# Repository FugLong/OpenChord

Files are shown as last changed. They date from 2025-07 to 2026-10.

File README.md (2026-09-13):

# OpenChord

A family of open hardware instruments for harmony and music-making. MIT licensed. **OpenChord M Core** (plugin) is free; the **OpenChord M1** box is what we sell.

**M-series** is MIDI. **S-series** is studio. Numbers are generations.

| Product | What it is | Status |
|---|---|---|
| **[OpenChord M1](m1/)** | MIDI-only chord brain. RP2040 hardware under $100, plus free **OpenChord M Core** (AU/VST3, same engine). | Active — engine / proto / plugin v0 |
| **[OpenChord S1](s1/)** | Studio / portable jambox: synth, tracks, the original dream device. | Later |
| M2 / S2 | Next generations of each line. | Not started |

```
OPENCHORD          OPENCHORD
    m1                 s1
```

## Repo layout

```
m1/                     M1 engine, firmware, plugin, hardware, docs (start here)
s1/                     Reserved for the jambox when it is real
archive/s1-daisy/       Frozen Daisy Seed prototype (do not treat as S1)
LICENSE                 MIT
```

The Daisy Seed project that used to live at the repo root is intact under [`archive/s1-daisy/`](archive/s1-daisy/). It is a prototype archive, not the S1 codebase.

## Start with M1

Read [`m1/docs/goals.md`](m1/docs/goals.md) for the product plan (hardware + free plugin). Hands-on testing is [`m1/proto-rp2040`](m1/proto-rp2040/) (RP2040-Zero USB MIDI, **Pro** mode). Plugin: [`m1/plugin`](m1/plugin/) (**OpenChord M Core**, Pro + Smart). The archived Seed box is parked. Do not edit the archive.

## License

MIT — see [LICENSE](LICENSE).

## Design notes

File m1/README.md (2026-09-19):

# OpenChord M1

MIDI-only chord brain. Keyboard or DAW in, smarter chords out. **Hardware you buy is M1**; the free DAW plugin is **OpenChord M Core**. Same engine.

This is the first product in the OpenChord family. It does not make sound. The portable synth/jambox is [S1](../s1/), later.

**Read first:** [docs/goals.md](docs/goals.md). Then [docs/testbed.md](docs/testbed.md). Chord model: [docs/chord-engine.md](docs/chord-engine.md). Plugin v0: [docs/plugin.md](docs/plugin.md).

## Naming

| Name | What |
|---|---|
| **OpenChord M1** | Hardware (USB MIDI device). Repo folder `m1/`. |
| **OpenChord M Core** | Free AU MIDI FX + VST3 in `m1/plugin/`. |
| **Pro** | Play mode: keyboard roots + chord-type pads |
| **Smart** | Play mode: pads = I–vii + high I, hold to play |

## Status

Engine is in `m1/engine` (including shared `session`). Feel-testing is **`m1/proto-rp2040`** (Pro). Plugin v0 lives in **`m1/plugin`** as **OpenChord M Core** (Pro + Smart). Product firmware is not started. **Rev A PCB** (4-layer HASL, USB-C J1, TRS J2/J3) is the board being fabbed — [`hardware/bom.md`](hardware/bom.md). The Seed proto is parked. Do not edit the archive.

## Tree

```
m1/
  docs/           goals, testbed, chord-engine
  engine/         portable chord logic (the product)
  proto-rp2040/   RP2040-Zero lab harness (USB-C MIDI, Launchkey pads/knobs)
  proto-daisy/    Seed harness (parked; restore OG from archive)
  plugin/         OpenChord M Core — free AU MIDI FX + VST3. Same engine + session as M1 hardware.
  firmware/       Product RP2040 (later)
  hardware/       PCB, enclosure, KiCad libs (locked touch + connectors in hardware/; Alps C219778 = fallback)
```

`s1/` stays empty. `archive/s1-daisy/` stays frozen.

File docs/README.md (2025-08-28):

# OpenChord Documentation

Welcome to the OpenChord documentation! This project is a portable, open-source music creation device built on the Daisy Seed platform.

## 🎨 3D Enclosure Design (WIP)

<div align="center">
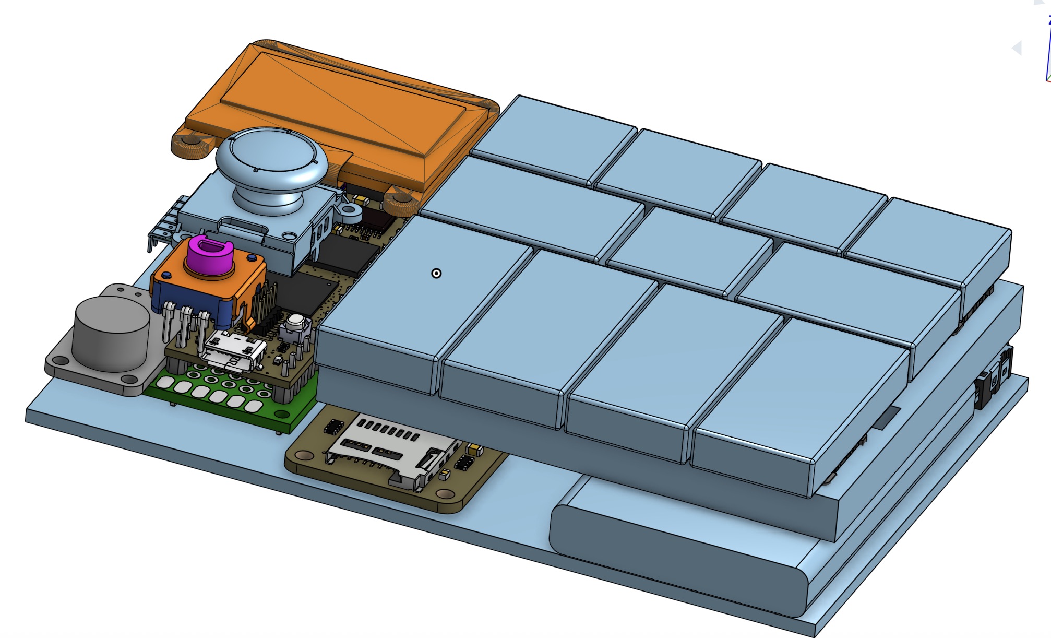
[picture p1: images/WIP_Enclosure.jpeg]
OpenChord 3D Enclosure Design - Work in Progress
  
  <br><br>
  <a href="https://cad.onshape.com/documents/ba31b49b2d69ae60e3c7e665/w/702c47d3131326b0bcdb3b01/e/0e96b76ad6aba8c5e2682321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">
    
  </a>
  <br>
  <em>3D enclosure design in progress - Click the button above to explore the full model</em>
</div>

## 📚 Documentation Structure

### Overview
- **[Project Overview](overview/project_overview.md)** - Complete project description, use cases, features, and more

### Architecture
- **[Firmware Architecture](architecture/firmware_architecture.md)** - Detailed firmware design, track structure, scenes, and plugin system
- **[IO System Architecture](architecture/io_system_architecture.md)** - Comprehensive IO system design and hardware interface management

### Hardware
- **[Pinout Documentation](hardware/pinout.md)** - Detailed pin assignments and hardware connections
- **[Parts List](hardware/partsList.md)** - Complete component list with pricing and purchase links

### Code Organization
- **Co-located Headers**: All header files are now located alongside their corresponding source files
- **Modular Structure**: Clean separation of concerns with dedicated folders for each subsystem

### Development
- **[Development Setup](development/setup.md)** - How to set up your development environment and build the project

## 🎯 Project Goals

- **Portable music creation** - Take your studio anywhere
- **Modular firmware** - Easy to extend and customize
- **Open source** - Community-driven development
- **High-quality audio** - Professional-grade sound processing
- **Intuitive interface** - Consistent, responsive UI

## 📖 Additional Resources

- [Daisy Seed Documentation](https://daisy.audio/)
- [libDaisy GitHub](https://github.com/electro-smith/libDaisy)
- [DaisySP GitHub](https://github.com/electro-smith/DaisySP)

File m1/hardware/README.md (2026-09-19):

# M1 hardware

RP2040 on our PCB, USB-C on the edge. Not a Pico carrier. **Hand-assemble only.** One board, no harnesses.

| Doc | What |
|-----|---|
| [bom.md](bom.md) | Parts + DigiKey/LCSC |
| [support.md](support.md) | Flash / clock / power / USB / MIDI recipe (place before wiring) |
| [switches.md](switches.md) | Gateron LP, direct GPIO (no matrix) |
| [touch.md](touch.md) | Cap strip + trackpad (**IQS572** + **QT2120**) |
| [lib/OLED.md](lib/OLED.md) | OLED pinout / STEP / symbol |
| [lib/TOUCH_ICS.md](lib/TOUCH_ICS.md) | IQS572 + QT2120 EasyEDA/LCSC imports |
| [lib/USB.md](lib/USB.md) | Hroparts TYPE-C-31-M-12 USB-C |
| [lib/TRS.md](lib/TRS.md) | Same Sky SJ1-3523N TRS MIDI |
| [lib/BTN.md](lib/BTN.md) | Panasonic EVQPUC02K edge |
| [lib/MIDI.md](lib/MIDI.md) | Toshiba TLP2361 MIDI IN opto |

Product locks: [`../docs/goals.md`](../docs/goals.md).

## Plan (short)

- **8× Gateron LP** chord pads (hotswap) — mechanical, **one GPIO each** (internal pull-ups; no diodes).
- **IQS572BLQNR** trackpad (color stick XY) + **AT42QT2120** strip only.
- **3× EVQPUC02K** system buttons → GPIO (**roles TBD**). Not capacitive.
- **BOOTSEL** = top tact **TS-1187A** → QSPI_SS through **1 kΩ**, plus **10 kΩ** SS→3V3. No RUN button on rev A.
- Shared **I2C1** on GPIO10/11 (OLED `0x3C`, QT2120 `0x1C`, IQS572 `0x74`; RDY GPIO8, NRST GPIO9). Alps stick = **fallback only**. Pin map: [`support.md`](support.md).
- No SoftPot, no pots, no paid PCBA. Coupon before a later product fab — see [`touch.md`](touch.md).

## Rev A fab (ordering)

| | |
|--|--|
| Size | **118.95 × 63.15 mm** |
| Stack | 4-layer, 1.6 mm, 1 oz. In1 **GND**, In2 **+3.3V**. SMT on **B.Cu**. |
| Finish | **HASL** (not ENIG). Touch = soldermask over copper. |
| Gerbers | [`fab/jlcpcb/`](fab/jlcpcb/) — zip `fab/OpenChordM1-gerbers.zip` (gitignored). Upload that zip. |
| Stencil | **Bottom only**, frameless, custom **160 × 120 mm**, 0.12 mm. No top stencil (`F_Paste` is empty). |
| TRS | SJ1-3523N bushings hang **off** Edge.Cuts so the barrel does not clip FR4. |

## KiCad `lib/`

| Path | Contents |
|---|---|
| `oled.*` | OLED symbol + footprint + STEP ([OLED.md](lib/OLED.md)) |
| `gateron.*` | Gateron LP hotswap ([GATERON.md](lib/GATERON.md)) |
| `easyeda/oc_touch.*` | IQS572 + QT2120 ([TOUCH_ICS.md](lib/TOUCH_ICS.md)) |
| `easyeda/oc_usb.*` | TYPE-C-31-M-12 USB-C ([USB.md](lib/USB.md)); GCT kept in lib |
| `easyeda/oc_trs.*` | Same Sky SJ1-3523N ([TRS.md](lib/TRS.md)) |
| `easyeda/oc_btn.*` | EVQPUC02K edge + TS-1187A BOOT/RUN ([BTN.md](lib/BTN.md)) |
| `easyeda/oc_midi.*` | Toshiba TLP2361 ([MIDI.md](lib/MIDI.md)) |
| `captouch.*` | Generated electrodes (slider/trackpad) — plugin writes here, not into `OpenChordM1/` |
| `lcsc.*` | Alps stick C219778 (**fallback**) |
| `3dshapes/` | OLED STEP |

Nicknames: `oc-oled`, `oc-lcsc`, `oc-gateron`, `oc-touch`, `oc-usb`, `oc-trs`, `oc-btn`, `oc-midi`, `captouch`. RP2040 = KiCad stock `MCU_RaspberryPi` + `Package_DFN_QFN`. Place slider as `captouch:CT_Slider`. Support ICs (flash **W25Q32JVSSIQ** / [C179173](https://www.lcsc.com/product-detail/C179173.html), LDO/ESD/crystal/diode) = KiCad stock — see [`support.md`](support.md).

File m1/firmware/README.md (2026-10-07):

# M1 product firmware

Product RP2040 + TinyUSB MIDI. The rev A image compiles. It has not been flashed and it has not been run: there is no board yet. Do not put this image on an RP2040-Zero. The pins are the product schematic.

`pio run` from this folder builds it. `pio run -t upload` reboots the running board into the ROM bootloader over USB and writes the image. Hold BOOT and plug in if that port is not there.

In this image: USB MIDI named `OpenChord M1`, UART0 MIDI at 31250 on GPIO0 TX / GPIO1 RX (the same notes go out both ports), the eight keyswitches and Prev / Menu / Next (debounced, pressed = low), the IQS572 trackpad and QT2120 strip on the OLED's I2C bus, and the 128×32 OLED drawing the same two lines as the plugin. Flash is the 4 MB W25Q32 with `boot2_w25q080`.

Lab bring-up is [`../proto-rp2040`](../proto-rp2040) on a Zero. The chord logic belongs in `m1/engine`, not here. This folder is the sellable board: USB-C device, UART TRS, Gateron pads, **IQS572** trackpad + **QT2120** strip only, **3× EVQPUC02K** system (roles TBD), OLED. No USB host. No pots. No QT Key/Shift copper. Works with no plugin; the plugin may later push settings over SysEx.

**Match the rev A schematic**, not older docs. Source of truth: [`../hardware/support.md`](../hardware/support.md).

| Bus / pin | As built |
|---|---|
| I²C | **I2C1** on GPIO10 SDA / GPIO11 SCL (not I2C0) |
| OLED / QT / IQS | `0x3C` / `0x1C` / `0x74` on that bus |
| IQS RDY / NRST | GPIO8 / GPIO9 |
| UART0 MIDI | GPIO0 TX / GPIO1 RX @ 31250 |
| Gateron SW1–8 | GPIO 24, 18, 25, 17, 2, 13, 6, 12 |
| EVQ SW9 / SW10 / SW11 | GPIO 4, 5, 3 |
| QT | Slider KEY0–2 only; **CHANGE** unconnected; RESET hard-tied 3V3 |
| BOOTSEL | Not a GPIO — `~QSPI_SS` via R5 1 kΩ; **R30 10 kΩ** SS→3V3 |
| QSPI flash | **W25Q32JVSSIQ** ([C179173](https://www.lcsc.com/product-detail/C179173.html)) 4 MB; `PICO_FLASH_SIZE_BYTES=4*1024*1024`; default `boot2_w25q080` |

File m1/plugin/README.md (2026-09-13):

# OpenChord M Core (plugin)

Free AU MIDI FX + VST3. Same chord engine / session as the **OpenChord M1** hardware. MIDI in → chords out. No audio.

| Name | What |
|---|---|
| **OpenChord M1** | Hardware box (USB MIDI device) |
| **OpenChord M Core** | This free plugin |

**Spec:** [`../docs/plugin.md`](../docs/plugin.md)

## License note

Plugin source is MIT-intended like the rest of the repo. JUCE is fetched via CMake and is GPL/AGPLv3 unless you have a commercial JUCE license. Distributing a binary built this way requires GPL-compatible terms for that binary (or a JUCE license). Source here stays usable either way.

## Build (macOS)

Needs CMake ≥ 3.22, a C++17 compiler, and network once to FetchContent JUCE 8.

```bash
cd m1/plugin
cmake -B build -G Ninja -DCMAKE_BUILD_TYPE=Release
cmake --build build
```

Xcode generator also works: `-G Xcode`.

`COPY_PLUGIN_AFTER_BUILD` installs into:

| Format | Path |
|---|---|
| AU | `~/Library/Audio/Plug-Ins/Components/OpenChord M Core.component` |
| VST3 | `~/Library/Audio/Plug-Ins/VST3/OpenChord M Core.vst3` |

Standalone: `build/OpenChordMCore_artefacts/Release/Standalone/OpenChord M Core.app` (path may vary by generator).

Rescan plugins in Logic / Reaper after the first build. If you previously installed an older **OpenChord M1** plugin bundle, remove it from those folders so only M Core remains.

## Logic (AU MIDI FX)

1. Instrument track → any synth.
2. MIDI FX slot → **OpenChord M Core**.
3. Route Launchkey (or other controller) to this track only.
4. Default map = Launchkey Mini MK4 (pads CC 36–43, stick CC 47/48). Hold Maj, play C → C major. No Type → thru.

## VST3 (Reaper / Ableton / etc.)

VST3 has no MIDI-FX type. This plugin is a silent instrument that outputs MIDI.

- **Reaper:** can use it as MIDI FX on a track.
- **Ableton:** put OpenChord M Core on a MIDI track, set the synth track’s MIDI From to that track (“MIDI To” routing). Do not expect an AU-style MIDI FX slot.

## MIDI Learn

Click a control (short click), then press the pad or move the knob. Binding stores in plugin state with the session. Hold a button to play Type/extra with the mouse. Right-click clears. **Reset map** restores Launchkey defaults. Esc cancels learn.

## Layout

```
m1/plugin/          This JUCE project (OpenChord M Core)
m1/engine/          chord_engine + session (compiled into the plugin; shared with M1 hardware)
```

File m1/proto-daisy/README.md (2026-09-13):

# M1 Seed proto harness

Throwaway firmware for the **original OpenChord box** (Daisy Seed, 11 keys, stick, OLED, USB MIDI). Implements the **new** M1 design on that hardware:

- Incoming USB MIDI note = **root** (**Type** mode; Degree is later)
- Eight chord keys = triad + extras (not I–vii)
- Stick = voicing / in-key color, spring-back HOME
- Chords go back out USB MIDI to the DAW

Pins: [`pin_map.h`](pin_map.h), copied from the archive **drivers**, not `pin_config.h`. **Must not modify `archive/s1-daisy/`.** Restore the OG synth from that archive when this harness is done.

See [docs/testbed.md](../docs/testbed.md) and [docs/chord-engine.md](../docs/chord-engine.md).

## Buttons

| Where | M1 |
|---|-----|
| Bottom 4 | Dim, Min, Maj, Sus |
| Middle 3 | 6, m7, M7 |
| Top INPUT | 9 |
| Top INSTRUMENT | **Key** (hold + a MIDI note sets the key) |
| Top FX | Shift (unused in this build) |
| Top RECORD | panic (CC 123) |

Hold a type, play a note on the keyboard. No type = that note **thrus**. Type + note = chord **replaces** the root (the root is not echoed). Stick lean updates the sounding chord live.

## Build

Daisy toolchain (`arm-none-eabi-gcc`) and libDaisy submodule:

```bash
git submodule update --init archive/s1-daisy/lib/libDaisy
cd m1/proto-daisy
make
```

Binary: `m1/proto-daisy/build/OpenChordM1.bin`

This image is `BOOT_QSPI` so the box's existing USB-stick bootloader can load it.

## Flash (USB stick, same as OG)

The enclosure USB-C is **EXTERNAL** Seed pins 36–37 (`D29`/`D30`). The bootloader looks for a file named `OpenChord.bin`.

```bash
cd m1/proto-daisy
make
./flash_usb.sh "/Volumes/YOURSTICK"
```

Eject the stick, plug it into the **box** USB-C, power cycle. Do not use the Seed's tiny onboard USB for MIDI — that is not the port this firmware listens on.

## Play it

PC is USB host. After flashing, plug the **box USB-C** into the PC. The device should show up as USB MIDI (Daisy name).

Route:

1. Keyboard → DAW/router **into OpenChord** (not also onto the instrument track)
2. OpenChord MIDI out → the instrument / MIDI track

Hold Min, play C on the keyboard → Cm out. Lean the stick for inversion / in-key color. Hold Key + a note to set `C major` etc.

RECORD = all notes off. Restore OG firmware from `archive/s1-daisy` when you are done.

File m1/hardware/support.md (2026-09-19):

# M1 support circuit — as built (rev A schematic)

Companion to [`bom.md`](bom.md). **Source of truth is the KiCad schematic.** This file matches that netlist.

Paths: `OpenChordM1/OpenChordM1.kicad_sch` · `OpenChordM1.kicad_pcb`.

---

## Completeness (on schematic)

| Block | On sch |
|---|---|
| MCU | RP2040 |
| Boot flash | W25Q32JVSSIQ ([C179173](https://www.lcsc.com/product-detail/C179173.html)) QSPI |
| Clock | ABM8-272-T3 + 15 pF ×2 + 1 kΩ on XOUT |
| 3V3 | AP2112K-3.3, EN tied to VIN; 10 µF in/out |
| USB | J1 TYPE-C-31-M-12 ([C165948](https://www.lcsc.com/product-detail/C165948.html)) + USBLC6 + 22 Ω + CC 5.1 kΩ→GND |
| MIDI OUT | Type A: 33 Ω (3V3→Tip), 10 Ω (TX→Ring) |
| MIDI IN | TLP2361 + 220 Ω + 1N4148 + 100 nF |
| Touch | IQS572 + QT2120 + electrodes |
| Display | OLED 0.91" I²C |
| Keys | 8× Gateron LP → GPIO |
| System btns | EVQPUC02K ×3 → GPIO (**roles TBD**) |
| BOOTSEL | TS-1187A + 1 kΩ to `~QSPI_SS`; **10 kΩ pull-up SS→3V3** |
| RUN pin | 10 kΩ → 3V3 (no RUN button on rev A) |
| I²C | **I2C1** GPIO10/11, 4.7 kΩ ×2 |
| RP2040 ties | VREG 1 µF ×2; IO/DVDD 100 nF; **TESTEN→GND**; ADC_AVDD→3V3 |

**Not on rev A:** second USB-C, Alps stick, RUN tact, QT2120 Key/Shift copper, CHANGE GPIO.

**3× EVQ** = system buttons → GPIO. **BOOTSEL** = top tact `TS-1187A-B-A-B` (not the edge PUC). QT2120 SNS is strip only (KEY0–2). Do not wire SNS to buttons.

---

## 1. Power

```
USB VBUS ──► AP2112K VIN ──► +3V3 ──► RP2040 IOVDD / USB_VDD / VREG_IN / ADC_AVDD
                 EN ← VIN                 flash, OLED, QT2120, IQS572 VDDHI, TLP2361 VCC
```

| Cap | Where |
|-----|---|
| C10 10 µF | VBUS at LDO in |
| C11 10 µF | 3V3 at LDO out |
| C8 **1 µF** | RP2040 **VREG_OUT** → both **DVDD** (not 3V3) |
| C9 **1 µF** | RP2040 **VREG_IN** / 3V3 |
| C1, C3–C6, C14 100 nF | 3V3 local (MCU / flash / QT / OLED / opto) |
| C2 **1 µF** | IQS572 **VDDHI** → GND |
| C7 **1 µF** | IQS572 **VREG** (internal regulator **output**) → GND only — not tied to 3V3 |

**TESTEN → GND.**

---

## 2. Crystal

**ABM8-272-T3** on XIN/XOUT: C12/C13 15 pF C0G to GND; **R7 1 kΩ** series on XOUT.

---

## 3. QSPI flash

`W25Q32JVSSIQ` (LCSC [C179173](https://www.lcsc.com/product-detail/C179173.html), SOIC-8 208 mil) → QSPI_SS / SCLK / SD0–3. Same pads/pinout as the 16 Mbit parts. IQ = Quad Enable factory-set (needed for RP2040). Default Pico SDK `boot2_w25q080`. Waveshare RP2040-Plus 4 MB ships this exact MPN. Firmware: `PICO_FLASH_SIZE_BYTES=4*1024*1024`. Do not buy leftover 16 Mbit JV (`W25Q16JVSSIQ` / C131025).

| Ref | Value | Net |
|-----|---|-----|
| **R30** | **10 kΩ** | `~QSPI_SS` → 3V3 (always populated) |
| **R5** | **1 kΩ** | `~QSPI_SS` → SW13 pad 3 |
| **SW13** | TS-1187A | pad 1 → GND; pad 3 → R5. Commons are **top 1+2 / bottom 3+4**. Pads 2 and 4 NC on sch. |

**RUN:** R6 10 kΩ → 3V3. No RUN button.

---

## 4. USB (one port)

**J1** Hroparts `TYPE-C-31-M-12` ([C165948](https://www.lcsc.com/product-detail/C165948.html)) on **B.Cu**, board edge. Per [`lib/USB.md`](lib/USB.md): DP1↔DP2, DN1↔DN2; **USBLC6**; **R3/R4 22 Ω**; CC **R1/R2 5.1 kΩ→GND** (do not tie CC1 to CC2); VBUS→LDO; SBU NC.

---

## 5. MIDI Type A

[`lib/TRS.md`](lib/TRS.md) + [`lib/MIDI.md`](lib/MIDI.md). UART0: **GPIO0 TX / GPIO1 RX**.

**OUT (J2):** Tip ← R12 33 Ω ← 3V3; Ring ← R11 10 Ω ← TX; Sleeve GND.

**IN (J3 + U9 TLP2361):** Tip → R10 220 Ω → AN; Ring → CAT; VO → RX; VCC=3V3 + C14 100 nF; D1 1N4148 reverse across LED.

Place the jacks so the **metal bushing is past Edge.Cuts** (plastic body + pins on FR4). Boss holes are mechanical, no net.

---

## 6. I²C — **I2C1** (not I2C0)

RP2040 mux: **GPIO10 = I2C1 SDA**, **GPIO11 = I2C1 SCL**. Firmware must use **I2C1**.

| Device | Address | Notes |
|---|---|---|
| OLED DS1 | `0x3C` | Module must be **GND / VCC / SCL / SDA** |
| QT2120 U4 | `0x1C` | MODE→GND, RESET→3V3, CHANGE open |
| IQS572 U3 | `0x74` | **RDY → GPIO8** (required); **NRST → GPIO9** |

Pull-ups **R8/R9 4.7 kΩ** to 3V3.

---

## 7. Touch series R

| Ref | Value | Net |
|-----|---|-----|
| **R13–R15** | **10 kΩ** | QT2120 KEY0–2 ↔ strip E1–E3 |
| **R16–R29** | **1 kΩ** | IQS572 Rx0–6 / Tx0–6 ↔ trackpad silk Rx1–7 / Tx1–7 |

Unused IQS Rx7 / Tx7 / Tx8 and unused QT KEY3–11 left open.

Keepout on internal planes covers **sense** copper (KEY0–2 / trackpad diamonds). Slider **GND end chevrons** (U2 pads 4–5) may sit outside keepout on purpose.

---

## 8. GPIO map (live schematic)

| GPIO | Function |
|---|---|
| 0 | MIDI OUT UART0 TX |
| 1 | MIDI IN UART0 RX |
| 2 | SW5 Gateron |
| 3 | SW11 EVQ |
| 4 | SW9 EVQ |
| 5 | SW10 EVQ |
| 6 | SW7 Gateron |
| 7 | unused |
| 8 | IQS572 RDY |
| 9 | IQS572 NRST |
| 10 | I2C1 SDA |
| 11 | I2C1 SCL |
| 12 | SW8 Gateron |
| 13 | SW6 Gateron |
| 14–16 | unused |
| 17 | SW4 Gateron |
| 18 | SW2 Gateron |
| 19–23 | unused |
| 24 | SW1 Gateron |
| 25 | SW3 Gateron |
| 26–29 | open (ADC spare / Alps fallback) |

Gateron / EVQ: one pole → GPIO (MCU internal pull-up), other → GND. Pressed = low.

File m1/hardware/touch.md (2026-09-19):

# M1 capacitive front panel (**locked**)

Locks / fallbacks: [`../docs/goals.md`](../docs/goals.md). Parts: [`bom.md`](bom.md).

## Locked ICs

| Role | MPN | DigiKey | Pkg | Bus |
|---|-----|---|-----|-----|
| **Trackpad** (color stick) | **IQS572BLQNR** | [7165004](https://www.digikey.com/en/products/detail/azoteq-pty-ltd/IQS572BLQNR/7165004) | QFN-28 **4×4** (**0.5 mm** pitch) | I²C **`0x74`**, needs **RDY** GPIO |
| **Strip** (strum / sparkle) | **AT42QT2120-XUR** | [XUR](https://www.digikey.com/en/products/detail/microchip-technology/AT42QT2120-XUR/3678735) (TSSOP-20, tape/reel — prefer) · [MMHR](https://www.digikey.com/en/products/detail/microchip-technology/AT42QT2120-MMHR/3678733) (VQFN-20 alt) | same die | I²C **`0x1C`** |

**One of each.** Not 2× QT2120. IQS572 = XY trackpad. QT2120 = **strip only** (SNS0–2). System buttons = mechanical EVQ → GPIO (**roles TBD**) — not capacitive.

Addresses differ → **OLED (`0x3C`) + QT2120 + IQS572 share I2C1** (GPIO10 SDA / GPIO11 SCL). Pull-ups once (**R8/R9 4.7 kΩ**). IQS572 **RDY → GPIO8** (required). **NRST → GPIO9**. QT2120 **CHANGE** is open (poll I²C).

Fall back: Alps stick (C219778) if trackpad feel fails. Chord pads stay **Gateron LP**. System buttons stay EVQ.

---

## What each chip does

### IQS572 — trackpad (stick)

Mutual-cap **Tx columns + Rx rows**. Copper = diamond matrix from the captouch plugin (or hand layout per Azoteq AZD068). Chip outputs **XY** (+ gestures) over I²C. Firmware maps position → **8 color seats + HOME** (center / no-touch deadzone). Up to **9×8** channels; use a small stick-sized grid (e.g. 5×4 / 6×5), leave unused Tx/Rx unconnected per datasheet rules.

### AT42QT2120 — strip only

Self-cap. **Slider** on SNS0–2 = three interleaved electrodes → continuous **0–255** (strum / sparkle). Unused SNS left open. System buttons are **not** on this chip.

```
Finger → cover opening + soldermask (rev A HASL; not ENIG)
  trackpad diamonds → Tx/Rx (+ 1 kΩ R16–R29) → IQS572 → I2C1 → RP2040
  strip triangles    → SNS0–2 (+ 10 kΩ R13–R15) → QT2120 → I2C1 → RP2040
  3× system EVQ      → GPIO (roles TBD)
```

## Soldermask vs gold

| Finish | Look | Fab |
|---|---|-----|
| **HASL + mask over pads** (rev A proto) | Pad-shaped bumps in board color | What we ordered |
| **ENIG + mask open** | Gold frets / pad outlines | Later SKU only if feel needs gold |

## Cover

3D-printed cover with openings over **trackpad** and **strip**. System EVQs get their own openings (not copper pads).

## Layout notes

- Keepout under **sense** copper on internal GND/PWR planes; ground pour around (not under) electrodes. Slider **GND end chevrons** (U2 pads 4–5) may sit outside keepout so parts can share that area — that is intentional.
- IQS572 and QT2120 **close** to their electrodes; short sense traces; **series R on every sense line**:
  - Strip: **R13–R15 10 kΩ** (QT2120 datasheet Rs 4.7–20 kΩ)
  - Trackpad 7×7: **R16–R29 1 kΩ** — electrode silk Rx1–7/Tx1–7 → chip **Rx0–6 / Tx0–6** (Rx7, Tx7, Tx8 NC)
- Decoupling: IQS572 **C2 1 µF on VDDHI**, **C7 1 µF on VREG** (VREG is the internal regulator output — cap to GND only). Optional 100 pF across C7 skipped on rev A.
- IQS572 is **NRFND** at Azoteq but DigiKey-stocked — acceptable for M1; do not redesign around vaporware 7211E.

---

## Eval / breakouts (buy before fab)

### IQS572 (preferred → fallback)

1. **Official:** [IQS572EV02](https://www.azoteq.com/product/iqs572-b000/) Arduino-shield trackpad (8×8) — order from Azoteq / Seltech if DigiKey empty. Pair with **CT210A** or **DS200** USB streamer + [IQS5xx-B000 GUI](https://www.azoteq.com/).
2. **Ready module (best buy):** [TPS43-201A-S](https://www.digikey.com/en/products/detail/azoteq-pty-ltd/TPS43-201A-S/7164940) — 43×40 mm pad with **IQS572 on board** (FPC). Wire to Zero; prove XY + seat mapping before any coupon.
3. **DIY chip on adapter:** only if you cannot get TPS43/EV02 — need a **QFN-28 4×4 / 0.5 mm → DIP** adapter (not 0.4 mm; Chip Quik **IPC0042 is 0.4 mm and wrong**). Prefer coupon with the IC soldered direct.

### AT42QT2120

1. **[Touchy Subject](https://www.lectronz.com/products/touchy-subject)** — Qwiic/STEMMA QT2120 breakout (hand-solderable TSSOP design; open source).
2. **Zio Qwiic AT42QT2120** (Smart Prototyping) — module + optional wheel/key panels.
3. **DIY:** buy **AT42QT2120-XUR** (TSSOP-20), dead-bug or TSSOP→DIP adapter onto a strip coupon. Product PCB can still use MMHR if preferred.

### Host for bring-up

RP2040-Zero (`m1/proto-rp2040`) or Arduino Uno (EV02 shield). Log XY / slider / keys over USB serial before trusting the product board.

---

## Pre-fab testing (expensive PCBs — earn one fab)

Cap copper is easy to draw and easy to **feel** wrong (dead zones, palm hits, jitter, cover air gap). Treat feel as a **coupon problem**, not a full-board problem.

### Phase 0 — silicon + software (no custom PCB)

| Test | How | Pass |
|---|-----|---|
| IQS572 talks | EV02 / TPS43 / adapter → I2C `0x74`, RDY polled, XY streams | Stable XY at 3.3 V |
| QT2120 talks | Breakout → I2C `0x1C`, slider 0–255, keys debounce | Clean lift/touch |
| Stick mapping | Firmware: XY → polar or 8 seats + HOME deadzone | Matches gesture lock in goals |
| Strip mapping | Slider → strum / sparkle | Useful in Smart; no stuck values |

### Phase 1 — **cheap coupons** (JLCPCB ~$5–15, 2–5 pcs)

Order **tiny boards**, not the product:

1. **Trackpad coupon:** IQS572 footprint + diamond matrix sized like the final stick + cover stack (same overlay thickness you will ship) + I2C/RDY header to Zero.
2. **Strip coupon:** QT2120 + interleaved strip + cover opening (no Key/Shift copper).
3. Optional: one **combo coupon** (both ICs) once each alone passes.

Sweep **one variable per coupon** if possible: pitch / overlay / mask-vs-ENIG. Do **not** change five things between fabs.

### Phase 2 — checklist before product Gerbers

- [ ] Trackpad: all seats reachable; HOME center reliable; no palm on rim while resting hand
- [ ] Strip: end-to-end travel; no dead third; works with intended cover
- [ ] System EVQs: clean GPIO presses; no ghost with trackpad palm
- [ ] EMI: USB plugged, MIDI TRS connected, OLED on — touch still stable
- [ ] I2C: OLED + both touch ICs on one bus at once (addr `0x3C` / `0x1C` / `0x74`)
- [ ] Power: brown-out / plug cycle; IQS572 RDY still sane after reset
- [ ] Mechanical: cover openings align; finger never on bare copper; edge buttons reachable
- [ ] Alps stick footprint DNP fallback still OK if trackpad fails

### Phase 3 — product PCB

Only after Phase 1–2 pass. First product fab is **assembly + layout** risk (USB, TRS, Gateron, RP2040), not “will capacitive touch exist.”

**Truth:** you will not get “zero respins” by staring at KiCad. You get close by **paying for coupons** and freezing electrode geometry before the big board.

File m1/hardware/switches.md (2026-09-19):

# M1 switches — Gateron LP, direct GPIO

Parts: [`bom.md`](bom.md). Feel: [`../docs/goals.md`](../docs/goals.md). Cap front: [`touch.md`](touch.md).

## Socket family

**Gateron LP KS-27 / KS-33** only (2 electrical pins). **Not** MX (CPG1511). **Not** Choc. Sockets from Gateron / keeb shops — not DigiKey.

KS-27 and KS-33 share a compatible footprint. Wrong family = scrap board.

## Stack-up

```
[keycap] [LP switch]  ← press from top
[plate]
── PCB top ──  NPTH for legs
── PCB bottom ──  LP hotswap socket (SMD)
```

Solder sockets on the **bottom**. Press switches in after plate. Coupon 1–2 keys before full fab.

Footprints **in-repo** (ai03 MX_V2, MIT): see [`lib/GATERON.md`](lib/GATERON.md).

- Schematic: **`oc-gateron:SW_Gateron_LP`**
- PCB: **`oc-gateron:Gateron-KS33-Hotswap-1U`** — then **flip** so socket is on **B.Cu** (bottom)
- Backup solder-only: `Gateron-KS33-Solderable-1U`
- 3D: socket + switch (`Gateron-KS33-Socket.step`, `Gateron-KS33-Switch.step`) — see [`lib/GATERON.md`](lib/GATERON.md)

## Wiring — direct GPIO (no matrix)

Eight pads → **eight GPIOs**. One switch pin → GPIO, other → GND.

- Enable **internal pull-up** on each key GPIO (~50–80 kΩ on RP2040). No external pull-up resistors.
- Pressed = low. Firmware debounce.
- **No diodes** — ghosting is a matrix problem; each key has its own line.
- Multi-hold works.

**3× system EVQPUC02K** → GPIO (internal pull-up). Roles **TBD** — not capacitive, not Gaterons. **BOOTSEL** is a separate strap on QSPI_SS (see [`support.md`](support.md)).

### Pad map (firmware)

| Pad | Pro | Smart |
|-----|-----|---|
| 0–3 | Dim Min Maj Sus | I ii iii IV |
| 4–7 | 6 m7 M7 9 | V vi vii I↑ |

Physical layout is still a **2×4** cluster; numbering is firmware-defined.

### GPIO map (rev A schematic)

See [`support.md`](support.md) §8 for the full table. Firmware must use **I2C1** (GPIO10/11), not I2C0.

| Function | GPIO |
|---|---|
| KEY (SW1–8 Gateron) | 24, 18, 25, 17, 2, 13, 6, 12 |
| SYS (SW9, SW10, SW11 EVQ) | 4, 5, 3 |
| I2C1 SDA/SCL | 10 / 11 — OLED `0x3C` + QT2120 strip @ `0x1C` + IQS572 @ `0x74` |
| IQS572_RDY / NRST | 8 / 9 |
| UART0 TX/RX (MIDI) | 0 / 1 |
| BOOTSEL | **Not a GPIO** — TS-1187A + **R5 1 kΩ** on **QSPI_SS**, **R30 10 kΩ** SS→3V3 |
| STICK_X/Y | **Only if Alps fallback** — ADC on GPIO26–29 |

QT2120 **CHANGE** is unconnected. Spare: GPIO7, 14–16, 19–23.

## Layout

2×4 left-hand cluster; thumb **trackpad** (or Alps stick fallback); touch **strip** on a free edge; **3× system EVQs** (roles TBD); USB-C on edge; TRS rear/side; bottom keepout for case.

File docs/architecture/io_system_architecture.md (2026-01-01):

# OpenChord IO System Architecture

[← Back to Documentation](../README.md)

## Overview

This document outlines the IO system architecture for OpenChord, designed to handle all hardware components in a clean, modular, and maintainable way. The system follows Daisy Seed best practices and provides a unified interface for all input/output operations.

## Design Principles

1. **Modularity**: Each IO component type is handled by a dedicated manager class
2. **Unified Interface**: Common patterns for all input types (digital, analog, serial)
3. **Daisy-Native**: Leverages Daisy Seed's built-in peripherals and patterns
4. **Performance**: Efficient polling and interrupt-driven approaches where appropriate
5. **Extensibility**: Easy to add new IO components without breaking existing code
6. **Error Handling**: Robust error detection and recovery for hardware issues
7. **Centralized Configuration**: All pin assignments defined in one place (`pin_config.h`)

## System Architecture

```
┌─────────────────────────────────────────────────────────────┐
│                    IO Manager (Main Coordinator)            │
├─────────────────────────────────────────────────────────────┤
│  ┌─────────────┐ ┌─────────────┐ ┌─────────────┐ ┌─────────┐ │
│  │   Digital   │ │   Analog    │ │   Serial    │ │ Display │ │
│  │   Manager   │ │   Manager   │ │   Manager   │ │ Manager │ │
│  └─────────────┘ └─────────────┘ └─────────────┘ └─────────┘ │
├─────────────────────────────────────────────────────────────┤
│  ┌─────────────┐ ┌─────────────┐ ┌─────────────┐ ┌─────────┐ │
│  │   Storage   │ │   Audio     │ │   MIDI      │ │   UI    │ │
│  │   Manager   │ │   Manager   │ │   Manager   │ │ Manager │ │
│  └─────────────┘ └─────────────┘ └─────────────┘ └─────────┘ │
└─────────────────────────────────────────────────────────────┘
```

## Component Managers

### 1. Digital IO Manager
Handles all digital inputs and outputs including buttons, encoder, and control signals.

**Components:**
- **Key Matrix (4x3)**: 11 keys using 7 pins (4 rows, 3 columns)
- **Rotary Encoder**: 2 pins for quadrature, 1 for button (optional)
- **Joystick Button**: 1 pin for digital input
- **Audio Input Switch**: 1 pin for TRS/line input selection
- **Status LEDs**: 4 pins for visual feedback (if implemented)

**Features:**
- Matrix scanning with debouncing
- Encoder quadrature decoding with acceleration
- Button state tracking (pressed, held, released)
- LED brightness control via PWM

### 2. Analog IO Manager
Handles all analog inputs including potentiometers, joystick axes, and sensors.

**Components:**
- **Volume Potentiometer**: ADC0 (Pin 22)
- **Joystick X-Axis**: ADC2 (Pin 24)
- **Joystick Y-Axis**: ADC3 (Pin 25)
- **Microphone Input**: ADC1 (Pin 23)
- **Battery Monitor**: ADC4 (Pin 26)

**Features:**
- Automatic ADC configuration and calibration
- Noise filtering and smoothing
- Calibration for joystick dead zones
- Battery voltage monitoring with low-battery detection
- Self-initialization using centralized pin configuration

### 3. Serial IO Manager
Handles all serial communication including MIDI, display, and storage.

**Components:**
- **SPI Display**: Pins 8-11 (SPI1)
- **SD Card**: Pins 2-7 (SDMMC1)
- **UART MIDI**: Pins 12-13 (UART4)

**Features:**
- SPI display driver with double buffering
- SD card file system management
- MIDI UART with proper timing
- Error handling and recovery

### 4. Display Manager
Specialized manager for the OLED display with advanced UI features.

**Features:**
- Double buffering for smooth animations
- Font rendering and text layout
- Graphics primitives (lines, circles, rectangles)
- UI state management
- Plugin-driven custom displays

### 5. Storage Manager
Handles SD card operations and file management.

**Features:**
- File system abstraction
- Audio file I/O
- Configuration storage
- Project file management
- Error recovery and corruption detection

## Implementation Strategy

### Phase 1: Core Infrastructure
1. **IO Manager Base Class**: Abstract interface for all managers
2. **Digital Manager**: Button matrix, encoder, basic digital I/O
3. **Analog Manager**: ADC setup, basic analog reading
4. **Error Handling**: Centralized error reporting and recovery

### Phase 2: Communication Systems
1. **Serial Manager**: SPI, UART, and SDMMC initialization
2. **Display Manager**: Basic OLED driver and text rendering
3. **Storage Manager**: SD card initialization and basic file operations

### Phase 3: Advanced Features
1. **Enhanced Digital**: LED control, advanced button features
2. **Enhanced Analog**: Calibration, filtering, advanced processing
3. **UI Integration**: Plugin-driven display system
4. **Performance Optimization**: Interrupt-driven updates where possible

## Class Structure

### IO Manager (Main Coordinator)
```cpp
class IOManager {
public:
    // Core lifecycle
    void Init(daisy::DaisySeed* hw);
    void Update();
    void Shutdown();
    
    // Manager access
    DigitalManager* GetDigital() { return digital_; }
    AnalogManager* GetAnalog() { return analog_; }
    SerialManager* GetSerial() { return serial_; }
    DisplayManager* GetDisplay() { return display_; }
    StorageManager* GetStorage() { return storage_; }
    
    // System status
    bool IsHealthy() const;
    const SystemStatus& GetStatus() const;
    
private:
    DigitalManager* digital_;
    AnalogManager* analog_;
    SerialManager* serial_;
    DisplayManager* display_;
    StorageManager* storage_;
    SystemStatus status_;
};
```

### Digital Manager
```cpp
class DigitalManager {
public:
    // Key matrix
    bool IsKeyPressed(int row, int col) const;
    bool WasKeyPressed(int row, int col) const;
    const KeyMatrixState& GetKeyMatrix() const;
    
    // Encoder
    int GetEncoderValue() const;
    float GetEncoderDelta() const;
    bool IsEncoderButtonPressed() const;
    
    // Joystick button
    bool IsJoystickButtonPressed() const;
    bool WasJoystickButtonPressed() const;
    
    // Audio switch
    bool IsAudioInputSwitched() const;
    
    // LEDs
    void SetLED(int led, bool state);
    void SetLEDBrightness(int led, float brightness);
    
private:
    KeyMatrix key_matrix_;
    Encoder encoder_;
    Button joystick_button_;
    Button audio_switch_;
    LEDArray leds_;
};
```

### Analog Manager
```cpp
class AnalogManager {
public:
    // Volume control
    float GetVolume() const;
    float GetVolumeNormalized() const;
    
    // Joystick
    void GetJoystick(float* x, float* y) const;
    float GetJoystickX() const;
    float GetJoystickY() const;
    
    // Microphone
    float GetMicrophoneLevel() const;
    bool IsMicrophoneClipping() const;
    
    // Battery
    float GetBatteryVoltage() const;
    float GetBatteryPercentage() const;
    bool IsLowBattery() const;
    
    // Calibration
    void CalibrateJoystick();
    void CalibrateVolume();
    
private:
    daisy::AdcChannelConfig adc_configs_[5];
    AnalogInput volume_;
    AnalogInput joystick_x_;
    AnalogInput joystick_y_;
    AnalogInput microphone_;
    AnalogInput battery_;
};
```

## Pin Assignment Summary

| Function | Daisy Pin | STM32 Pin | Manager | Notes |
|---|---|---|---|---|
| **Key Matrix** | 27-33 | Various | Digital | 4x3 matrix, 7 pins |
| **Encoder** | 34-35 | Various | Digital | Quadrature A/B |
| **Joystick Button** | 14 | PB6 | Digital | GPIO input |
| **Audio Switch** | 15 | PB7 | Digital | GPIO input |
| **Volume Pot** | 22 | PC0 | Analog | ADC0 |
| **Joystick X** | 24 | PB1 | Analog | ADC2 |
| **Joystick Y** | 25 | PA7 | Analog | ADC3 |
| **Microphone** | 23 | PA3 | Analog | ADC1 |
| **Battery** | 26 | PA6 | Analog | ADC4 |
| **Display SPI** | 8-11 | Various | Serial | SPI1 |
| **SD Card** | 2-7 | Various | Serial | SDMMC1 |
| **MIDI UART** | 12-13 | PB8-PB9 | Serial | UART4 |

## Error Handling Strategy

### Hardware Fault Detection
- **ADC Failures**: Detect out-of-range values, implement fallback values
- **Digital Glitches**: Debouncing, state validation, error counters
- **Communication Errors**: Timeout detection, retry mechanisms
- **Storage Issues**: Corruption detection, backup/restore mechanisms

### Recovery Mechanisms
- **Automatic Retry**: Configurable retry counts for transient failures
- **Fallback Modes**: Degraded operation when components fail
- **User Notification**: Clear error messages and status indicators
- **Logging**: Persistent error logs for debugging

## Performance Considerations

### Update Frequencies
- **Digital I/O**: 1kHz (1ms) for responsive button handling
- **Analog I/O**: 100Hz (10ms) for smooth control response
- **Display**: Adaptive refresh rate for power optimization:
  - **Idle**: 1Hz (1s) - minimal updates for power savings
  - **Low**: 2Hz (500ms) - reduced updates during low activity
  - **Normal**: 10Hz (100ms) - standard UI updates (sufficient for smooth operation)
  - **Active**: 20Hz (50ms) - responsive updates during user interaction
- **Storage**: On-demand for file operations
- **MIDI**: Real-time for low-latency performance

**Note**: Display refresh rates are optimized for battery-powered operation. The adaptive system balances visual quality with power consumption, automatically adjusting based on system activity.

### Memory Management
- **Static Allocation**: Pre-allocate buffers to avoid fragmentation
- **Pool Management**: Efficient memory pools for dynamic objects
- **Cache Optimization**: Minimize memory access patterns
- **DMA Usage**: Use DMA for SPI and audio operations where possible

## Integration with Other Systems

### Audio System
The IO system provides volume control and other analog inputs to the audio engine. The `VolumeManager` coordinates between the `AnalogManager` and `AudioEngine` to provide sophisticated volume scaling.

### MIDI System
Digital inputs (key matrix, encoder) and analog inputs (joystick) can be mapped to MIDI control changes, notes, and other musical events.

### Plugin System
The IO system is designed to integrate with a plugin architecture, allowing plugins to:
- Register custom input handlers
- Define custom control mappings
- Create custom UI displays
- Handle specialized hardware

## Conclusion

This IO system architecture provides a solid foundation for OpenChord's hardware interface needs. The modular design ensures maintainability and extensibility while following Daisy Seed best practices. The phased implementation approach allows for incremental development and testing, ensuring each component is robust before moving to the next phase.

The system is designed to handle all current hardware requirements while providing clear paths for future enhancements and plugin integration.

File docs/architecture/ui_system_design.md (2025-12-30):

# UI System Design

[← Back to Documentation](../README.md)

## Overview

The OpenChord UI system provides a consistent, modular interface for navigating settings, viewing information, and controlling the device. It follows a layered approach with a permanent system bar and plugin-driven content area.

## Core Principles

1. **Always-visible system information** - Battery, track, active plugin/context shown in persistent bars
2. **Plugin-driven content** - Plugins can render their own UI in the content area
3. **Consistent navigation** - Same controls work across all contexts
4. **Modal settings access** - Quick access to plugin settings without leaving performance mode
5. **Clean separation** - System UI (bars) vs Content UI (plugin-driven)

## UI Layout

```
┌─────────────────────────────────────┐
│ SYSTEM BAR (permanent, always on)   │  ← Battery %, Track name, Current context
├─────────────────────────────────────┤
│                                     │
│                                     │
│    CONTENT AREA                     │  ← Plugin-driven or system UI
│    (128x48 pixels)                  │  ← Can be controlled by any plugin
│                                     │
│                                     │
├─────────────────────────────────────┤
│ STATUS BAR (optional, contextual)   │  ← Additional info, hints, shortcuts
└─────────────────────────────────────┘
```

**Display specs:**
- Total: 128x64 pixels (OLED SSD1306)
- System Bar (top): 128x8 pixels (1 line)
- Content Area: 128x48 pixels
- Status Bar (bottom): 128x8 pixels (optional, contextual)

## System Bars

### Top System Bar (Always Visible)

Displays:
- **Left**: Battery percentage (e.g., "85%") or charging indicator
- **Center**: Current track name/number (e.g., "Track 1" or "Chord Mode")
- **Right**: Current context/mode indicator
  - Normal: "-" or empty
  - Settings mode: "SETTINGS" or plugin name
  - Menu mode: "MENU"
  - Debug: "DEBUG"

### Bottom Status Bar (Contextual)

Only shows when relevant:
- Navigation hints: "↑↓ nav  ◄► change"
- Active plugin name: "Chord Mapping"
- Parameter value: "Key: C Major"
- Empty in normal operation mode

## UI States / Modes

### 1. Normal Performance Mode (Default)

**Behavior:**
- System bar shows track and battery
- Content area shows plugin's default view (e.g., chord name for chord mapping)
- Bottom bar is empty or minimal

**Navigation:**
- No special navigation active
- Buttons control music/performance
- Joystick controls performance features

### 2. Menu Mode

**Activation:**
- **Tap INPUT button** - Opens/closes main menu
- **Press INPUT button** - Navigate to Input Stack settings
- **Press INSTRUMENT button** - Navigate to Instrument settings
- **Press FX button** - Navigate to FX settings

**Behavior:**
- System bar shows current context (e.g., "Input", "Instrument", "FX", or "Menu")
- Content area shows menu structure or settings UI
- Bottom bar shows navigation hints

**Navigation:**
- **Joystick UP/DOWN**: Navigate menu items/settings list
- **Joystick RIGHT/Encoder rotate**: Enter submenu OR change parameter value
- **Joystick LEFT**: Go back/exit current level
- **Encoder rotate**: Change selected parameter value (real-time, no save needed)
- **Encoder press**: Toggle boolean/cycle enum parameter
- **INPUT button tap**: Toggle menu open/closed (returns to normal mode)

**Key Principle: Settings change in real-time**
- No "save" action needed - encoder rotation immediately updates values
- Changes take effect immediately
- Pressing menu buttons (INPUT/INSTRUMENT/FX) navigates to their top-level settings

**Menu Structure:**
```
Main Menu (tap INPUT):
├─ Track 1
│  ├─ Input Stack (press INPUT)
│  │  ├─ Chord Mapping
│  │  │  ├─ Key: C Major          ← Encoder rotates to change
│  │  │  ├─ Mode: Ionian          ← Encoder rotates to cycle
│  │  │  └─ Joystick Preset: Classic
│  │  └─ (other input plugins...)
│  ├─ Instrument (press INSTRUMENT)
│  │  └─ (instrument settings...)
│  └─ Effects (press FX)
│     └─ (effect settings...)
├─ Track 2
├─ Scene Management
├─ System Settings
│  ├─ MIDI Configuration
│  ├─ Display Settings
│  └─ Calibration
└─ Debug View
```

**Example Settings UI (when in Input Stack menu):**
```
┌─────────────────────────────────┐
│ 85%  Track 1           Input    │
├─────────────────────────────────┤
│ Chord Mapping                   │
│                                 │
│ > Key: C Major                  │
│   Mode: Ionian                  │
│   Joystick Preset: Classic      │
│                                 │
├─────────────────────────────────┤
│ ↑↓ nav  ◄► change  INPUT: back │
└─────────────────────────────────┘
```

**Navigation Flow Example:**
1. Normal mode → Tap INPUT → Opens main menu
2. Main menu → Press INPUT button → Enters "Input Stack" context
3. Input Stack → Joystick DOWN → Navigate to "Chord Mapping"
4. Chord Mapping → Joystick RIGHT → Enter Chord Mapping settings
5. Settings → Encoder rotate → Change "Key" value in real-time
6. Settings → INPUT tap → Go back one level (to Input Stack list)
7. Input Stack → INPUT tap → Go back to main menu
8. Main menu → INPUT tap → Close menu, return to normal mode

### 4. Plugin-Defined UI Mode

**Activation:**
- Plugin requests UI control (via interface)
- Can be activated from settings or automatically

**Behavior:**
- System bar still visible (always)
- Content area fully controlled by plugin
- Plugin can render custom graphics, menus, etc.

**Navigation:**
- Controlled by plugin (but should respect standard conventions)
- Plugin should handle INPUT button for exit/back

## Input Controls Mapping

### Normal Mode
- **Buttons 1-7**: Musical input (chords, notes, etc.)
- **Joystick**: Performance control (chord variations, etc.)
- **Encoder**: Usually inactive (or assigned to volume/filter)

### Menu Mode
- **INPUT button tap**: Toggle menu open/closed
- **INPUT button press (in menu)**: Navigate to Input Stack settings
- **INSTRUMENT button press (in menu)**: Navigate to Instrument settings  
- **FX button press (in menu)**: Navigate to FX settings
- **Joystick UP/DOWN**: Navigate list/options
- **Joystick LEFT**: Go back/exit current level
- **Joystick RIGHT**: Enter submenu/select item
- **Encoder rotate**: Change parameter value (real-time, immediate effect)
- **Encoder press**: Toggle/cycle (boolean/enum parameters)

### Record Button
- **Normal mode**: Record/playback control (track-specific)
- **Settings/Menu mode**: Cancel/discard changes (if applicable)
- **Hold with INPUT**: Toggle debug screen (existing behavior)

## Plugin Settings Interface

All plugins (Input, Instrument, Effect) can define settings that appear in Quick Settings or Menu mode.

### Settings Definition

Plugins implement:
```cpp
struct PluginSetting {
    const char* name;              // Display name
    SettingType type;              // INT, FLOAT, BOOL, ENUM, STRING
    void* value_ptr;               // Pointer to actual value
    float min_value;               // For numeric types
    float max_value;               // For numeric types
    const char** enum_options;     // For ENUM type (null-terminated array)
    void (*on_change)(void* value); // Optional callback
};

class IPluginWithSettings {
    virtual int GetSettingCount() = 0;
    virtual PluginSetting* GetSetting(int index) = 0;
    virtual void RenderSettingsUI(DisplayManager* display, int selected_index) = 0;
};
```

### Settings Rendering

Plugins can provide:
1. **Automatic rendering** - System generates list UI from `PluginSetting[]`
2. **Custom rendering** - Plugin provides `RenderSettingsUI()` for advanced UIs

## Implementation Plan

### Phase 1: Core UI System
1. **UI Manager** - Coordinates all UI components
   - Manages system bars
   - Coordinates content area rendering
   - Handles mode transitions

2. **System Bar Renderer** - Always-visible top bar
   - Battery percentage
   - Track name
   - Context indicator

3. **Content Area Manager** - Routes rendering to appropriate component
   - Normal mode → Plugin default view
   - Settings mode → Settings UI
   - Menu mode → Menu UI
   - Debug mode → Debug screen

### Phase 2: Menu System
1. **Menu Manager** - Hierarchical menu navigation
   - Menu tree structure
   - Breadcrumb navigation
   - Context-aware menu generation
   - Button-based navigation (INPUT/INSTRUMENT/FX buttons)

2. **Menu Mode** - Tap INPUT button to toggle
   - Main menu
   - Track settings
   - Input Stack / Instrument / FX navigation via buttons

### Phase 3: Settings System
1. **Settings Manager** - Handles plugin settings access
   - Query settings from plugins
   - Generate settings UI
   - Handle value changes (real-time, no save needed)

2. **Settings UI** - Integrated into menu system
   - Navigate to plugin via menu
   - Real-time parameter editing with encoder
   - Automatic list UI generation

### Phase 4: Plugin Integration
1. **Settings Interface** - `IPluginWithSettings`
   - Plugin registration
   - Settings querying
   - Custom UI support

2. **UI Adaptation** - Update existing UI components
   - MainUI → Content area renderer
   - DebugScreen → Content area renderer
   - Plugin UIs → Content area renderers

## File Structure

```
src/
  core/
    ui/
      ui_manager.h/cpp           # Main UI coordinator
      system_bar.h/cpp           # Top system bar renderer
      status_bar.h/cpp           # Bottom status bar renderer
      content_area.h/cpp         # Content area router
      settings_manager.h/cpp     # Plugin settings handling
      menu_manager.h/cpp         # Menu navigation system
      settings_ui.h/cpp          # Generic settings list UI
      main_ui.h/cpp              # (refactored) Default content view
      debug_screen.h/cpp         # (refactored) Debug content view
    plugin_interface.h           # Add IPluginWithSettings interface
```

## Migration Plan

### Step 1: Create Core UI System
- UI Manager class
- System Bar renderer
- Content Area manager
- Integrate with existing MainUI

### Step 2: Add Menu System
- Menu Manager
- Menu mode (tap INPUT to toggle)
- Button-based navigation (INPUT/INSTRUMENT/FX)
- Menu UI renderer
- Main menu structure

### Step 3: Add Settings System
- Settings Manager
- Settings UI integrated into menu
- Real-time parameter editing
- Add settings to ChordMappingInput plugin

### Step 4: Refactor Existing UI
- Move MainUI to content area renderer
- Move DebugScreen to content area renderer
- Remove duplicate display clearing/updating
- Unified rendering through UI Manager

### Step 5: Plugin Integration
- Add IPluginWithSettings interface
- Implement in ChordMappingInput
- Support custom UI rendering
- Document for plugin developers

## UX Flow Examples

### Example 1: Change Chord Mapping Key

**Normal Mode:**
1. User sees chord name: "Cmaj7"
2. System bar shows: "85%  Track 1      -"

**Tap INPUT:**
3. Enters Quick Settings mode
4. System bar shows: "85%  Track 1  Chord Mapping"
5. Content shows: Settings list with "Key: C Major" selected
6. Status bar shows: "↑↓ nav  ◄► change  INPUT: exit"

**Change Setting:**
7. Rotate encoder → Changes key (C → C# → D → ...)
8. Value updates in real-time

**Exit:**
9. Tap INPUT → Returns to normal mode
10. New chord reflects new key

### Example 2: Access Deep Menu

**Normal Mode:**
1. Hold INPUT button (500ms+)
2. Enters Menu Mode
3. Shows: Main menu with "Track 1 Settings" selected

**Navigate:**
4. Joystick DOWN → "Track 2 Settings"
5. Joystick RIGHT → Enters "Track 2 Settings"
6. Shows: "Input Stack", "Instrument", "Effects"
7. Joystick DOWN → "Input Stack"
8. Joystick RIGHT → Enters "Input Stack"
9. Shows: List of input plugins
10. Select "Chord Mapping" → Shows settings (same as Quick Settings)

**Exit:**
11. Joystick LEFT (multiple times) → Back to main menu
12. Tap INPUT → Exit to normal mode

## Design Decisions

### Why Tap vs Hold?
- **Tap (Quick Settings)**: Fast access to current plugin settings - most common case
- **Hold (Menu)**: Full system navigation - less frequent, shouldn't be accidental

### Why System Bars Always Visible?
- Context is critical - user always knows what track/plugin they're using
- Battery visibility prevents unexpected shutdowns
- Consistent UI frame reduces disorientation

### Why Plugin-Driven Content?
- Allows advanced UIs for complex plugins (e.g., sequencers with visual patterns)
- Simple plugins can use automatic list-based settings UI
- Flexibility for future plugin types

### Why Separate Settings from Menu?
- Quick Settings (tap) = fast tweaking during performance
- Menu (hold) = comprehensive system navigation
- Different use cases, different interaction patterns

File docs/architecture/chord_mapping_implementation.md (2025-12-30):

# Chord Mapping Implementation Plan

[← Back to Documentation](../README.md)

## Overview

This document outlines the implementation plan for the primary chord mapping use case. The chord mapping system allows users to play chords using buttons 1-7 and modify them with the joystick (inversions, extensions).

## Architecture Alignment

**Key Principle**: Chord mapping is implemented as an **Input Plugin** (IInputPlugin), NOT a PlayMode, following the firmware architecture specification:
- "Features like chord/note input mapping should be implemented as input plugins, not PlayModes."
- Lives in the Track's Input Stack
- Generates/transforms MIDI from button presses and joystick
- Works seamlessly with existing Track/Instrument/FX pipeline

## Components

### 1. Chord Mapping Input Plugin (`chord_mapping_input.h/cpp`)
**Location**: `src/plugins/input/chord_mapping_input.h/cpp`

**Features**:
- Implements `IInputPlugin` interface
- Maps buttons 1-7 (MusicalButton::WHITE_0 through BLACK_2) to scale degrees (I-VII) of the current key/mode
- **8-Directional Joystick Presets**: Joystick directions (UP, DOWN, LEFT, RIGHT, and diagonals) apply smart chord variations from configurable presets
- **Musical Key/Mode Support**: Buttons map to diatonic chords based on selected key root and mode (Ionian, Dorian, Phrygian, etc.)
- **Joystick Preset System**: Multiple presets (Classic, Jazzy, Ambient) with 8-directional chord quality mappings
- Generates MIDI NOTE_ON/OFF events for all notes in the chord
- Handles button press/release events to trigger chord on/off
- Real-time chord updates when joystick direction changes while button is held

### 2. Chord Theory Library (`chord_engine.h/cpp`)
**Location**: `src/core/music/chord_engine.h/cpp`

**Features**:
- **Chord Definitions**:
  - Basic qualities: Major, minor, diminished, augmented
  - Extensions: 7th (maj7, min7, dom7), 9th (maj9, min9, dom9), sus4, sus2
  - Inversions: Root position, 1st inversion, 2nd inversion
- **Chord Name Generation**: String generation for UI display (e.g., "Cmaj7")
- **Musical Key and Mode Support**: 
  - 12 root notes (C through B)
  - 7 modes (Ionian/Major, Dorian, Phrygian, Lydian, Mixolydian, Aeolian/Minor, Locrian)
  - Automatic diatonic chord quality calculation per scale degree
- **Joystick Preset System**: Predefined 8-directional chord variation presets (Classic, Jazzy, Ambient)

**Chord Structure**:
```cpp
enum class ChordQuality {
    MAJOR,          // 1-3-5
    MINOR,          // 1-b3-5
    DIMINISHED,     // 1-b3-b5
    AUGMENTED,      // 1-3-#5
    MAJOR_7,        // 1-3-5-7
    MINOR_7,        // 1-b3-5-b7
    DOMINANT_7,     // 1-3-5-b7
    MAJOR_9,        // 1-3-5-7-9
    MINOR_9,        // 1-b3-5-b7-9
    SUS4,           // 1-4-5
    SUS2            // 1-2-5
};

enum class ChordInversion {
    ROOT,           // Root position
    FIRST,          // 1st inversion
    SECOND          // 2nd inversion
};
```

### 3. Main UI System (`main_ui.h/cpp`)
**Location**: `src/core/ui/main_ui.h/cpp`

**Features**:
- Default view: Displays current chord name (e.g., "Cmaj7")
- Displays current musical key and mode (e.g., "C Maj")
- Displays active joystick preset name (e.g., "Preset: Classic")
- Updates in real-time when chord changes
- Replaces debug screen as the default view
- Simple, clean display focused on chord information

### 4. Debug Screen Toggle
**Enhancement to existing**: `src/core/ui/debug_screen.h/cpp`

**Features**:
- Button combo: INPUT + RECORD (held for ~500ms) toggles debug screen
- Debug screen disabled by default (`DEBUG_SCREEN_ENABLED` compile flag)
- Toggle state persists during runtime
- Easy to access when needed, hidden during normal use

## Integration Points

### Track System Integration
1. Create Track instance in `main.cpp`
2. Add `ChordMappingInput` plugin to track's input stack
3. Track processes input → generates MIDI → sends to Instrument
4. MIDI Output: Route Track-generated MIDI to `midi_handler` for USB and TRS

### MIDI Routing Flow
```
Button Press → ChordMappingInput Plugin → Generate MIDI Events
    ↓
Track Collects Events from Input Stack
    ↓
Track Processes through Instrument (if present)
    ↓
main.cpp Routes Track MIDI to midi_handler.SendMidi()
    ↓
MIDI sent to USB MIDI and TRS MIDI outputs
```

### Existing Systems Used
- **InputManager**: Access to buttons and joystick
- **DisplayManager**: Render chord name on screen
- **MidiHandler**: Send MIDI to USB and TRS
- **Track System**: Process MIDI through input stack
- **IInputPlugin Interface**: Plugin integration

## Configuration (Preset System)

### Preset Structure
```cpp
struct ChordPreset {
    const char* name;                  // Display name
    uint8_t root_notes[7];             // MIDI note for each button (1-7)
    ChordQuality qualities[7];         // Chord quality for each button
    uint8_t base_octave;               // Base octave for chords (default: 4 = C4)
};
```

### Button Mapping (Scale Degree Based)
Buttons 1-7 map to scale degrees I-VII of the currently selected key/mode:

**Default Key: C Ionian (C Major)**
- Button 1 → Scale degree I → C Major
- Button 2 → Scale degree II → D Minor  
- Button 3 → Scale degree III → E Minor
- Button 4 → Scale degree IV → F Major
- Button 5 → Scale degree V → G Major
- Button 6 → Scale degree VI → A Minor
- Button 7 → Scale degree VII → B Diminished

**Example: D Dorian**
- Button 1 → D Minor (I in Dorian)
- Button 2 → E Minor (II in Dorian)
- Button 3 → F Major (III in Dorian)
- ... (chord qualities automatically determined by mode)

### Joystick Preset System
Each preset defines chord variations for 8 joystick directions:
- **Classic**: Traditional extensions (Major 9th, Minor 7th, Dominant 7th, etc.)
- **Jazzy**: Jazz-oriented voicings and extensions
- **Ambient**: Open, ethereal sounds (Sus2, Sus4, extended chords)

When a button is held and joystick is moved, the chord quality changes based on the preset's direction mapping.

## UI Flow

### Default State (Normal Operation)
- Display shows current chord name: "Cmaj7 1st Inv"
- Updates automatically when chord changes
- Clean, minimal interface

### Debug Mode (Toggled via Button Combo)
- Hold INPUT + RECORD for ~500ms → Debug screen appears
- Debug screen shows system status, inputs, analog, audio, MIDI
- Same button combo to exit debug mode
- Debug screen respects existing navigation (encoder)

## File Structure

```
src/
  core/
    music/
      chord_engine.h/cpp          # Chord theory, definitions, presets
    ui/
      main_ui.h/cpp               # Default chord name display
      debug_screen.h/cpp          # (existing, add toggle support)
  plugins/
    input/
      chord_mapping_input.h/cpp   # Main chord mapping plugin
  main.cpp                        # Integration & system wiring
```

## Implementation Order

1. **Chord Theory Library** (Foundation)
   - Chord definitions and structures
   - Chord name generation
   - Preset configurations

2. **Chord Mapping Plugin** (Core Functionality)
   - Plugin implementation following IInputPlugin
   - Button mapping to chords
   - Joystick control for variations
   - MIDI event generation

3. **Main UI** (Display System)
   - Chord name rendering
   - Update logic

4. **Debug Toggle** (UX Enhancement)
   - Button combo detection
   - Toggle state management

5. **Track Integration** (System Wiring)
   - Track creation and configuration
   - Plugin installation
   - MIDI routing

6. **Main.cpp Updates** (System Integration)
   - Remove old direct MIDI generation code
   - Wire new Track-based system
   - Update UI rendering loop

7. **Testing** (Verification)
   - Verify MIDI output on USB
   - Verify MIDI output on TRS
   - Test chord generation accuracy
   - Test joystick variations

## Design Decisions

### Smart Defaults
- Default key: C Ionian (C Major)
- Default mode: Ionian (Major scale)
- Default joystick preset: "Classic" (preset index 0)
- Buttons 1-7 map to scale degrees I-VII, automatically calculating diatonic chord qualities based on the selected mode
- Base octave: C4 (MIDI note 60) for root note calculation
- Chord qualities are mode-aware (e.g., in Dorian mode, degree I is minor, not major)

### Joystick Mapping (8-Directional Presets)
The joystick uses 8-directional detection with configurable presets:

- **8 Directions**: UP, DOWN, LEFT, RIGHT, UP_LEFT, UP_RIGHT, DOWN_LEFT, DOWN_RIGHT
- **CENTER**: No modification (uses base diatonic chord quality)
- **Each Direction**: Maps to a chord quality defined in the active preset
- **Dynamic Updates**: When joystick direction changes while a button is held, the chord updates in real-time

**Dead Zone**: 0.3 threshold to prevent accidental direction changes near center

**Preset Examples**:
- **Classic Preset** (default):
  - UP → Major 9th
  - UP_RIGHT → Major 7th
  - RIGHT → Dominant 7th
  - DOWN_RIGHT → Sus4
  - DOWN → Minor 7th
  - DOWN_LEFT → Minor 9th
  - LEFT → Major 9th
  - UP_LEFT → Sus2

### Velocity
- Fixed velocity for now (100 = mezzo-forte)
- Can be enhanced later with pressure-sensitive input or encoder control

### Presets
- Hardcoded presets initially
- Can be expanded later to load from storage/configuration files
- Easy to add more presets (jazz voicings, modal scales, etc.)

## Architecture Compliance

### ✅ Follows Plugin Interface
- Implements `IInputPlugin` correctly
- Provides `GenerateMIDI()` for MIDI event generation
- Handles `ProcessMIDI()` for MIDI transformation (passthrough)
- Implements all required `IPlugin` methods

### ✅ Uses Existing Track System
- Plugins live in Track's Input Stack
- Track processes MIDI through standard pipeline
- No shortcuts or bypassing architecture

### ✅ Respects Input Stack Architecture
- Input plugins generate/transform MIDI
- Multiple plugins can be stacked
- Priority-based processing

### ✅ UI Follows Existing Patterns
- Uses DisplayManager for rendering
- Follows existing display update patterns
- Minimal, focused UI

### ✅ MIDI Uses Existing Handler
- No custom MIDI routing
- Uses `midi_handler.SendMidi()` for output
- Supports both USB and TRS automatically

### ✅ No Bespoke Code
- All code follows established patterns
- Reusable components
- Maintainable structure
- No code that will need rewriting when UX system is added

## Future Enhancements

1. **User-Defined Presets**: Store/load presets from SD card
2. **Chord Voicing Options**: Different voicings (close, open, drop 2, etc.)
3. **Velocity Control**: Dynamic velocity from encoder or pressure
4. **Scale Modes**: Different scale mappings (pentatonic, modes, etc.)
5. **Arpeggiator Integration**: Add arpeggio patterns over chords
6. **Chord Progression Memory**: Store and recall chord progressions

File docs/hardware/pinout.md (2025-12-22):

# OpenChord Pinout Documentation

[← Back to Documentation](../README.md)

## Overview

This document tracks the detailed pin assignments for the OpenChord custom hardware setup. The Daisy Seed has limited pins, so every pin must be carefully allocated.

<picture>
  <source media="(prefers-color-scheme: dark)" srcset="https://daisy.nyc3.cdn.digitaloceanspaces.com/products/seed/Seed_pinout_dark.png">
  <source media="(prefers-color-scheme: light)" srcset="https://daisy.nyc3.cdn.digitaloceanspaces.com/products/seed/Seed_pinout_light.png">
  Daisy Seed Pinout
</picture>

## Pin Usage Summary

| Category | Pins Used | Pin Numbers | Notes |
|---|---|---|---|
| SDMMC (SD Card) | 6 | 2-7 | SD card interface |
| SPI (Display) | 5 | 8-11, 14-15 | Display interface (DC on pin 14, RST on pin 15) |
| MIDI (UART) | 2 | 12-13 | UART4 for MIDI I/O |
| User Interface | 8 | 1, 22-26, 34-35 | Joystick button (pin 1), volume, mic, encoder, battery |
| Audio I/O | 5 | 16-20 | Audio in/out + ground |
| Key Matrix | 7 | 27-33 | 11 keys in 4x3 matrix |
| USB | 2 | 36-37 | USB interface |
| Power & Ground | 4 | 21, 38-40 | 3V3A, 3V3D, VIN, GND |
| **Total** | **40** | **1-40** | **All 40 pins allocated** |

## Component Connection Details

| Component | Pin | Daisy Pin | Daisy Pin Name | Notes |
|---|-----|---|---|---|
| **OLED Display** | Screen Pin | Daisy Pin | Daisy Pin Name | Notes |
|-----------|-----|-----------|----------------|-------|
| | VCC | 38 | +3V3D | Power |
| | GND | 40 | GND | Ground |
| | CS | 8 | SPI1_CS | Chip select |
| | A0/DC | 14 | D13 | Data/Command (GPIO, USART1_TX) |
| | CLK | 9 | SPI1_SCK | Clock |
| | Data | 11 | SPI1_MOSI | Data out |
| | RST | 15 | D14 | Reset (GPIO, USART1_RX) |
| **MicroSD Card** | VCC | 38 | +3V3D | Power |
| | GND | 40 | GND | Ground |
| | CLK | 7 | SDMMC1_CK | Clock |
| | CMD | 6 | SDMMC1_CMD | Command |
| | DAT0 | 5 | SDMMC1_D0 | Data 0 |
| | DAT1 | 4 | SDMMC1_D1 | Data 1 |
| | DAT2 | 3 | SDMMC1_D2 | Data 2 |
| | DAT3 | 2 | SDMMC1_D3 | Data 3 |
| **Joystick** (Adafruit #5628) | Joystick Pin | Daisy Pin | Daisy Pin Name | Notes |
| | Pin 0 (Pot Rail) | 21 | +3V3A | VCC rail for both potentiometers (3.3V) |
| | Pin 1 (Pot Rail) | 40 | GND | GND rail for both potentiometers |
| | Pin 2 (Y Wiper) | 25 | ADC3 | Y-axis wiper (up/down axis, analog voltage divider output) |
| | Pin 5 (X Wiper) | 24 | ADC2 | X-axis wiper (left/right axis, analog voltage divider output) |
| | Pin 3 (Button) | 1 | D0 | Button contact 1 (with internal pull-up) |
| | Pin 4 (Button) | 40 | GND | Button contact 2 (connects to Pin 3 when pressed) |
| **Encoder** | A | 34 | GPIO | Encoder A |
| | B | 35 | GPIO | Encoder B |
| | SW | - | - | Not connected |
| **Key Matrix** | Row 0 | 27 | D20 | Matrix row (Top row) |
| | Row 1 | 28 | D21 | Matrix row (Middle row) |
| | Row 2 | 29 | D22 | Matrix row (Bottom row) |
| | Col 0 | 30 | D23 | Matrix column 0 |
| | Col 1 | 31 | D24 | Matrix column 1 |
| | Col 2 | 32 | D25 | Matrix column 2 |
| | Col 3 | 33 | D26 | Matrix column 3 |
| **Audio I/O** | Line Out L | 18 | AUDIO_OUT_L | Left output |
| | Line Out R | 19 | AUDIO_OUT_R | Right output |
| | Line In L | 16 | AUDIO_IN_L | Left input |
| | Line In R | 17 | AUDIO_IN_R | Right input |
| | AGND | 20 | AGND | Audio ground |
| **MIDI DIN** | TX | 13 | UART4_TX | MIDI out |
| | RX | 12 | UART4_RX | MIDI in |
| **Volume** | Pot | 22 | ADC0 | Volume control |
| **Microphone** | Mic In | 23 | ADC1 | Microphone input |
| **Battery** | Monitor | 26 | ADC4 | Voltage divider |
| **Audio Switch** | TRS Switch | - | - | Not connected (pin 15 used for display RST) |
| **USB** | D- | 36 | USB_HS_D- | USB data - |
| | D+ | 37 | USB_HS_D+ | USB data + |

## Notes

- **Key matrix** uses 7 pins for 11 keys (4x3 matrix with one unused position)
- **SPI and SDMMC** use hardware peripherals for optimal performance
- **Analog inputs** are used for joystick, volume, microphone, and battery monitoring
- **Digital I/O** used for buttons, encoder, and control signals
- **Audio I/O** uses dedicated audio pins for best performance

## Future Considerations

- If additional features are needed, some pins may need to be multiplexed
- Consider using I2C expanders for additional I/O if needed
- USB MIDI can reduce need for DIN MIDI pins if space is critical
- Some functions could be combined (e.g., encoder button could serve multiple purposes) 

## Daisy Seed Pinout Table Reference

| PINOUT | DAISY PIN NAME | STM32 PIN NAME | PRIMARY FUNCTION | ALT. FUNCTIONS 1 | ALT. FUNCTIONS 2 | VOLTAGE NOTES |
|---|---|---|---|---|---|---|
| 1 | D0 | PB12 | GPIO | USB_HS_ID/UART5_RX/USART3_CK | TIM1_BKIN | 5V tolerant |
| 2 | D1 | PC11 | GPIO | SDMMC1_D3/USART3_RX/UART4_RX | SPI3_MISO/I2S3_SDI/HRTIM_FLT2 | 5V tolerant |
| 3 | D2 | PC10 | GPIO | SDMMC1_D2/USART3_TX/UART4_TX | SPI3_SCK/I2S3_CK/HRTIM_EEV1 | 5V tolerant |
| 4 | D3 | PC9 | GPIO | SDMMC1_D1/UART5_CTS | I2S_CKIN/MCO2 | 5V tolerant |
| 5 | D4 | PC8 | GPIO | SDMMC1_D0/UART5_RTS | | 5V tolerant |
| 6 | D5 | PD2 | GPIO | SDMMC1_CMD/UART5_RX | | 5V tolerant |
| 7 | D6 | PC12 | GPIO | SDMMC1_CK/UART5_TX/USART3_CK | SPI3_MOSI/I2S3_SDO | 5V tolerant |
| 8 | D7 | PG10 | GPIO | SPI1_NSS/I2S1_WS | HRTIM_FLT5 | 5V tolerant |
| 9 | D8 | PG11 | GPIO | SPI1_SCK/I2S1_CK | LPTIM1_IN2/HRTIM_EEV4 | 5V tolerant |
| 10 | D9 | PB4 | GPIO | SPI1_MISO/UART7_TX | SPI1_MISO/I2S1_SDI/SPI3_MISO/I2S3_SDI/SPI6_MISO | 5V tolerant |
| 11 | D10 | PB5 | GPIO | SPI1_MOSI/UART5_RX | SPI1_MOSI/I2S1_SDO/SPI3_MOSI/I2S3_SDO/SPI6_MOSI/I2C4_SMBA/TIM17_BKIN | 5V tolerant |
| 12 | D11 | PB8 | GPIO | I2C1_SCL/UART4_RX | I2C4_SCL/TIM16_CH1/TIM4_CH3 | 5V tolerant |
| 13 | D12 | PB9 | GPIO | I2C1_SDA/UART4_TX/SPI2_NSS/I2S2_WS | I2C4_SDA/I2C4_SMBA/TIM17_CH1/TIM4_CH4 | 5V tolerant |
| 14 | D13 | PB6 | GPIO | USART1_TX/LPUART1_TX/UART5_TX | I2C1_SCL/I2C4_SCL/TIM16_CH1N/TIM4_CH1 | 5V tolerant |
| 15 | D14 | PB7 | GPIO | USART1_RX/LPUART1_RX | I2C1_SDA/I2C4_SDA/TIM17_CH1N/TIM4_CH2 | 5V tolerant |
| 16 | NC | | AUDIO IN L | | | Audio pin |
| 17 | NC | | AUDIO IN R | | | Audio pin |
| 18 | NC | | AUDIO OUT L | | | Audio pin |
| 19 | NC | | AUDIO OUT R | | | Audio pin |
| 20 | NC | | AGND | | | Audio ground |
| 21 | NC | | +3V3A | | | Power rail |
| 22 | A0, D15 | PC0 | GPIO | ADC0/SAI2_FS_B | | ADC max: 3.6V |
| 23 | A1, D16 | PA3 | GPIO | ADC1/USART2_RX | TIM2_CH4/TIM5_CH4 | ADC max: 3.6V |
| 24 | A2, D17 | PB1 | GPIO | ADC2 | TIM1_CH3N/TIM3_CH4 | ⚠️ **NOT 5V tolerant (3.3V max)** |
| 25 | A3, D18 | PA7 | GPIO | ADC3/SPI1_MOSI/I2S1_SDO/SPI6_MOSI | TIM1_CH1N/TIM3_CH2 | ⚠️ **NOT 5V tolerant (3.3V max)** |
| 26 | A4, D19 | PA6 | GPIO | ADC4/SPI1_MISO/I2S1_SDI/SPI6_MISO | TIM1_BKIN/TIM3_CH1 | ADC max: 3.6V |
| 27 | A5, D20 | PC1 | GPIO | ADC5 | | ADC max: 3.6V |
| 28 | A6, D21 | PC4 | GPIO | ADC6/I2S1_MCK | | ⚠️ **NOT 5V tolerant (3.3V max)** |
| 29 | A7, D22 | PA5 | GPIO | ADC7/DAC1_OUT2 | SPI1_SCK/I2S1_CK/SPI6_SCK/D2PWREN/TIM2_CH1 | ⚠️ **NOT 5V tolerant (3.3V max)** |
| 30 | A8, D23 | PA4 | GPIO | ADC8/DAC1_OUT1 | SPI1_NSS/I2S1_WS/SPI3_NSS/I2S3_WS/SPI6_NSS/D1PWREN | ⚠️ **NOT 5V tolerant (3.3V max)** |
| 31 | A9, D24 | PA1 | GPIO | ADC9/SAI2_MCLK_B | UART4_RX/TIM2_CH2/TIM5_CH2 |
| 32 | A10, D25 | PA0 | GPIO | ADC10/SAI2_SD_B | UART4_TX/TIM2_CH1/TIM2_ETR/TIM5_CH1 |
| 33 | D26 | PD11 | GPIO | SAI2_SD_A/I2C4_SMBA | LPTIM2_IN2 |
| 34 | D27 | PG9 | GPIO | SAI2_FS_B/USART6_RX | SPI1_MISO/I2S1_SDI |
| 35 | A11, D28 | PA2 | GPIO | ADC11/SAI2_SCK_B | USART2_TX/TIM2_CH3/TIM5_CH3 |
| 36 | D29 | PB14 | GPIO | USB_HS_D-/USART1_TX | TIM1_CH2N |
| 37 | D30 | PB15 | GPIO | USB_HS_D+/USART1_RX | |
| 38 | NC | | +3V3D | | |
| 39 | NC | | VIN | | |
| 40 | PG3 | | GND | | |

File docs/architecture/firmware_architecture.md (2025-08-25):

 # OpenChord Firmware Architecture

[← Back to Documentation](../README.md)

## Core Concepts

* Portable, open-source music device using the Daisy Seed MCU
* Built-in sequencer, looper, sampler, instruments, audio effects, and expressive performance features
* Highly modular firmware with plugin-like components (bundled at compile time)
* Tracks are the primary unit of music creation. Scenes allow dynamic performance and composition by storing variations in track loop content and parameters, while the tracks themselves define the fixed signal/control path.

## Track Structure

Each track consists of modular stages:

### 1. Input Stack
One or more modules that generate or transform MIDI. This includes:
* **Recorded MIDI loops** (handled by the OS's internal looper, appear at the top of the stack)
* **Core MIDI inputs** from keypad, USB, or 3.5mm MIDI (always present below recorded loops)
* **Step sequencers**
* **MIDI/Joystick remapping tools** (e.g. chord or scale mapping)
* **MIDI effects or generators** (e.g. randomizers, arpeggiators)

### 2. Instrument
The core sound generator, e.g. a synth engine or sampler.
* Built-in options provided
* Modular engine support through firmware-bundled plugins

### 3. Effects
Post-processing like delay, reverb, filters, saturation
* Effects are per-track

## Scenes

* Scenes are closely integrated with the internal loop recorder system
* Scenes allow the user to snapshot and switch between variations of the current track
* Each scene stores:
  * The state of recorded MIDI loops (and optionally audio loops)
  * Parameter states of the currently loaded Instruments and Effects
* Scenes do **not** change:
  * The types or layout of Input Stack, Instrument, or FX modules — only their internal parameter values and loop content
* Only Scene 1 can change which modules are loaded into memory
* Spawning a new Scene creates an alternate version of the track's musical state and parameters
* Scene switching can be manual or sequenced
* Removing a plugin in Scene 1 removes it globally

## UI and Interaction

* **Track Selector**: Choose which track is currently focused for editing/play
* **Tabs or Pages** (Categorized for clarity):
  * **Input**: Edit MIDI generators/effects and recorded loops
  * **Instrument**: Choose or edit the instrument module
  * **FX**: Tweak post-processing effects
* Potentially support for custom UIs driven by plugins being interacted with.
  * A main outer/top level UI would always be present around the border or at the top of the screen
  * But a plugin could request to drive an inner section of screen manually.
  * This allows plugins to have as advanced or simple UIs as they want.

## PlayModes

A PlayMode is a global system behavior mode. It changes how the device and controls operate, suspending normal UI flow for a specialized interaction context. Examples:
* **Performance FX Mode**: Keys mapped to trigger effect actions (e.g. stutter, reverse, pitch shift)
* **Scene Switcher Mode**: Use buttons or pads to change scenes live

PlayModes can:
* Specify their own control mappings, overlays, and interface logic
* Use effects, but these are configured by the PlayMode designer, not user-selected
* Temporarily override the default system interaction model

**Note**: Features like chord/note input mapping should be implemented as input plugins, not PlayModes.

## Plugin System

* Plugins are modular code components for Inputs, Instruments, Effects, or PlayModes
* They are bundled at compile time — no dynamic loading
* Community-developed plugins are added via firmware PRs
* Categorized selection improves UX when browsing large collections
* Unified interface for all plugin types

## Goals

* Empower rapid music sketching and performance anywhere
* Maximize expression with minimal controls (joystick + encoder + keys)
* Support creative expansion via plugin ecosystem (bundled with firmware)
* Maintain modularity, readability, and clean UX at all levels

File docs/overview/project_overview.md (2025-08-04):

# OpenChord - Portable Open-Source Music Device

[← Back to Documentation](../README.md)

## Project Overview

My goal is to design and build a powerful, portable, and open-source music creation device with a workflow that just makes sense. It features hands-on control, beautiful sound, MIDI I/O, looper capabilities, and a sturdy 3D-printable enclosure, making it perfect for spontaneous music-making anywhere. Modular firmware architecture supports community-driven plugin development, creating an expandable ecosystem for artists and developers.

## 🔥 Use Cases

* 🎹 **Chord Generator**: Use joystick + chord mapping for fast harmonic inspiration
* 🎛️ **Synthesizer**: Design, tweak, and perform complex patches
* 🔁 **Looper**: Capture and layer performance ideas
* 🥁 **Sampler / Drum Machine**: Trigger from built-in pads or MIDI
* 🎚️ **DAW Companion**: Send and receive MIDI, control software instruments
* 🎼 **TRS MIDI Host and Client**: Play with your favorite controller or control your favorite hardware synth

## 🎧 Key Features

* **Standalone Synth Engine** with high-quality, expressive presets ("analog", granular, wavetable, fm, all of it)
* **Advanced Sound Design Options** accessible via encoders and menus
* **Powerful effects** like reverb, delay, etc. and even live performance effects
* **Drum(+More) Sampler** for beat-making (great presets, easy to upload packs)
* **Microphone and/or line in** for sampling and recording
* **Feature-Rich Looper** with layering(maybe...), overdub, free length
* **MIDI Controller Mode** to use as input for your DAW
* **MIDI Keyboard Input** for velocity-sensitive, expressive play
* **Battery Powered**, compact, and durable for true portability
* **Beautiful, Intuitive UI** on a sharp OLED screen with joystick and scroll wheel navigation

## 🧩 System Architecture

| Subsystem | Tech |
|---|---|
| MCU + Audio | Daisy Seed + libDaisy |
| UI | OLED screen + joystick + encoders + keys |
| Looper | Midi based, time-stretch, sync |
| Synth Engine | Wavetable, FM, poly/mono modes |
| Sampler | SD-based samples, mapped pads |
| Storage | microSD for loops, patches, and samples |
| Power | USB-C + PowerBoost 1000C + LiPo battery |
| Audio | headphone out, line in, 3.5mm TRS |
| MIDI I/O | 3.5mm TRS and USB MIDI (host + device) |

## 🖨️ Enclosure Plan

* 3D-printed, designed in Onshape
* Compact, durable, travel-ready
* Layout supports screen, encoders, joystick, keys
* Top ports for SD card, jacks

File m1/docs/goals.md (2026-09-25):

# OpenChord M1 — goals and plan

Written September 2026 so we do not lose the decisions that led here. This file is the product intent and the hardware lock. Behavior lives in [interaction.md](interaction.md). What is built and what is next lives in [build.md](build.md). Firmware lives under `m1/`. Do not edit `archive/s1-daisy/`.

**Working name:** OpenChord M1 (`OPENCHORD / m1`)

**Family:** OpenChord. **M** = MIDI tools. **S** = studio. Numbers are generations. The jambox, when it exists, is **S1**. Later we can do M2 / S2 without renaming anything.

---

## Why this exists

The original OpenChord was a portable Daisy Seed jambox: synth, tracks, looper, sampler, OLED, battery, 11 keys, joystick. A prototype was built. It taught us a lot. It is not the first thing to ship.

Reasons we paused the full dream:

- Daisy Seed audio on the proto never got clean (wiring, PowerBoost, grounds — the module fight was not worth another year).
- The kitchen-sink spec (four live engines, USB host + device, granular + wavetable + analog, audio looper) does not match a first sellable board.
- The author is a **DAW person**. MIDI into a computer is how the music actually gets made. A DAWless studio-in-a-brick was a fantasy of a device that would finally make DAWless feel good. At the end of the day the DAW won.
- The interesting idea was never the synth. It was **smart, dynamic chord mapping** that stays musical.

So: a smaller, MIDI-only product that can live on a custom PCB and actually be sold, plus a free plugin that runs the same engine. S1 stays in the family for later.

The Daisy tree is archived at [`../../archive/s1-daisy/`](../../archive/s1-daisy/). Do not treat it as S1 source.

---

## What M1 is

A **man-in-the-middle MIDI enhancer**. Feed it MIDI from a real keyboard, a controller, or the DAW. It sends MIDI back transformed: chords, voicings, extensions, voice leading.

Two hosts, **one engine** (`m1/engine`):

- **Hardware** — RP2040 box, USB-C MIDI device, later TRS. The thing you buy. USB name: `OpenChord M1`.
- **Plugin** — **OpenChord M Core**, free, MIT, AU MIDI FX + VST3. Same `oc::Render()`. MIDI Learn so any pads/stick/knobs can be the cluster.

- No audio (neither host).
- No USB host on the box. The PC is the USB host. M1 hardware is a USB MIDI **device**.
- Hardware: TRS MIDI in and TRS MIDI out (plus USB MIDI in/out).
- Bus-powered from USB-C. **No battery** on v1. If TRS-only gear needs it, plug USB-C into power with no data.
- Small enough to sit on a desk next to a keyboard and disappear into a session.

One-line pitch: *sits between your keys and the DAW and makes you sound like you know theory.*

Ambition: the most helpful chord/MIDI tool we have used. Not a quality roulette. It should voice well, stay in key, and later help with **where to go next** (progressions, ideas). Voicing that never sounds stupid is v1. Progression-smart is the north star; do not fake it with random borrowed chords. Write the model in [chord-engine.md](chord-engine.md).

---

## What M1 is not

- Not a synth, sampler, looper, or drum machine.
- Not the 11-key standalone piano from the Seed proto.
- Not a Daisy **product** and not a Pi/CM5 project. The old Seed box is a temporary M1 testbed only. See [testbed.md](testbed.md).
- Not USB MIDI host (no “plug a controller into M1 with no computer” as a v1 requirement).
- Not the old OpenChord hierarchical menu on the box. Extra settings live in the **plugin**, not extra knobs on the enclosure.
- Not a battery synth with speakers. We are a studio **MIDI** tool: great at the MIDI path, no sound of our own.
- Not a clone of other chord pads or slab synths. **Scale** is I–vii with our own color map and voice leading — designed here, named here. Do not put other companies’ product names in the UI, marketing, or source comments.

If a feature needs audio or a big on-device screen, it belongs on **S1**, not a “quick add” to M1. If it is a MIDI preference (channel split, voicing tightness, maps), it belongs in the plugin.

---

## Who it is for

First user is us: MIDI or live instruments into a DAW. Second user is anyone who wants left-hand chord control without buying a synth they will not use. The plugin is how people try it with a Launchkey (or anything). The box is for people who want that control in their hands.

In **Keys** the keyboard (or the DAW piano roll) chooses the root, or passes straight through when no keyswitch is held. In **Scale** the eight keyswitches are the degrees and a keyboard is optional. In **Drums** they are hits. Either way M1 is the left hand and the brain.

---

## Interaction

Three modes, one surface. The rules are locked in [interaction.md](interaction.md). Do not revive Pro, Smart, Follow, Play, or Jazz.

| Mode | Who it is for | What the eight keyswitches are |
|---|---|---|
| **Keys** | A keyboard into the box or the plugin | Chord type: Dim, Min, Maj, Sus, plus 6, m7, M7, 9. No keyswitch = the notes pass through, and the screen names the chord they form |
| **Scale** | Both hands on the box. No keyboard required | Degrees I–vii and I one octave up. The newest one held is the chord. Older ones stay down and come back when you let go |
| **Drums** | Hits, not chords | Two kits. Trackpad X picks the bank |

The trackpad is not a quality roulette. In Keys it picks bass and spread. In Scale it picks one of eight in-key chords around a safe center triad. Harmony (Tensions, Borrowed, Free) is specified and not built yet. In Drums, X is the bank and Y is velocity.

Strum is a menu setting, not a mode. **Optional** (default) lets the chord sound and the strip add plucks. **Only** waits for the strip.

The screen is two lines, the same on the plugin and the OLED: what will sound, then key, mode, and status. Menu rows are Key, Octave, Vary, Harmony, Strum.

**Hardware plan (rev A schematic):** capacitive **trackpad** on **IQS572BLQNR** (I²C `0x74`). **AT42QT2120-XUR** does the touch **strip only** (KEY0–2 slider). **No Key / Shift copper** on the QT. **3× EVQPUC02K** are Prev, Menu, and Next. Shared bus is **I2C1** on GPIO10/11 (OLED `0x3C` + QT `0x1C` + IQS `0x74`; IQS RDY GPIO8, NRST GPIO9). Alps **RKJXV1220001** / LCSC **C219778** stays in the KiCad lib as the fallback if the trackpad feel fails. Pin map: [`../hardware/support.md`](../hardware/support.md).

No encoder on v1. **No pots / dials on the box.** They add size and cost, and this product assumes a DAW.

The three edge buttons are **Prev**, **Menu**, and **Next** (SW11 GPIO3, SW9 GPIO4, SW10 GPIO5). Outside the menu they change mode. Inside it they move between settings. There is no panic button. Holding Menu inside the menu flushes stuck notes.

Key is a menu row. The next incoming note while that row is open sets the key and is not performed.

The box plays with no plugin. The plugin is how you bind controllers and, later, how you watch the box. When `OpenChord M1` is on USB the plugin stops voicing and mirrors one surface.

---

## Hardware (v1)

| Piece | Plan |
|---|---|
| MCU | **RP2040** on our PCB (TinyUSB MIDI device, UART TRS). Not ESP32. Not a Pico glued to a carrier. |
| USB | USB-C on the **edge of our board**, device only, also power |
| MIDI | TRS in, TRS out; USB MIDI in/out |
| Front | **8× Gateron LP** (hotswap) — **direct GPIO** each (internal pull-ups; no matrix / no diodes). Cap: **IQS572BLQNR** trackpad + **AT42QT2120-XUR** strip only (KEY0–2). Share **I2C1** (GPIO10/11) with OLED (`0x3C` / `0x1C` / `0x74`; IQS RDY GPIO8). **3× EVQPUC02K**: Prev, Menu, Next. PCB copper electrodes; printed cover with openings. Alps stick = KiCad fallback only (not on rev A). **No pots / SoftPot.** |
| Display | Cheap 0.91" I2C SSD1306 (Ali module on PCB). |
| Audio | None |
| Battery | None |
| Host USB | None |
| Cost | Proto (buy 5): **~$34**/unit, **~$171** for five, landed. Street under **$100**. Breakdown: [`../hardware/bom.md`](../hardware/bom.md) (2026-09-19 carts). |

One custom PCB. **Rev A proto:** 4-layer, **HASL**, soldermask over touch copper (not ENIG). Hot air for RP2040 + IQS572 + QT2120. Through-hole for TRS (bushings **off** the board edge) and Gaterons via sockets. Reproducible. Prove touch on **coupons / TPS43** before a later product fab. Details: [`../hardware/touch.md`](../hardware/touch.md), [`../hardware/bom.md`](../hardware/bom.md).

**Prove the engine before that board.** Portable logic first. Hands-on feel on the **RP2040-Zero proto** (`m1/proto-rp2040`) with a Launchkey. Seed box is parked on archived OG firmware. See [testbed.md](testbed.md).

---

## Plugin (free)

Same product, second host. Code: `m1/plugin/`. Engine stays `m1/engine`. v0 implementation brief: [plugin.md](plugin.md).

**Sell:** the box. **Give away:** the plugin, MIT, like the rest of the repo.

### Formats

Ship both from one project (JUCE is the practical stack):

| Format | Who |
|---|-----|
| **AU MIDI FX** | Logic, GarageBand — real MIDI insert |
| **VST3** | Cubase, Reaper, Bitwig, Studio One as MIDI FX where the host allows it. Ableton / FL: instrument-style wrapper that **outputs MIDI** onto another track (Scaler-shaped routing). |
| Standalone | Optional; IAC / loopMIDI last resort |

Do not ship AU-only. Most DAWs cannot host an AU MIDI effect.

### Who runs the engine

| | No hardware | Hardware on USB as `OpenChord M1` |
|--|--|--|
| **Engine** | Plugin | Box |
| **Plugin** | MIDI FX + Learn + extra settings | Bridge / editor / live view. **Does not voice.** |

Never run two engines on the same notes. Doubled chords and fighting voice-leading.

When the box is connected, extra settings can push to the device over MIDI (SysEx is the boring, correct path). Firmware update can live here later.

### Mapping and UI

MIDI Learn on the eight keyswitches, Prev, Menu, Next, trackpad X/Y, and the strip. One message, one control. A Launchkey preset (pads CC 36–43, knobs CC 47/48) is a convenience, not the product model.

The plugin draws the same two screen lines as the OLED, plus the eight keyswitches, the three buttons, the trackpad, and the strip. Ugly is fine.

Pretty overlay of the real enclosure is **later**, when the PCB exists. Do not skin the plugin as someone else’s device.

### Settings that are plugin knobs, not hardware dials

The menu on the box and in the plugin is the same: Key, Octave, Vary, Harmony, Strum. Extra ideas (channel split, other scales, shortcuts) wait. They are not a second set of knobs.

The box keeps defaults that already sound good. The plugin is the mixer.

---

## Chord engine — what we are fixing

The archived Seed mapper (`archive/s1-daisy` chord engine + joystick presets) had the right *idea* and a bad *feel*:

- Stick **replaced** quality instead of coloring the diatonic chord.
- Eight unique qualities, nastier ones on diagonals, analog stick cannot hit eight slices.
- No memory of the previous chord, no voice leading. Closed root-position stacks every time.
- Presets were the same eight qualities shuffled.

M1’s engine should make it **almost impossible to sound bad** and **still surprising**, then get good at **progressions**. That is the product. Do not port the old preset tables as the v1 model. **Scale** is how we put I–vii on the keyswitches: eight chords around a center triad, loosened only by Harmony. The live rules are in [interaction.md](interaction.md).

Useful scraps in the archive: scale/mode tables, interval lists, enclosure photos, “chord as an input plugin” as a concept. Not the 8-way quality map.

---

## Positioning

| Kind of product | Why we are not that |
|---|---|
| Battery synth with speakers | We are a studio **MIDI** tool. No audio of our own. |
| Chord-slab synth | We output MIDI. Scale is I–vii with a color map designed here. |
| Huge multi-button chord cockpit | We stay small and under $100. |
| Paid software-only chord assistants | We ship a **free** plugin and a **hardware** left hand. |
| Old OpenChord jambox proto | That is S1. |

Sell path: a board we can spin and price **under $100**, not a synth price. Plugin is free on purpose. MCU and radio were never going to be the margin. Enclosure, assembly, and not certifying Wi‑Fi are. **Assembly time matters:** one main PCB, **no paid PCBA** (you hand-build), no wiring harnesses, OLED soldered on-board — finishing a unit is not hours of cables or factory fees.

Name and domain: `openchord.com` is someone else’s music-apps site. Product name is still OpenChord M1; do not assume the domain. Do not put other companies’ product names on the hardware, plugin, store page, UI, or source comments.

---

## Repo and process

- Family lives in this repo (`OpenChord`). No product branches.
- M1 work stays under `m1/`.
- `s1/` stays empty until the jambox is a real project. **Do not dump M1 proto firmware there.**
- `archive/s1-daisy/` is frozen. Read it. Do not edit it. Restore the OG box by rebuilding that tree.
- Seed proto pins follow the archive **driver Init()** functions, not `pin_config.h` or `docs/hardware/pinout.md`. See [testbed.md](testbed.md) and `m1/proto-daisy/pin_map.h`.

```
m1/engine/          portable chord logic (no Daisy, no TinyUSB, no JUCE). This is the product.
m1/proto-rp2040/    RP2040-Zero lab harness. USB-C MIDI device. Not the product firmware.
m1/proto-daisy/     parked Seed harness. Restore OG from archive; do not edit archive.
m1/plugin/          OpenChord M Core — AU MIDI FX + VST3. Links m1/engine. Free.
m1/firmware/        RP2040 product firmware (later)
m1/hardware/        PCB / enclosure / KiCad libs
m1/docs/            this file, testbed, chord-engine
```

Build order, and what is already done, is [build.md](build.md). Short version: the plugin plays Keys, Scale, and Drums. Next is firmware on the rev A board, then the plugin mirroring that box. Do not build the photoreal UI before the box exists.

---

## Open decisions (on purpose)

These are not forgotten. They are not locked.

- Cap geometry (ICs locked — **IQS572BLQNR** + **AT42QT2120-XUR**): trackpad size / diamond pitch / deadzone; strip electrode geometry (slider = 3 interleaved → 0–255); **rev A = HASL + mask over copper**; ENIG gold electrodes = later SKU if feel needs it.
- Trackpad vs Alps stick: trackpad is on the board; C219778 remains the mechanical fallback in the lib (not populated on rev A).
- Harmony past **In key** (Tensions, Borrowed, Free). The tables are written. The engine still plays the In key map for every step.
- Other scales than major. Menu shortcuts. Drum rebinding. Arp. A photo skin of the enclosure.
- How much “next chord” suggestion is v1 vs later. The north star is still progressions, not a random borrowed chord.
- Trademark / `openchord.com` is someone else’s music-apps site.

Locked (do not reopen without updating this file and [interaction.md](interaction.md)): MCU RP2040; custom PCB with USB-C on the edge; no radio; no battery; no USB host on the SKU; **8 Gateron LP** keyswitches (**direct GPIO**, not a matrix); modes **Keys**, **Scale**, **Drums**; Scale 8th keyswitch = I one octave up; Scale center = the correct triad; newest held Scale keyswitch wins; Keys with no keyswitch names the incoming chord; Strum is **Optional** or **Only**; menu is Key, Octave, Vary, Harmony, Strum; edge buttons are Prev, Menu, Next; cap ICs = **IQS572BLQNR** (trackpad) + **AT42QT2120-XUR** (**strip only**); shared **I2C1** GPIO10/11; **3× EVQPUC02K**; USB-C = **TYPE-C-31-M-12** (C165948) **J1**; TRS = **SJ1-3523N** ×2 (**J2 OUT / J3 IN**, bushings off-board); flash **W25Q32JVSSIQ** (C179173); rev A proto **4-layer HASL** ~119 × 63 mm, SMT on **B.Cu**, hand-build (no paid PCBA); **no pots / no encoder / no SoftPot**; no QT Key/Shift copper; cheap OLED (GND/VCC/SCL/SDA); ~$99 hardware; plugin free (AU MIDI FX + VST3, same engine); hardware works with no plugin; if the box is connected the plugin does not voice; no competitor product names in UI/docs/code comments; engine portable; archive frozen. Pin map and passives: [`../hardware/support.md`](../hardware/support.md). Fab: [`../hardware/fab/jlcpcb/`](../hardware/fab/jlcpcb/).

When one of these is decided, update this file. Do not start a second source of truth.

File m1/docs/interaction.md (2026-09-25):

# M1 interaction plan

Working behavior spec. Hardware intent lives in [goals.md](goals.md). Status lives in [build.md](build.md). **How the box plays is this file.** [chord-engine.md](chord-engine.md) and [plugin.md](plugin.md) are the old Pro/Smart lab notes. Do not put other products’ names in UI, firmware, or this doc.

Engine stays one portable core (`m1/engine`). Firmware and **OpenChord M Core** both host it. If a real M1 is connected, the plugin mirrors and edits; it does not voice the same notes.

---

## What is locked vs open

| Locked | Open, decided here |
|---|---|
| 8 Gateron keyswitches, direct GPIO | What a keyswitch means in each mode |
| Trackpad (XY) | What XY means per mode |
| Strip (0–255 slider) | When the strip is allowed to sound notes |
| 3 tactile buttons | Middle = menu. Left / right = move |
| 128×32 OLED | Two screens: perform, menu |
| USB MIDI device + TRS in/out | Who is allowed to start a note |
| No pots, no panic key | Notes cannot get stuck |

---

## Names

Screen words are short on purpose. The sentence next to each one is what it means. Use these in UI, firmware, and the engine. Do not revive Pro, Smart, Follow, Play, or Jazz.

The box has four kinds of control. Those words are reserved.

| Part | Count | Call it |
|---|---:|---|
| Gateron Low Profile keyswitch | 8 | **keyswitch** |
| Edge tactile (EVQ) | 3 | **button** |
| IQS572 XY | 1 | **trackpad** |
| QT2120 slider | 1 | **strip** |

Do not call a keyswitch a pad. A pad is something on a controller that is not this box.

| Word | Where it shows up | What it means |
|---|---|---|
| **Keys** | Mode name | An incoming MIDI note is the root. The keyswitches choose the chord type. One hand on a keyboard, the other on the box. |
| **Scale** | Mode name | The eight keyswitches are degrees of the current key. The box plays the chord. No keyboard required. |
| **Drums** | Mode name | The eight keyswitches are drum hits. The box plays the kit. See Drums. |
| **Thru** | Keys, no keyswitch held | The incoming note is echoed. It is not turned into a chord. |
| **Bass** | Keys trackpad X | Which chord tone sits on the bottom: root, 3rd, 5th, or 7th if the chord already has a 7th. |
| **Spread** | Keys trackpad Y | Tight stack versus open voicing. Never changes major into minor. Finger up returns to the home voicing. |
| **Color** | Scale trackpad | Nine positions. Center is that degree’s correct triad. Each of the other eight is its own chord, not a mix of the two axes. |
| **Harmony** | Menu, Scale only | How far those eight chords may leave the key. Rebuilt when you leave the menu, not while you play. |
| **In key** | Harmony 0 | Default. Every slot stays in the key and in the degree’s quality. ii cannot become major. |
| **Tensions** | Harmony 1 | Same chords as In key. Slots that were only inversions become 9 / 11 / 13 when that note is in the key and does not fight the 3rd. |
| **Borrowed** | Harmony 2 | The center and the four straight directions stay the Tensions chords. The four diagonals may borrow. |
| **Free** | Harmony 3 | The ring may change quality and leave the key. The center is still the correct triad. Opt-in. |
| **Strum** | Menu | How the strip starts notes. Not a mode. |
| **Optional** | Strum, default | The chord or note sounds on its own. The strip adds plucks if you touch it. Ignore the strip and nothing changes. |
| **Only** | Strum | Keys and Scale stay quiet until the strip. The strip is the only way a note starts. |
| **Key** | Menu | The tonal center, major for now. The next incoming note can set it, and that note is not performed. |
| **Prev / Menu / Next** | The 3 buttons | SW11 GPIO3 / SW9 GPIO4 / SW10 GPIO5. PCB +X is Next. |
| **I+** | Scale keyswitch 8 | Scale degree I, one octave up. |
| **Vary** | Menu, generated notes | How much velocity jitters around the base. 0 = fixed. Keys Optional leaves an incoming note’s velocity alone. |

Code enum: `oc::PlayMode::Keys` and `oc::PlayMode::Scale` (`m1/engine/chord_engine.h`). Saved plugin state still uses 0 and 1, same as the old Pro / Smart numbers.

---

## Modes

Prev / Next **outside the menu** cycle the mode. Changing mode releases every note we sounded, then switches.

| Mode | Hands | Who picks the root | What the 8 keyswitches are | What the trackpad is |
|---|---|---|---|---|
| **Keys** | Piano (or DAW / TRS / USB) plus one hand on the box | Incoming MIDI note | Chord type + extras, combinable | **Bass** (X) and **Spread** (Y). Lift = home voicing |
| **Scale** | Both hands on the box | The keyswitch, from the current key | I–vii, 8th = **I+**. Hold = sound | **Color**. Center = the correct triad. See Harmony |
| **Drums** | Both hands on the box | The hit itself | One drum sound each, two banks | X = bank. Y = velocity at the moment the keyswitch closes |

No keyswitch held in Keys = **Thru**.

Scale layout, near row (toward the edge buttons) first:

| I | ii | iii | IV |
|---|----|-----|----|
| V | vi | vii | I↑ |

Keys layout, same near-row-first order:

| Dim | Min | Maj | Sus |
|-----|-----|-----|-----|
| 6 | m7 | M7 | 9 |

Maj means maj. Extras do nothing without a type. Type is captured at note-on and stays with that key until release.

---

## Notes cannot stick

There is no panic button. Every note-on we emit has one owner. The owner’s release is the note-off.

| Owner | Starts the note | Ends it |
|---|---|---|
| Incoming MIDI note | Keys, trigger = Live | That note’s note-off |
| Keyswitch | Scale, held | Keyswitch up |
| Strip finger | Strum articulation | Finger up, or the armed chord is replaced |

Also flush our notes (not a user-facing control):

- Mode change
- Menu open
- USB suspend / disconnect

A firmware bug can still wedge a note. Hold middle **inside the menu** sends a flush. That is a recovery, not an instrument control. Do not label it on the case.

---

## Keys

Recipe = root (incoming note) + held type/extras + trackpad voicing.

**Trackpad.** Same in every key, including mid-song. X picks bass/inversion (root, 3rd, 5th, 7th if a 7th is already in the chord). Y opens the voicing or pulls it tight. Corners do both. Center and finger-up return to the home voicing of that recipe. Y never changes major into minor.

**Strum** is a menu setting, not a third mode. It applies in Keys and in Scale. There is no off. Optional is the default, so the strip can be ignored.

- **Optional.** Keys: note-on sounds the voiced chord, note-off releases it. Scale: the degree sounds while it is held. Touching the strip adds plucks of that chord. Lift the finger and only those strip notes stop. The chord that was already playing stays until its own release.
- **Only.** Nothing sounds until the strip. Keys: the note and keyswitches arm the chord, the screen shows the name, and a new note replaces that arm. Scale: the held degree is the recipe and does not sound on its own. Letting the degree go clears it. The strip is the same either way.

Strip position 0–255 is split into equal zones, one per note in the current voicing, lowest pitch at the low end. A strum is the order you cross those zones: low to high one way, high to low the other. Entering a zone plucks that note again, so you can strum back and forth without lifting. Staying inside a zone does not repeat it. Lift stops the notes.

---
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

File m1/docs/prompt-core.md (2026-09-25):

# Fresh session — M1 core, plugin as the test bed

Paste this whole file to a new agent. Repo: `/Users/fuglong/Documents/Repos/OpenChord`. Work under `m1/`. Do not edit `archive/` or `s1/`.

## Goal

Build the core of OpenChord M1 and prove it in **OpenChord M Core** (the plugin). There is no board yet. The plugin is the device emulator and the only test bed. A finger on the real box and a click in the plugin must be the same engine
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

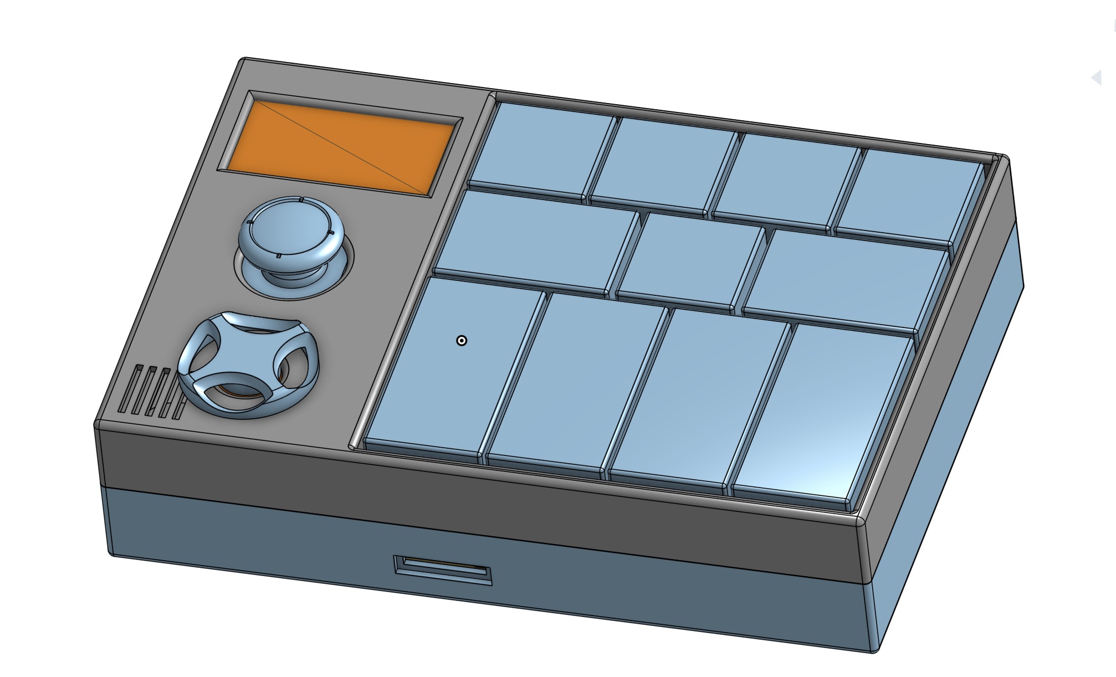
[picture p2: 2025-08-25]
images/Enclosure.jpeg

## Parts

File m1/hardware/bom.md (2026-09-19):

# M1 BOM (rev A)

Matches `OpenChordM1/OpenChordM1.kicad_sch`. Wiring: [`support.md`](support.md). Touch: [`touch.md`](touch.md).

**Hand-build.** 0603 unless noted. Electrodes **U2 / U5** and test pads are copper — not buy items.

Prices from carts **2026-09-19**: [LCSC](https://www.lcsc.com/) `$40.78` + [DigiKey](https://www.digikey.com/) `$29.50` = **`$70.28` for 5**. Every schematic electronic is in one of those two carts. Still buy OLED / Gateron / PCB / cover elsewhere.

## Cost

| | **1 unit** | **5 units** |
|--|---:|---:|
| LCSC + DigiKey carts (MOQ leftovers in) | 14.06 | **70.28** |
| OLED | 1.20 | 6.00 |
| 8× socket + 8× KS-33 | 3.04 | 15.20 |
| 4-layer PCB + DHL | ~10 | ~50 |
| Printed cover | ~2 | ~10 |
| Cart shipping | ~4 | ~20 |
| **Landed (US, no labor)** | **~$34** | **~$171** |

Not included: assembly, stencil, solder, keycaps, scrap, tariffs. **ENIG** for gold touch pads is extra **~$5–8**/board. Qty ~100 is roughly **$16–20**/unit.

Biggest lines: PCB, IQS **$2.07**, QT **$1.93**, 2× TRS **$1.90**, flash **$1.49**, OLED **$1.20**, RP2040 **$1.00**.

---

## ICs

| Qty | Ref | Part | MPN | Pkg | $ | Buy |
|----:|-----|---|-----|-----|--:|-----|
| 1 | U1 | MCU | RP2040 | QFN-56 7×7 | 1.00 | [LCSC C2040](https://www.lcsc.com/product-detail/C2040.html) |
| 1 | U6 | Flash 32 Mbit | W25Q32JVSSIQ | SOIC-8 208 mil | 1.49 | [LCSC C179173](https://www.lcsc.com/product-detail/C179173.html) |
| 1 | Y1 | 12 MHz | ABM8-272-T3 | 3.2×2.5 | 0.63 | [LCSC C20625731](https://www.lcsc.com/product-detail/C20625731.html) |
| 1 | U7 | 3.3 V LDO | AP2112K-3.3TRG1 | SOT-23-5 | 0.17 | [LCSC C51118](https://www.lcsc.com/product-detail/C51118.html) |
| 1 | U8 | USB ESD | USBLC6-2SC6 | SOT-23-6 | 0.18 | [LCSC C7519](https://www.lcsc.com/product-detail/C7519.html) |
| 1 | U3 | Trackpad | IQS572BLQNR | QFN-28 4×4 | 2.07 | [DigiKey](https://www.digikey.com/en/products/detail/azoteq-pty-ltd/IQS572BLQNR/7165004) (KiCad `IQS572-BL-QNR`) |
| 1 | U4 | Cap strip | AT42QT2120-XUR | TSSOP-20 | 1.93 | [DigiKey](https://www.digikey.com/en/products/detail/microchip-technology/AT42QT2120-XUR/3678735) |
| 1 | U9 | MIDI IN opto | TLP2361(TPL,E) | SO6 | 0.53 | [LCSC C107626](https://www.lcsc.com/product-detail/C107626.html) |
| 1 | D1 | MIDI IN clamp | 1N4148WS | SOD-323 | 0.02 | [LCSC C2128](https://www.lcsc.com/product-detail/C2128.html) |
| | | | | | **8.02** | |

Do not buy leftover **W25Q16JV** / C131025. Flash cart qty is **10** (MOQ).

## Connectors & buttons

| Qty | Ref | Part | MPN | Pkg | $ | Buy |
|----:|-----|---|-----|-----|--:|-----|
| 1 | J1 | USB-C | TYPE-C-31-M-12 | SMT+TH | 0.17 | [LCSC C165948](https://www.lcsc.com/product-detail/C165948.html) |
| 2 | J2 OUT, J3 IN | TRS 3.5 mm | SJ1-3523N | TH R/A | 1.90 | [DigiKey](https://www.digikey.com/en/products/detail/same-sky-formerly-cui-devices/SJ1-3523N/738689) |
| 3 | SW9–SW11 | System | EVQPUC02K | SMD side + bosses | 0.53 | [LCSC C79174](https://www.lcsc.com/product-detail/C79174.html) |
| 1 | SW13 | BOOTSEL | TS-1187A-B-A-B | SMD 5.1×5.1 | 0.02 | [LCSC C318884](https://www.lcsc.com/product-detail/C318884.html) |
| | | | | | **2.62** | |

No RUN button on rev A.

## Display, switches, sockets

Not in the LCSC/DigiKey carts.

| Qty | Ref | Part | $ | Buy |
|----:|-----|---|--:|-----|
| 1 | DS1 | OLED 0.91" white SSD1306 4-pin | 1.20 | [AliExpress](https://www.aliexpress.com/w/wholesale-0.91-oled-ssd1306-128x32-white.html) |
| 8 | SW1–SW8 | LP hotswap socket (KS-27 / KS-33) | 1.25 | [Gateron](https://www.gateron.com/products/gateron-low-profile-switch-hot-swap-pcb-socket) · [beekeeb](https://shop.beekeeb.com/products/gateron-low-profile-hotswap-socket-compatible-with-gateron-ks-27-switches-5pcs) |
| 8 | — | KS-33 (KS-27 OK) | 1.79 | [Gateron 35-pack](https://www.gateron.com/products/gateron-ks-33-low-profile-switch-set) |
| | | | **4.24** | |

Sockets are on the schematic; switches plug in after fab. Five boards need **40** sockets and **40** switches (two 35-packs). OLED pinout GND / VCC / SCL / SDA — [`lib/OLED.md`](lib/OLED.md).

## Passives

In the LCSC cart. Equivalents OK if value + package match. Crystal load caps stay **C0G**. 10 µF is **0805**; everything else **0603**.

| /board | Cart | Value | Refs | Use | $ | LCSC |
|---:|-----:|---|---|-----|--:|---|
| 2 | 100 | 22 Ω | R3, R4 | USB D+/D− | 0.00 | [C23345](https://www.lcsc.com/product-detail/C23345.html) |
| 2 | 100 | 5.1 kΩ | R1, R2 | USB-C CC → GND | 0.00 | [C23186](https://www.lcsc.com/product-detail/C23186.html) |
| 16 | 200 | 1 kΩ | R5, R7, R16–R29 | BOOTSEL, XOUT, IQS Tx/Rx | 0.05 | [C21190](https://www.lcsc.com/product-detail/C21190.html) |
| 5 | 100 | 10 kΩ | R6, R13–R15, R30 | RUN PU, QT SNS, QSPI_SS PU | 0.02 | [C98220](https://www.lcsc.com/product-detail/C98220.html) |
| 2 | 100 | 4.7 kΩ | R8, R9 | I2C1 pull-ups | 0.01 | [C23162](https://www.lcsc.com/product-detail/C23162.html) |
| 1 | 100 | 220 Ω | R10 | MIDI IN LED | 0.01 | [C22962](https://www.lcsc.com/product-detail/C22962.html) |
| 1 | 100 | 10 Ω | R11 | MIDI OUT TX → Ring | 0.00 | [C22859](https://www.lcsc.com/product-detail/C22859.html) |
| 1 | 100 | 33 Ω | R12 | MIDI OUT 3V3 → Tip | 0.00 | [C23140](https://www.lcsc.com/product-detail/C23140.html) |
| 6 | 100 | 100 nF | C1, C3–C6, C14 | decoupling | 0.08 | [C14663](https://www.lcsc.com/product-detail/C14663.html) |
| 4 | 100 | 1 µF | C2, C7–C9 | IQS VDDHI/VREG, RP2040 VREG | 0.06 | [C14664](https://www.lcsc.com/product-detail/C14664.html) |
| 2 | 50 | 15 pF C0G | C12, C13 | crystal load | 0.02 | [C1644](https://www.lcsc.com/product-detail/C1644.html) |
| 2 | 40 | 10 µF 0805 | C10, C11 | LDO in / out | 0.13 | [C1713](https://www.lcsc.com/product-detail/C1713.html) |
| | | | | **Consumed / board** | **0.38** | |
| | | | | **Bags / board** (cart ÷ 5) | **1.72** | |

## PCB + cover

**118.95 × 63.15 mm**, 4-layer, **HASL** (KiCad job file may still say ENIG — pick HASL on the order form). [JLCPCB](https://jlcpcb.com/) — **~$10**/board at qty 5. Cover **~$2** filament.

Gerbers: [`fab/jlcpcb/`](fab/jlcpcb/) / zip `fab/OpenChordM1-gerbers.zip`. Stencil: **bottom only**, frameless, **160 × 120 mm**.

---

## Orders (5 boards)

Re-import these CSVs (vendor export format, quantities for 5 boards):

- LCSC: [`carts/OpenChordM1-LCSC-qty5.csv`](carts/OpenChordM1-LCSC-qty5.csv)
- DigiKey: [`carts/OpenChordM1-DigiKey-qty5.csv`](carts/OpenChordM1-DigiKey-qty5.csv)

1. **LCSC `$40.78`** — 22 lines: C2040, C179173 (qty 10), C165948, C51118, C7519, C20625731, C107626, C2128, C79174 (qty 15), C318884 (qty 20), plus the 12 passives above.
2. **DigiKey `$29.50`** — [IQS572BLQNR](https://www.digikey.com/en/products/detail/azoteq-pty-ltd/IQS572BLQNR/7165004) ×5, [AT42QT2120-XUR](https://www.digikey.com/en/products/detail/microchip-technology/AT42QT2120-XUR/3678735) ×5, [SJ1-3523N](https://www.digikey.com/en/products/detail/same-sky-formerly-cui-devices/SJ1-3523N/738689) ×10.
3. 5× OLED; **40** Gateron LP sockets + **40** KS-33 (two 35-packs).
4. JLCPCB 4-layer HASL, ~119 × 63 mm, qty 5, tented vias. Upload `fab/OpenChordM1-gerbers.zip`. Bottom stencil 160 × 120 mm frameless.

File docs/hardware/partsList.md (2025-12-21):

# 🎵 OpenChord Parts List

[← Back to Documentation](../README.md)

### 📋 Overview

This document contains the complete parts list for building the OpenChord hardware.

---

## 🔧 Hardware Components

### 💻 Core Components

| Component | Price | Link | Notes |
|---|---|---|---|
| **Daisy Seed** (64mb) | $24.00 | [electro-smith.com](https://electro-smith.com/products/daisy-seed?variant=45234245108004) | Main microcontroller with audio processing |
| **1.3" OLED Display** (128x64) - Adafruit #938 | $19.95 | [Adafruit](https://www.adafruit.com/product/938?srsltid=AfmBOoqArotUO8oXRElwZ378uK7_5B4PLuVrQ6lUtXmzo5qDvlWPG97c) or [Digikey](https://www.digikey.com/en/products/detail/adafruit-industries-llc/938/5774238) | User interface display |
| **Mini Joystick** - Adafruit #5628 | $4.50 | [Adafruit](https://www.adafruit.com/product/5628) or [Digikey](https://www.digikey.com/en/products/detail/adafruit-industries-llc/5628/21839788) | Navigation control |
| **USB-C Breakout Board** - Adafruit #4090 | $2.95 | [Adafruit](https://www.adafruit.com/product/4090) or [Digikey](https://www.digikey.com/en/products/detail/adafruit-industries-llc/4090/9951930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) | USB connectivity |
| **MicroSD Card Breakout** - Adafruit #4682 | $3.50 | [Adafruit](https://www.adafruit.com/product/4682) or [Digikey](https://www.digikey.com/en/products/detail/adafruit-industries-llc/4682/12822319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) | Storage expansion |
| **3.5mm TRS Female Jack** (Audio out) | $0.85 | [Adafruit](https://www.adafruit.com/product/1699) or [Digikey](https://www.digikey.com/en/products/detail/kycon-inc/STX-3120-5B/9990114) | Audio output |
| **3.5mm TRS Female Jack** (Line in, MIDI in/out) × 3 | $1.73/ea | [Digikey](https://www.digikey.com/en/products/detail/kycon-inc/STX-3790-5N/9990125) | Audio input and MIDI I/O |
| **Wheel Potentiometer** (Volume) | $2.49 | [Digikey](https://www.digikey.com/en/products/detail/alps-alpine/RK10J12E0A0A/21721435) | Volume control |
| **Rotary Encoder** (EC12E2420301 or EC12E2440301) | $2.81 | [Digikey](https://www.digikey.com/en/products/detail/alps-alpine/EC12E2440301/21721630) | Menu navigation |
| **GATERON Low-Profile Key Switches** (35 pcs) | $15.99 | [Amazon](https://a.co/d/7Rx4Xij) | Only 11 used in final design |

---

### 🔋 Extended Components

| Component | Price | Link | Notes |
|---|---|---|---|
| **Electret Microphone Amplifier** - MAX9814 with Auto Gain Control | $7.95 | [Adafruit #1713](https://www.adafruit.com/product/1713) | Microphone amplification |
| **PowerBoost 1000C** (Battery charging + boost) | $19.95 | [Adafruit #2465](https://www.adafruit.com/product/2465) | Battery management |
| **LiPo Battery** (2000mAh) | $12.50 | [Adafruit #2011](https://www.adafruit.com/product/2011) | Portable power |

### 💰 Cost Summary

- **Core Cost**: ~$83.50
- **Total Cost**: ~$119.50

---

## 📚 Component Guides

### 🔊 Audio Output – Simple Voltage Divider

The audio output uses a simple voltage divider to reduce the Daisy Seed's output level so it doesn't blow your ears out.

| Function | Qty | Type | Recommended Value | Notes |
|---|-----|---|---|---|
| **Output Resistors** | 2 | 1% metal film | 4.7kΩ | In series with audio output (targets ~3x reduction) |
| **Ground Resistors** | 2 | 1% metal film | 1kΩ | From audio channels to ground |

---

### 🎛️ Essential Passives

| Component | Qty | Purpose |
|---|-----|---|
| **4.7kΩ Resistors** | 2 | Audio output voltage divider |
| **1kΩ Resistors** | 2 | Audio output to ground |
| **100kΩ Resistor** | 2 | Battery voltage divider (2:1 divider - equal resistors) |

---

### 🎹 MIDI TRS Components

| Component | Qty | Purpose |
|---|-----|---|
| **220Ω Resistor** | 1 | MIDI In current limiting (TRS Tip to UART RX) |
| **2kΩ Resistor** | 1 | Pull-up resistor for UART RX (REQUIRED - +3.3V to UART RX, max 2kΩ for reliable operation) |
| **220Ω Resistor** | 1 | MIDI Out current limiting (Daisy TX to TRS tip) |

**Note:** External 2kΩ pull-up resistor is **required** - 4.7kΩ is too weak, internal pull-ups don't work reliably with UART pins. Direct connection is used (no optocoupler) - STM32H7 UART pins are 5V tolerant.

---

### ⌨️ Key Matrix Components

| Component | Qty | Purpose |
|---|-----|---|
| **1N4148 Diodes** | 15 | Key matrix diodes (one per key) + midi circuit + a few extras |
| **10kΩ Resistors** | 2-3 | Strategic pull-downs (if needed) |

---

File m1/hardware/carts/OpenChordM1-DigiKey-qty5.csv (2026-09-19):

Index | Quantity | Part Number | Manufacturer Part Number | Description | Unit of Measure | Customer Reference | Available | Backorder | Unit Price | Extended Price USD
1 | 10 | CP1-3523N-ND | SJ1-3523N | CONN JACK STEREO 3.5MM R/A |  |  | 10 | 0 | 0.95000 | $9.50
2 | 5 | AT42QT2120-XURCT-ND | AT42QT2120-XUR | IC TOUCH SENSOR 12CH 20TSSOP |  |  | 5 | 0 | 1.93000 | $9.65
3 | 5 | 1790-IQS572BLQNRCT-ND | IQS572BLQNR | 72CH. TRACKPAD/TOUCH SCREEN CONT |  |  | 5 | 0 | 2.07000 | $10.35

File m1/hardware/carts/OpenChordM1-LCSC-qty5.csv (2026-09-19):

Index | LCSC# | MPN | Manufacturer | Package | Customer # | Description | RoHS | Quantity | MOQ | Multiple | Unit Price($) | Extended Price($) | Product Link
1 | C318884 | TS-1187A-B-A-B | XKB Connection | SMD-4P,5.1x5.1mm |  | Tactile Switch SPST 160gf 1.5mm 5.1mm x 5.1mm Surface Mount | yes | 20 | 20 | 20 | 0.0207 | 0.41 | https://www.lcsc.com/product-detail/C318884.html
2 | C79174 | EVQPUC02K | PANASONIC | SMD,4.7x4.5mm |  | Tactile Switch SPST 2.2N 1.65mm PC Pin 4.7mm x 4.5mm Surface Mount, Right Angle | yes | 15 | 5 | 5 | 0.1764 | 2.65 | https://www.lcsc.com/product-detail/C79174.html
3 | C2128 | 1N4148WS | JSCJ | SOD-323 |  | Diode Independent 100V 150mA Surface Mount SOD-323 | yes | 50 | 50 | 50 | 0.0170 | 0.85 | https://www.lcsc.com/product-detail/C2128.html
4 | C107626 | TLP2361(TPL,E | TOSHIBA | SO-5 |  | 6V 10mA 5V 1.5V 2.7V~5.5V DC SO-5 Logic Output Optoisolators RoHS | yes | 5 | 1 | 1 | 0.5272 | 2.64 | https://www.lcsc.com/product-detail/C107626.html
5 | C20625731 | ABM8-272-T3 | ABRACON | SMD3225-4P |  | ±30ppm 10pF ±30ppm SMD3225-4P Crystals RoHS | yes | 5 | 1 | 1 | 0.6255 | 3.13 | https://www.lcsc.com/product-detail/C20625731.html
6 | C7519 | USBLC6-2SC6 | ST | SOT-23-6L |  | 17VC Clamp 5A Ipp ESD DIODE SOT-23-6L | yes | 5 | 5 | 5 | 0.1781 | 0.89 | https://www.lcsc.com/product-detail/C7519.html
7 | C51118 | AP2112K-3.3TRG1 | DIODES | SOT-25-5 |  | 3.3V Positive Fixed SOT-25-5 Voltage Regulators - Linear, Low Drop Out (LDO) Regulators RoHS | yes | 5 | 5 | 5 | 0.1726 | 0.86 | https://www.lcsc.com/product-detail/C51118.html
8 | C2040 | RP2040 | Raspberry Pi | LQFN-56(7x7) |  | ARM Cortex-M0+ 32 Bit 133MHz LQFN-56(7x7) Microcontrollers | yes | 5 | 1 | 1 | 0.9968 | 4.98 | https://www.lcsc.com/product-detail/C2040.html
9 | C179173 | W25Q32JVSSIQ | Winbond | SOIC-8-208mil |  | 32Mbit 2.7V~3.6V 133MHz SPI SOIC-8-208mil Memory RoHS | yes | 10 | 10 | 10 | 1.4929 | 14.93 | https://www.lcsc.com/product-detail/C179173.html
10 | C165948 | TYPE-C-31-M-12 | Korean Hroparts Elec | SMD |  | USB-C (USB TYPE-C) Receptacle Connector 16 Position Surface Mount | yes | 5 | 5 | 5 | 0.1729 | 0.86 | https://www.lcsc.com/product-detail/C165948.html
11 | C23345 | 0603WAF220JT5E | UNI-ROYAL | 0603 |  | 22Ω ±1% 100mW 0603 Thick Film Resistor | yes | 100 | 100 | 100 | 0.0019 | 0.19 | https://www.lcsc.com/product-detail/C23345.html
12 | C23186 | 0603WAF5101T5E | UNI-ROYAL | 0603 |  | 5.1kΩ ±1% 100mW 0603 Thick Film Resistor | yes | 100 | 100 | 100 | 0.0018 | 0.18 | https://www.lcsc.com/product-detail/C23186.html
13 | C21190 | 0603WAF1001T5E | UNI-ROYAL | 0603 |  | 1kΩ ±1% 100mW 0603 Thick Film Resistor | yes | 200 | 100 | 100 | 0.0033 | 0.66 | https://www.lcsc.com/product-detail/C21190.html
14 | C98220 | RC0603FR-0710KL | YAGEO | 0603 |  | 100mW 10kΩ 75V Thick Film Resistor ±100ppm/℃ ±1% 0603 Chip Resistor - Surface Mount RoHS | yes | 100 | 100 | 100 | 0.0035 | 0.35 | https://www.lcsc.com/product-detail/C98220.html
15 | C23162 | 0603WAF4701T5E | UNI-ROYAL | 0603 |  | 4.7kΩ ±1% 100mW 0603 Thick Film Resistor | yes | 100 | 100 | 100 | 0.0047 | 0.47 | https://www.lcsc.com/product-detail/C23162.html
16 | C22962 | 0603WAF2200T5E | UNI-ROYAL | 0603 |  | 220Ω ±1% 100mW 0603 Thick Film Resistor | yes | 100 | 100 | 100 | 0.0051 | 0.51 | https://www.lcsc.com/product-detail/C22962.html
17 | C22859 | 0603WAF100JT5E | UNI-ROYAL | 0603 |  | 10Ω ±1% 100mW 0603 Thick Film Resistor | yes | 100 | 20 | 20 | 0.0035 | 0.35 | https://www.lcsc.com/product-detail/C22859.html
18 | C23140 | 0603WAF330JT5E | UNI-ROYAL | 0603 |  | 33Ω ±1% 100mW 0603 Thick Film Resistor | yes | 100 | 100 | 100 | 0.0028 | 0.28 | https://www.lcsc.com/product-detail/C23140.html
19 | C14663 | CC0603KRX7R9BB104 | YAGEO | 0603 |  | 100nF ±10% 50V Ceramic Capacitor X7R 0603 | yes | 100 | 50 | 50 | 0.0125 | 1.25 | https://www.lcsc.com/product-detail/C14663.html
20 | C14664 | CC0603KRX5R8BB105 | YAGEO | 0603 |  | 1uF ±10% 25V Ceramic Capacitor X5R 0603 | yes | 100 | 100 | 100 | 0.0139 | 1.39 | https://www.lcsc.com/product-detail/C14664.html
21 | C1644 | CL10C150JB8NNNC | Samsung Electro-Mechanics | 0603 |  | 15pF ±5% 50V Ceramic Capacitor C0G 0603 | yes | 50 | 50 | 50 | 0.0115 | 0.58 | https://www.lcsc.com/product-detail/C1644.html
22 | C1713 | CL21A106KOQNNNE | Samsung Electro-Mechanics | 0805 |  | 10uF ±10% 16V Ceramic Capacitor X5R 0805 | yes | 40 | 20 | 20 | 0.0637 | 2.55 | https://www.lcsc.com/product-detail/C1713.html

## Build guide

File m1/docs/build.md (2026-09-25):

# M1 build plan

How we get from the lab plugin to firmware that matches [interaction.md](interaction.md), and a plugin that plays the same instrument with a mouse or whatever MIDI gear someone already owns.

Behavior names and rules live in interaction.md. This file is the order of work, and the status.

## Where we are

The plugin plays steps 1–7. Firmware for rev A compiles and is not flashed. There is no board to run it on yet. **Next is still step 8, on the real board when it exists.**

| Step | Status |
|---|---|
| 1 Surface | Done |
| 2 Modes | Done |
| 3 Menu | Done. Rows, in order: Key, Octave, Vary, Harmony, Strum |
| 4 Vary | Done |
| 5 Drums | Done. Two banks. Labels follow trackpad X. Velocity follows Y, then Vary |
| 6 Color and the strip | Done for Harmony **In key**, and for Strum **Optional** / **Only** in both Keys and Scale |
| 7 Screen | Done in the plugin. Two lines, three bottom slots. Keys with no keyswitch names the chord you played. Scale shows and sounds the newest keyswitch. Firmware prints the same strings in step 8 |
| 8 Firmware | Started, not proven. USB MIDI, UART TRS MIDI, debounced keyswitches and Prev/Menu/Next, and the OLED bitmap compile for the rev A pins and the 4 MB flash. Trackpad and strip are not in yet. Do not flash a Zero |
| 9 Box connected | After a chord works on the desk. Plugin mirrors the box and stops voicing |

Also in the plugin, beside those steps:

- Octave −3 to +3. Scale moves the key. Keys moves a generated chord. A note with no keyswitch stays where it was played.
- Keys, no keyswitch: one note shows as `C4`. Two or more notes show the chord they form, slash bass included.
- Scale: the newest keyswitch is the chord on the screen and in the audio. An older one can stay held and comes back when you let go.
- Latch sticks keyswitches only. Prev, Menu, and Next stay momentary.

Not started on purpose: Harmony past In key (the tables are written, the sound is still In key), other scales, arp, a photo skin, drum rebinding, shortcuts for menu rows. Next work is step 8, not those.

---

## One surface

The engine grows a single input surface. Both hosts call it. Neither host invents a second chord model.

| Control | Engine call | Firmware source | Plugin source |
|---|---|---|---|
| Keyswitch 1–8 | down / up | GPIO in `firmware/board.h` | Mouse click toggles, or any learned note or CC |
| Prev, Menu, Next | down / up | SW11 GPIO3, SW9 GPIO4, SW10 GPIO5 | Mouse click toggles, or any learned note or CC |
| Trackpad X, Y, finger | −1..+1, touching or not | IQS572 | Mouse drag, value stays, or two learned CCs (joystick axes count) |
| Strip position, finger | 0–255, touching or not | QT2120 | Mouse drag, value stays, or one learned CC (mod wheel, ribbon, fader) |

What a keyswitch *means* depends on the mode (Keys type, Scale degree, Drums hit). The binding does not. Learn once, switch mode, same physical control.

GPIO, I2C, and TinyUSB stay in `m1/firmware`. JUCE stays in `m1/plugin`. `m1/engine` stays free of both.

---

## Plugin, specifically

Someone with other MIDI gear should get the same gestures without our box.

**Play and bind are different.** A plugin-only **Bind** button enters bind mode. It does not exist on the box. Outside bind mode, the picture of the device is an instrument.

- A click is momentary: mouse down is held, mouse up is released. A plugin-only **Latch** control, or holding Option or Control, sticks keyswitches for testing without hardware. Prev, Menu, and Next never stick.
- Drag the trackpad, then let go. The position stays, and the finger stays down, so Keys voicing does not snap home. The strip plays while the mouse is down and lifts on release, which stops its notes.
- **Bind** (plugin only): click it, then click the control to assign (a keyswitch, a button, trackpad X, trackpad Y, or the strip). The next MIDI message becomes that binding. Clicks in this mode do not play. Click Bind again to cancel. A successful assign leaves bind mode.
- Every keyswitch and every button learns **one** message: a note, or a CC. Channel can be any, or one channel. Value ≥ 64 means held. A piano key, a pad, or a button on their controller are all legal.
- The trackpad learns **two** CCs, X and Y, as two separate assigns. A joystick that sends two axes is the normal case.
- The strip learns **one** CC. Mod wheel is a good default to offer, not a requirement.
- One message binds to one control. Binding it again moves it.
- Right-click, while Bind is on, clears that control. A reset restores a named Launchkey preset (their pads → keyswitches 1–8, two knobs → trackpad). That preset is a convenience, not the product model.
- The on-screen labels follow the mode: Dim…9, or I…I+, or the drum names. In Drums the names follow trackpad X (left kit, or the right kit when X is positive). The learned MIDI stays put underneath. Labels are drawn from surface state, so a later USB link can light the same controls.

When a real M1 is on USB, the plugin stops calling the engine and mirrors the device. That is later in this plan. Until that detection exists, the plugin is the instrument.

---

## Order

Each step is done when the plugin can play it with the mouse and with learned MIDI, before any of it depends on the new board.

### 1. Surface — done

Replace the Launchkey-shaped control list (`Dim`, `Panic`, `Shift`, stick) with the table above. Keep Keys Live behavior working through the new calls: keyswitches still select Dim / Min / Maj / Sus / 6 / m7 / M7 / 9, trackpad X/Y still voice, no keyswitch held still means Thru.

Done when the existing Logic path still works: learned note + C on the keyboard = C major, no keyswitch = the raw note, and a mouse click latches Maj without holding the button. Bind is the only way to learn.

### 2. Modes and the three buttons — done

Prev / Next cycle **Keys → Scale → Drums → Keys**. Menu opens and closes. Changing mode or opening the menu releases every note we sounded.

Scale keyswitches are I–vii and I+, hold to sound, as the lab plugin already does. Drums can be a stub that only changes the labels until step 5.

Done when the mouse can change mode and the eight labels change with it, and a stuck note does not survive the change.

### 3. Menu settings the engine actually reads — done

On-screen menu, same settings as the box: **Key**, **Octave**, **Vary**, **Harmony**, **Strum** (Optional / Only). Trackpad horizontal drag changes the value while the menu is open. Prev / Next move between settings. Menu closes and applies.

Key can also be set by the next incoming note while that row is open, and that note is not performed.

Harmony and Strum may be stored before the music uses them. Vary can be a no-op until step 4. The point of this step is that firmware and plugin will share this state later.

### 4. Generated velocity — done

Keys Optional keeps the incoming velocity. Vary does not touch it.

Scale and Strum use base velocity 100, then Vary. Drums, once it exists, takes base velocity from trackpad Y at the keyswitch press (top 127, bottom 1, center 100), then Vary.

### 5. Drums — done

Channel 10. Default notes from interaction.md. Trackpad X at press picks the bank (left default kit, right the second kit). Press = note-on, release = note-off. Mouse and learned notes both work.

Per-keyswitch rebinding waits. The default kit has to be worth playing first.

### 6. Color, then the strip — done

Scale trackpad becomes Color, using the eight-chord tables in interaction.md. Each direction is one chord. The center is always that degree’s triad. This step ships Harmony `In key` only. Tensions, Borrowed, and Free are already specified there and wait until In key feels right. The table rebuilds when the menu closes, not while a keyswitch is held. The axis mix that is in the plugin now (7th on Y, inversion on X) is not the map.

Then Strum. Optional is the default in Keys and Scale: the chord sounds, and the strip adds plucks. Only keeps Keys and Scale quiet until the strip. A dwell is one chord tone, a swipe follows the finger, and entering a zone plucks again. Finger up is note-off of the strip notes only.

### 7. Screen model — done in the plugin

The two lines in [interaction.md](interaction.md) (Screen). The engine builds the strings. The top line is centered. The bottom line is key, mode, and status, with a divider between them. The plugin draws that in a 128×32 box. Firmware will print those same strings. No picture of the enclosure until a photo exists.

### 8. Firmware on the rev A board

Pins are `m1/firmware/board.h`, checked against the PCB nets.

1. USB MIDI device named `OpenChord M1`. It enumerates and can send a note.
2. Eight keyswitches and three buttons into the surface. OLED shows the two lines over I2C1 (`0x3C`).
3. IQS572 trackpad (`0x74`, RDY GPIO8, NRST GPIO9) and QT2120 strip (`0x1C`) into trackpad and strip.
4. UART0 MIDI at 31250. GPIO0 TX out, GPIO1 RX in. Same surface as USB. Notes we emit go out both ports.

Play a chord on the desk before worrying about the plugin connection.

### 9. Box connected

Plugin sees `OpenChord M1` on USB. It stops voicing. It still shows the two lines and the same controls. The box is the only thing calling the engine. A press on the box lights the matching control. A click or menu edit in the plugin is the same surface event the box applies. One copy of mode, key, Vary, Harmony, Strum, and trackpad position. Unplug and the plugin voices again on its own.

---

## Not in this plan

Notes-row mode, arp, scales other than major, Harmony past `In key`, a photo skin, drum rebinding, the circular trackpad wheel. They wait until Keys, Scale at `In key`, Drums, and Strum are boring on the plugin and then on the board. Scale uses the same strip as Keys: the newest held degree is the recipe.

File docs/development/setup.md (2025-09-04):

# Development Setup Guide

[← Back to Documentation](../README.md)

## Prerequisites

- **Daisy Toolchain**: Install the Daisy toolchain from [Daisy Toolchain](https://daisy.audio/tutorials/cpp-dev-env/)
- **Git**: Make sure you have Git installed
- **Make**: Ensure you have Make installed (usually comes with development tools)

## Repository Setup

### 1. Clone the Repository

```bash
git clone https://github.com/your-username/OpenChord.git
cd OpenChord
```

### 2. Initialize Submodules

The project uses Git submodules for the Daisy libraries. You need to initialize and update them:

```bash
# Initialize submodules
git submodule init

# Update submodules to get the actual library files
git submodule update
```

**Note**: If you cloned with `--recursive`, you can skip this step as submodules will be automatically initialized.

### 3. Verify Setup

Check that the libraries are properly downloaded:

```bash
ls -la lib/
# Should show:
# libDaisy/  DaisySP/
```

## Building the Project

### First Build (Build Libraries)

The first build will take longer as it needs to compile the Daisy libraries:

```bash
# Clean any previous builds
make clean

# Build the project
make
```

### Subsequent Builds

After the first build, subsequent builds will be faster:

```bash
make
```

## VS Code Integration

The project includes VS Code tasks that match the Daisy examples structure. These tasks are available in the Command Palette (`Ctrl+P` / `Cmd+P`):

### Available Tasks

- **`build_all`**: Build the project (default build task)
- **`build_and_program_dfu`**: Build and flash via USB (DFU mode)
- **`build_and_program`**: Build and flash via debug probe
- **`clean`**: Clean build artifacts
- **`program-dfu`**: Flash via USB (requires Daisy in bootloader mode)
- **`program`**: Flash via debug probe

### Using VS Code Tasks

1. **Open the project** in VS Code
2. **Connect your Daisy Seed** via USB or debug probe
3. **Put Daisy in bootloader mode** (if using USB):
   - Hold BOOT button, press RESET, release RESET, then release BOOT
4. **Run tasks** via Command Palette:
   - Press `Ctrl+P` (Windows/Linux) or `Cmd+P` (Mac)
   - Type the task name (e.g., `task build_and_program_dfu`)
   - Press Enter

### Windows Terminal Setup

If you're on Windows, make sure VS Code is using Git Bash as the default terminal:

1. Open VS Code Terminal (`View > Terminal`)
2. Click the `+` dropdown in the terminal
3. Select `Select Default Profile`
4. Choose `Git Bash`

This ensures proper command execution for the build tasks.

## Project Structure

```
OpenChord/
├── docs/                 # Documentation
│   ├── architecture/    # System architecture
│   ├── development/     # Development guides
│   ├── hardware/        # Hardware documentation
│   └── overview/        # Project overview
├── src/                 # Source code
│   ├── main.cpp        # Application entry point
│   ├── core/           # Core system files
│   │   ├── audio/      # Audio processing
│   │   │   ├── audio_engine.cpp/h
│   │   │   ├── volume_manager.cpp/h
│   │   │   └── volume_interface.h
│   │   ├── io/         # Input/Output management
│   │   │   ├── io_manager.cpp/h
│   │   │   ├── analog_manager.cpp/h
│   │   │   ├── digital_manager.cpp/h
│   │   │   ├── display_manager.cpp/h
│   │   │   ├── serial_manager.cpp/h
│   │   │   ├── storage_manager.cpp/h
│   │   │   └── pin_config.h
│   │   ├── midi/       # MIDI handling
│   │   │   ├── midi_handler.cpp/h
│   │   │   ├── midi_hub.cpp
│   │   │   ├── midi_interface.h
│   │   │   ├── midi_types.h
│   │   │   └── trs_midi_handler.h
│   │   ├── tracks/     # Track management
│   │   │   ├── track.cpp
│   │   │   └── track_interface.h
│   │   ├── storage/    # Data storage
│   │   ├── ui/         # User interface
│   │   ├── plugin_interface.h
│   │   └── system_interface.h
│   └── plugins/        # Plugin implementations
│       ├── fx/         # Audio effects
│       ├── input/      # Input plugins
│       ├── instruments/ # Instrument plugins
│       └── playmodes/  # Playback modes
├── lib/                # External libraries (submodules)
│   ├── libDaisy/       # Daisy hardware library
│   └── DaisySP/        # Daisy audio processing library
├── hardware/           # Hardware design files
├── images/             # Project images and diagrams
├── tests/              # Test files
├── build/              # Build artifacts (ignored by git)
├── Makefile            # Build configuration
├── .gitmodules         # Submodule configuration
├── .gitignore          # Git ignore rules
├── LICENSE             # Project license
└── README.md           # Project overview
```

## Development Workflow

1. **Make changes** to source files in `src/`
2. **Build** with `make` or VS Code task `build_all`
3. **Test** on hardware using `build_and_program_dfu` or `build_and_program`
4. **Commit** your changes

## Troubleshooting

### Submodule Issues

If you encounter submodule-related issues:

```bash
# Reset submodules to their proper state
git submodule deinit -f .
git submodule update --init --recursive
```

### Build Issues

If the build fails:

```bash
# Clean everything and rebuild
make clean
cd lib/libDaisy && make clean && make
cd ../DaisySP && make clean && make
cd ../.. && make
```

### Windows Build Issues

If you get errors like:
```
mkdir build
process_begin: CreateProcess(NULL, mkdir build, ...) failed.
```

Make sure you're using Git Bash as your terminal in VS Code (see Windows Terminal Setup above).

### Large Repository Size

The repository is designed to be lightweight. The actual library files are downloaded via submodules, so:

- **Repository size**: ~1-2MB (just source code and docs)
- **After submodule init**: ~50-100MB (includes all library source)
- **After first build**: ~200-300MB (includes compiled libraries)

## IDE Setup

### VS Code (Recommended)

The project includes VS Code configuration files with tasks that match the Daisy examples structure. Open the project in VS Code and:

1. Install the **Cortex Debug** extension for debugging
2. Use the provided tasks for building and flashing
3. Make sure to use Git Bash on Windows

### Other IDEs

You can use any C++ IDE. Make sure to:
- Set the include paths to include `include/`, `lib/libDaisy/src/`, and `lib/DaisySP/Source/`
- Configure the build system to use the Makefile

## Contributing

When contributing:

1. **Fork** the repository
2. **Create** a feature branch
3. **Make** your changes
4. **Test** thoroughly using the VS Code tasks
5. **Submit** a pull request

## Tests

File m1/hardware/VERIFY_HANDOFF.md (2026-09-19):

# OpenChord M1 — Hardware verification handoff

**Purpose:** Give a fresh agent (or human) enough context to re-verify schematic + PCB.  
**Date context:** 2026-09-19, KiCad 10.0.6, rev A **ordered** (4-layer HASL, qty 5).  
**Owner intent:** Finger-on-PCB capacitive UI (soldermask over electrodes, tented sense vias), 4-layer, UI-dense top / everything else bottom.

**2026-09-19 pre-order:** DRC **0 shorts, 0 unconnected, 0 schematic_parity**. USB-C J1 and TRS J2/J3 moved; bushings off-board. Gerbers in `fab/jlcpcb/`. Remaining DRC is USB-C/IQS pad pitch, silk-on-edge, OLED courtyard vs jack PTH, starved thermals (1 spoke). Not blockers.

---

## 1. Product / electrical intent (locked)

| Block | Intent |
|---|---|
| MCU | RP2040 + W25Q32JVSSIQ ([C179173](https://www.lcsc.com/product-detail/C179173.html)) QSPI + 12 MHz crystal |
| Power | USB-C VBUS → AP2112K-3.3 → `+3.3V` (EN tied to VIN) |
| USB | J1 TYPE-C-31-M-12 (C165948) + USBLC6 + 22Ω series + CC 5.1k→GND |
| Display | 0.91" SSD1306 OLED I²C `0x3C` |
| Trackpad | IQS572 + 7×7 diamond matrix, I²C `0x74`, **RDY required** |
| Slider | QT2120 **strip only** KEY0–2, I²C `0x1C`, MODE→GND, RESET→3V3 |
| Keys | 8× Gateron LP → GPIO (internal pull-ups) |
| System | 3× EVQPUC02K side → GPIO (roles TBD) |
| BOOTSEL | Strap `~QSPI_SS` through **R5 1 kΩ** to GND via TS-1187A (not a user GPIO); **R30 10 kΩ** SS→3V3 (populated) |
| MIDI | Type A TRS: OUT tip=3V3 via 33Ω, ring=TX via 10Ω; IN tip→220Ω→TLP2361 AN, ring→CAT, VO→RX |
| I²C | **I2C1** GPIO10 SDA / GPIO11 SCL, 4.7 kΩ×2; OLED `0x3C` + QT `0x1C` + IQS `0x74`; IQS RDY GPIO8, NRST GPIO9 |
| Updates | After first flash, firmware can `reset_usb_boot()` for buttonless UF2; BOOTSEL kept for recovery |

**Docs match the rev A schematic** (`support.md` is the as-built pin/passive map). If they ever disagree, prefer **live schematic/netlist**.

**Paths:**
- Sch: `m1/hardware/OpenChordM1/OpenChordM1.kicad_sch`
- PCB: `m1/hardware/OpenChordM1/OpenChordM1.kicad_pcb`
- Libs: `m1/hardware/lib/` (`oc-*`, `captouch`, `easyeda/`)

---

## 2. How to re-verify (procedure)

1. Export schematic netlist:
   ```bash
   kicad-cli sch export netlist --format kicadsexpr \
     -o /tmp/oc_sch.sexpr m1/hardware/OpenChordM1/OpenChordM1.kicad_sch
   ```
2. Run ERC + DRC with schematic parity:
   ```bash
   kicad-cli sch erc -o /tmp/oc_erc.json --format json --severity-all ...
   kicad-cli pcb drc -o /tmp/oc_drc.json --format json --schematic-parity --severity-all ...
   ```
3. Walk **every active** in §4 against datasheet pin tables (not just “nets look connected”).
4. Confirm RP2040 mux: I²C / UART pins must match pico-sdk function table.
5. Confirm switch **poles** against the **datasheet**, not against “pads on the same side of the footprint.” For TS-1187A, commons are **top 1+2 / bottom 3+4**.
6. Spot-check PCB: ratsnest clear, zones refill, keepouts under trackpad+slider on internal planes, sense series R near chips.

**Known noisy ERC/DRC:** EasyEDA “Unspecified” pin types → `pin_to_pin` spam; captouch via/pad annular quirks; courtyard/silk on dense UI. User believes remaining are false positives or intentional — **re-check, don’t blindly trust.**

---

## 3. Snapshot findings (2026-09-19 pre-order)

### Schematic ↔ PCB
- DRC **schematic_parity: 0 issues** at last audit.
- **C5 GND** open and a **GND zone island** were found then **fixed** (trace to via; pour connectivity).
- **GPIO3** was briefly shorted to **+3.3V** by a via after R30 at ~(133.90, 54.18) — **fixed** by moving the via to ~(134.50, 53.58) (~0.64 mm clearance). Re-check DRC shorts = 0 before fab.

### Critical / cleared

#### C1 — BOOTSEL SW13 poles — **CLEARED (was a false alarm)**
- Part: `TS-1187A-B-A-B`. XKB datasheet + EasyEDA symbol: **top 1+2** one pole, **bottom 3+4** other; press bridges top↔bottom.
- Footprint geometry is left/right columns, but **electrical commons are top/bottom rows**, not left/right.
- Netlist: **pad1=GND** (top), **pad3→R5→`~QSPI_SS`** (bottom) = opposite poles → **correct**.
- Optional hygiene: also tie pad2 to GND and pad4 to the R5 net (both pads of each pole).
- **Do not** re-open this as “1+3 same pole” — that was an agent mistake from assuming side-commons.

#### C2 — (Cleared) QT2120 pin numbers
- Earlier false alarm compared **VQFN** pinout to **TSSOP** symbol.
- Part is **AT42QT2120-XUR** + footprint `TSSOP-20_...`.
- Microchip **TSSOP/SOIC** table matches EasyEDA symbol: 11=VDD, 12=MODE, 13=SDA, 14=RESET, 16=SCL.
- Still verify PCB pin-1 marker / rotation against TSSOP package drawing before fab.

### High / medium follow-ups
| ID | Item | Notes |
|----|---|---|
| H1 | IQS572 **NRST→GPIO9** | Chip has **internal NRST pull-up**; OK if GPIO floats briefly. FW must release/drive high early. Optional: external PU to 3V3. |
| H2 | IQS572 **RDY→GPIO8** | Required for reliable I²C on shared bus — confirm still wired. |
| M1 | QT **CHANGE** open | OK if polling I²C. |
| M2 | QT **RESET→+3.3V** | Correct per datasheet when not MCU-driven. |
| M3 | I2C1 (not I2C0) | **Docs updated.** GPIO10/11 = I2C1 mux — firmware must use I2C1. |
| M4 | Series R refdes | **Docs updated.** Strip **R13–R15 10 kΩ**; trackpad **R16–R29 1 kΩ**; **R30** is QSPI_SS pull-up. |
| M5 | No RUN button | Optional; RUN has R6 10 kΩ to 3V3. |
| M6 | GPIO7,14–16,19–23 unused | Fine spare. |
| M7 | IQS **C2 = 1 µF** on VDDHI; **C7 = 1 µF** on VREG (cap to GND only). Optional 100 pF across C7 skipped. |

### Blocks that looked correct at audit
| Block | Result |
|---|---|
| RP2040 power (IOVDD, VIN, VOUT↔DVDD×2, USB_VDD, ADC_AVDD, TESTEN→GND, RUN↑) | PASS |
| Crystal + 15pF + 1k on XOUT | PASS |
| QSPI flash map (incl. pad54=SD2→WP, pad55=SD1→DO) | PASS |
| USB ESD + 22Ω + CC + LDO | PASS |
| I²C bus + 4.7k pull-ups on GPIO10/11 | PASS (I2C1) |
| MIDI OUT Type A + GPIO0 UART0 TX | PASS |
| MIDI IN opto + GPIO1 UART0 RX | PASS |
| 8× Gateron + 3× EVQ to GPIOs | PASS |
| SWD / VBUS / GND testpoints | PASS |
| IQS Rx0–6/Tx0–6 + 1k; QT KEY0–2 + 10k; MODE→GND | PASS |

### GPIO map (audit snapshot — re-extract if sch changed)

| GPIO | Function |
|---|---|
| 0 | MIDI OUT (UART0 TX) |
| 1 | MIDI IN (UART0 RX) |
| 2 | SW5 Gateron |
| 3 | SW11 EVQ |
| 4 | SW9 EVQ |
| 5 | SW10 EVQ |
| 6 | SW7 Gateron |
| 7 | unused |
| 8 | IQS RDY |
| 9 | IQS NRST |
| 10 | I2C1 SDA |
| 11 | I2C1 SCL |
| 12 | SW8 Gateron |
| 13 | SW6 Gateron |
| 14–16 | unused |
| 17 | SW4 Gateron |
| 18 | SW2 Gateron |
| 19–23 | unused |
| 24 | SW1 Gateron |
| 25 | SW3 Gateron |
| 26–29 | open (ADC-capable spare / Alps fallback) |

**Mux cheat-sheet:** GPIO10/11 = I2C1 SDA/SCL ✓ · GPIO0/1 = UART0 TX/RX ✓ · GPIO8/9 = plain GPIO (RDY/NRST) ✓

---

## 4. Active-by-active datasheet checklist

Use this as the slow pass. For each: open MPN datasheet, confirm every pin.

### U1 RP2040
- [ ] All IOVDD → 3V3 (stacked symbol OK; all pads must hit pour)
- [ ] VREG_VIN → 3V3 + 1µF
- [ ] VREG_VOUT ↔ both DVDD + 1µF (**not** 3V3)
- [ ] USB_VDD, ADC_AVDD → 3V3
- [ ] TESTEN → GND
- [ ] RUN ↑ 10k to 3V3
- [ ] Flash QSPI wiring per datasheet pad numbers
- [ ] USB DM/DP through series R
- [ ] Assigned UART/I2C pins exist in mux table

### U6 W25Q32JVSSIQ (LCSC [C179173](https://www.lcsc.com/product-detail/C179173.html))
- [ ] CS/CLK/DI/DO/WP/HOLD ↔ SS/SCLK/SD0/SD1/SD2/SD3
- [ ] VCC 3V3, GND; local decoupling nearby
- [ ] SOIC-8 208 mil (`Package_SO:SOIC-8_5.3x5.3mm_P1.27mm`); buy **C179173**

### Y1 ABM8-272-T3
- [ ] Load caps to GND; series R on XOUT path as designed

### U7 AP2112K-3.3
- [ ] VIN=VBUS, EN=VIN or high, VOUT=3V3, bulk in/out

### U8 USBLC6-2SC6
- [ ] Connector-side D+/D− to I/Os; chip-side through 22Ω to MCU; VBUS pin to VBUS

### J1 TYPE-C-31-M-12 (C165948)
- [ ] VBUS **A4B9** + **B4A9**; GND **A1B12** + **B1A12** + shell **EH 1–4**
- [ ] CC1 **A5** and CC2 **B5** each 5.1k→GND (not tied to each other)
- [ ] DP1 **A6** ↔ DP2 **B6**; DN1 **A7** ↔ DN2 **B7**; SBU A8/B8 NC

### U9 TLP2361 + D1 + MIDI jacks
- [ ] IN: Tip→220→AN, Ring→CAT, diode reverse across LED, VO→RX, VCC+100nF
- [ ] OUT Type A: Tip←33←3V3, Ring←10←TX, Sleeve GND

### U3 IQS572
- [ ] VDDHI 3V3 + **1 µF** (C2); VSS/EP GND; VREG **1 µF** to GND only (C7)
- [ ] SDA/SCL on bus; **RDY→GPIO**; NRST OK open or GPIO with internal PU
- [ ] Rx0–6 / Tx0–6 only (unused open); series 1k each
- [ ] PGM/SW_IN open OK

### U4 QT2120-XUR (TSSOP)
- [ ] Use **TSSOP** pin table (not VQFN)
- [ ] MODE→GND (I²C), RESET→VDD, SDA/SCL on bus
- [ ] KEY0–2 → strip via 10k; other KEY open
- [ ] CHANGE optional

### DS1 OLED
- [ ] GND/VCC/SCL/SDA order matches module (`lib/OLED.md`)

### SW1–8 Gateron / SW9–11 EVQ / SW13 BOOT
- [ ] Keys: GPIO↔GND with MCU pull-ups
- [ ] BOOT: **opposite poles**, R5 1 kΩ on SS side, **R30 10 kΩ** SS→3V3

---

## 5. Layout / fab notes (non-netlist)

- Keepouts under **sense** copper (trackpad diamonds + slider KEY0–2) on **internal** GND/PWR planes. Slider **GND end chevrons** (U2 pads 4–5) may sit **outside** keepout so parts can share that area — intentional.
- Backside parts under trackpad: series Rs OK; avoid noisy MCU under trackpad matrix if possible; under slider is riskier but may be necessary.
- Captouch thru-hole vias: tent by removing `*.Mask` from via pads in footprint (user may have done this).
- Bare-finger soldermask-over-copper is intentional; rev A finish is **HASL** (not ENIG).
- Optional later: ENIG + open mask on electrodes if gold feel is needed.
- 4-layer `Sig–GND–PWR–Sig` (In1 GND, In2 3.3 V). SMT on B.Cu.
- TRS: hang **SJ1-3523N** bushings off Edge.Cuts; do not sit the barrel on FR4.
- Gerbers: `m1/hardware/fab/jlcpcb/`. Stencil: bottom, frameless, 160 × 120 mm.

---

## 6. Firmware assumptions to document for software

- I²C peripheral: **I2C1** on GPIO10/11 (not I2C0).
- UART0 MIDI on GPIO0 TX / GPIO1 RX @ 31250.
- Drive/release IQS NRST (GPIO9) high after boot; poll/wait IQS RDY (GPIO8).
- QT: enable slider on channels 0–2; RESET is hard-tied high; CHANGE unconnected (poll I²C).
- Implement `reset_usb_boot()` for web UF2 updates; keep physical BOOTSEL for recovery.
- **R30** is populated 10 kΩ on `~QSPI_SS`. No RUN button.
- Flash is **4 MB** (`W25Q32JVSSIQ`, LCSC [C179173](https://www.lcsc.com/product-detail/C179173.html)); set `PICO_FLASH_SIZE_BYTES=4*1024*1024`. Default `boot2_w25q080`.

---

## 7. Fresh-agent prompt (copy/paste)

```text
Read m1/hardware/VERIFY_HANDOFF.md fully. Re-export the live schematic netlist and
PCB DRC with --schematic-parity. Independently verify every checklist item in §4.
Note: C1 BOOTSEL poles were a false alarm — datasheet is top 1+2 / bottom 3+4.
Do not revive the left/right commons claim. Produce a short PASS/FAIL table;
only edit hardware if the user asks.
```

---

## 8. Pass criteria for “fab OK”

- [ ] BOOTSEL continuity: SS↔GND **only while pressed**, through 1k (poles top/bottom)
- [ ] QT footprint orientation / pin-1 verified against TSSOP drawing
- [ ] RDY still on a GPIO; I2C1 pins still valid pair
- [ ] MIDI UART pins still valid TX/RX pair
- [ ] Schematic parity clean; DRC shorts = 0; any leftover unconnected/GND items understood
- [ ] Zone keepouts present under capacitive electrodes
- [ ] Firmware pin map matches §GPIO table (or table updated)

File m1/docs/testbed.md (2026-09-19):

# M1 testbed

How we prove the chord engine before the custom M1 PCB exists.

**Do not edit [`archive/s1-daisy/`](../../archive/s1-daisy/).** That tree is the restore image for the original prototype. Never commit changes there.

**Pins: match the firmware that runs, not the archive docs.** `docs/hardware/pinout.md` and `src/core/io/pin_config.h` are stale. The box matches `Init()` in `digital_manager.cpp`, `analog_manager.cpp`, `display_manager.cpp`, and `midi_handler.cpp`. Copy of that map: [`../proto-daisy/pin_map.h`](../proto-daisy/pin_map.h). Do not copy `pin_config.h` into the harness.

## What we are not doing

- Not the Seed enclosure USB for MIDI. That port is done. OG firmware is back on the box.
- Not ESP32-C3. USB MIDI on C3 is a trap.
- Not putting this in `s1/`. S1 is the future studio product.

## Order

1. **`m1/engine`** — portable C. Host tests on a laptop. MIDI in/out can be fake. The logic is the product.
2. **`m1/proto-rp2040`** — Waveshare RP2040-Zero, PlatformIO. USB-C = MIDI device. Launchkey Mini MK4 pads/knobs fake the Pro cluster and stick.
3. Play until C–Am–F–G never sounds stupid and ideas start showing up.
4. **`m1/plugin`** — **OpenChord M Core**, same engine in AU MIDI FX + VST3. Learn + extra settings. Skip voicing if a hardware M1 is present.
5. **`m1/firmware`** — same engine on the custom PCB. USB device only. No host on the SKU. No pots. **QT2120 strip only**; **3× EVQPUC02K** for Key / Shift / Mode (roles TBD). **I2C1** on GPIO10/11. See [`../hardware/support.md`](../hardware/support.md).
6. The Seed box stays on archived OG firmware unless we explicitly go back.

If the engine is wrong on a laptop, the enclosure will not save it. If it is right on a laptop and wrong on the Seed, the harness is wrong, not the music.

## Restore the OG prototype

From repo root, with Daisy toolchain and submodules:

```bash
cd archive/s1-daisy
git submodule update --init --recursive
make
# flash with the usual Daisy / dfu flow from that tree
```

Do this once **before** the first proto-daisy flash if you want a known-good `.bin` on disk. Keep that binary out of `archive/` (put it in `m1/proto-daisy/restore/` locally if you want; it does not need to be committed).

## Seed box → M1 controls

Matrix is **3 rows × 4 cols** (11 keys). Row 0 = bottom, row 1 = middle (col 3 unused), row 2 = top. From `digital_manager.cpp` + `button_input_handler.cpp`.

| Where | Matrix | M1 |
|---|---|-----|
| Bottom 4 | row 0, col 0–3 | Dim, Min, Maj, Sus |
| Middle 3 | row 1, col 0–2 | 6, m7, M7 |
| Top INPUT | row 2, col 0 | **9** |
| Top INSTRUMENT | row 2, col 1 | **Key** |
| Top FX | row 2, col 2 | **Shift** |
| Top RECORD | row 2, col 3 | unused / panic |
| Stick X/Y | A2 / A3 | 8 voicing seats |
| Stick click | D0 pin 1 | spice, later |
| OLED | SPI as in pin_map.h | `Cmaj7` / `C major` |
| USB MIDI | EXTERNAL pins 36–37 | roots in, chords out |
| Encoder, audio, battery | — | ignore |

Do not port archive chord-mapping presets onto this map.

## USB MIDI (RP2040-Zero)

Native USB-C on the Zero is the MIDI **device**. Launchkey Mini MK4 pads (ch 10 CC 36–43) are types. Knobs CC 47/48 are the stick. Type is locked per key until that key is released.

Build/flash: [`../proto-rp2040/README.md`](../proto-rp2040/README.md).

Playtest routing:

1. Zero USB-C into the Mac. Device name: **OpenChord M1**.
2. Launchkey / DAW MIDI **into OpenChord** (do not also send those notes to the instrument).
3. OpenChord MIDI **out to the instrument track**.

No type at note-on = thru. Type held at note-on = that key becomes a chord until it is released. Later keys do not steal an already-held chord.

## Pins the harness must use

From the manager `.cpp` files, not `pin_config.h`:

| Function | Daisy | Header pin |
|---|---|---|
| Joy X / Y | A2 / A3 | 24 / 25 |
| Joy click | D0 | 1 |
| Key rows bottom→top | D20, D21, D22 | 27, 28, 29 |
| Key cols 0–3 | D23, D24, D25, D26 | 30–33 |
| OLED CS / SCK / MOSI | D7 / D8 / D10 | 8 / 9 / 11 |
| OLED DC / RST | D13 / D14 | 14 / 15 |
| TRS MIDI RX / TX | PB8 / PB9 (D11 / D12) | 12 / 13 |
| Encoder A / B | D27 / D28 | 34 / 35 |

Stale `pin_config.h` still says joy click D14, display DC on D0, MIDI as D12/D13-the-names, and a 4-row matrix. That is not the box.

## Product hardware (not this testbed)

RP2040 on our PCB, USB-C on our edge, Gateron LP × 8, **IQS572BLQNR** trackpad + **AT42QT2120-XUR** strip only, **3× EVQPUC02K** system (roles TBD; Alps stick is a lib fallback, not on rev A), no pots / SoftPot, Ali OLED on **I2C1**. Free plugin is the settings surface. See [`../hardware/`](../hardware/).

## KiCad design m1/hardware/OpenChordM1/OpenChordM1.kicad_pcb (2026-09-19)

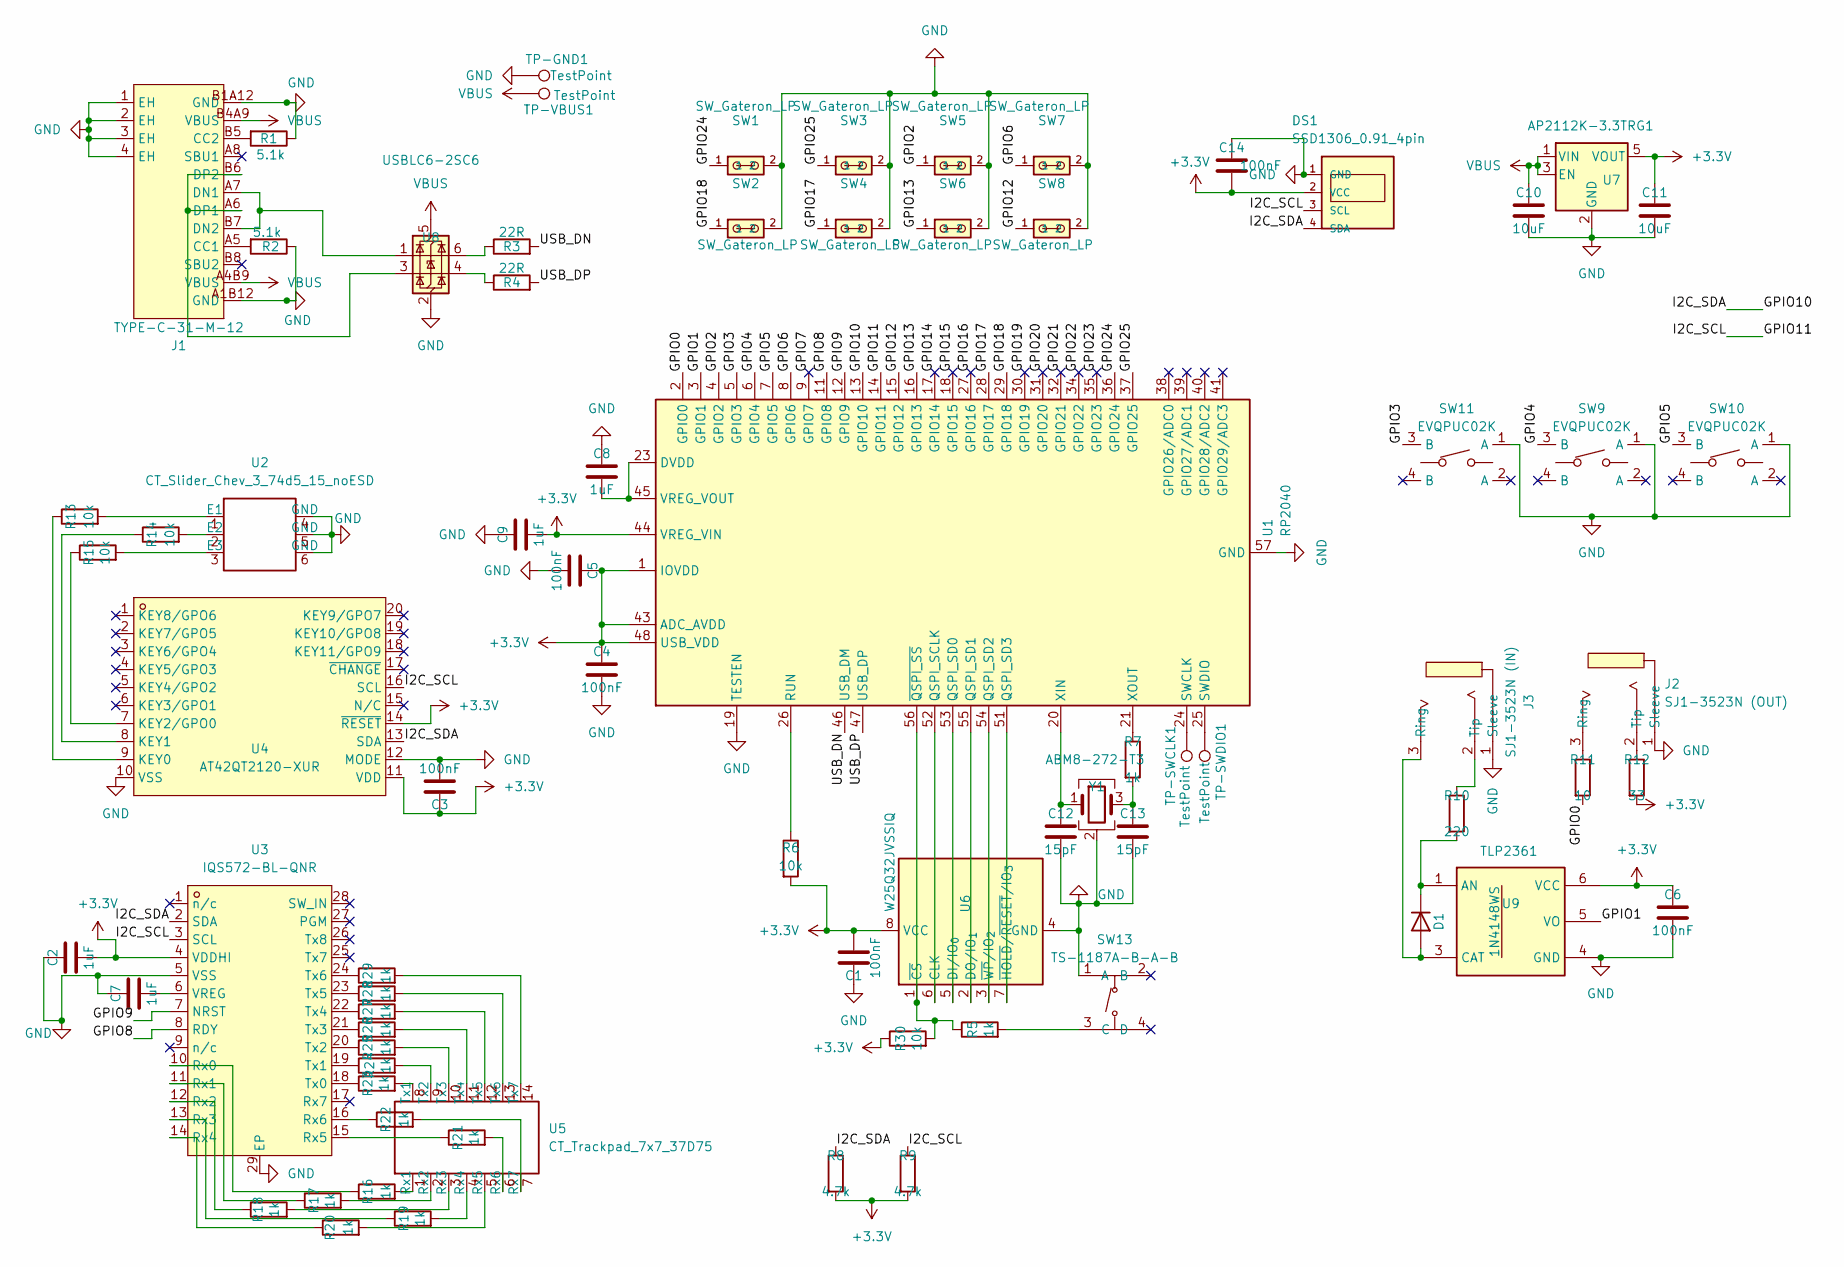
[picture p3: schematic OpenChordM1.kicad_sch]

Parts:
C1, C3, C4, C5, C6, C14: 100nF; C_0603_1608Metric; MPN CC0603KRX7R9BB104; LCSC Part C14663
C2, C7, C8, C9: 1uF; C_0603_1608Metric; MPN CC0603KRX5R8BB105; LCSC Part C14664
C10, C11: 10uF; C_0805_2012Metric; MPN CL21A106KOQNNNE; LCSC Part C1713
C12, C13: 15pF; C_0603_1608Metric; MPN CL10C150JB8NNNC; LCSC Part C1644
D1: 1N4148WS; D_SOD-323; MPN 1N4148WS; LCSC Part C2128
DS1: SSD1306_0.91_4pin; SSD1306-0.91-OLED-4pin-128x32; MPN SSD1306 0.91in 4-pin
J1: TYPE-C-31-M-12; MPN TYPE-C-31-M-12; LCSC Part C165948
J2: SJ1-3523N (OUT); SJ1-3523N; MPN SJ1-3523N; LCSC Part C20182914
J3: SJ1-3523N (IN); SJ1-3523N; MPN SJ1-3523N; LCSC Part C20182914
R1, R2: 5.1k; R_0603_1608Metric; MPN 0603WAF5101T5E; LCSC Part C23186
R3, R4: 22R; R_0603_1608Metric; MPN 0603WAF220JT5E; LCSC Part C23345
R5, R7, R16, R17, R18, R19, R20, R21, R22, R23, R24, R25, R26, R27, R28, R29: 1k; R_0603_1608Metric; MPN 0603WAF1001T5E; LCSC Part C21190
R6, R13, R14, R15, R30: 10k; R_0603_1608Metric; MPN RC0603FR-0710KL; LCSC Part C98220
R8, R9: 4.7k; R_0603_1608Metric; MPN 0603WAF4701T5E; LCSC Part C23162
R10: 220; R_0603_1608Metric; MPN 0603WAF2200T5E; LCSC Part C22962
R11: 10; R_0603_1608Metric; MPN 0603WAF100JT5E; LCSC Part C22859
R12: 33; R_0603_1608Metric; MPN 0603WAF330JT5E; LCSC Part C23140
SW1, SW2, SW3, SW4, SW5, SW6, SW7, SW8: SW_Gateron_LP; Gateron-KS33-Hotswap-1U; MPN KS-33 hotswap socket
SW9, SW10, SW11: EVQPUC02K; MPN EVQPUC02K; LCSC Part C79174
SW13: TS-1187A-B-A-B; MPN TS-1187A-B-A-B; LCSC Part C318884
TP-GND1: TestPoint; TestPoint_Pad_D1.5mm
TP-SWCLK1: TestPoint; TestPoint_Pad_D1.5mm
TP-SWDIO1: TestPoint; TestPoint_Pad_D1.5mm
TP-VBUS1: TestPoint; TestPoint_Pad_D1.5mm
U1: RP2040; QFN-56-1EP_7x7mm_P0.4mm_EP3.2x3.2mm; MPN RP2040; LCSC Part C2040
U2: CT_Slider_Chev_3_74d5_15_noESD
U3: IQS572-BL-QNR; QFN-28_L4.0-W4.0-P0.50-TL; MPN IQS572-BL-QNR; LCSC Part C3827635
U4: AT42QT2120-XUR; TSSOP-20_L6.5-W4.4-P0.65-LS6.4-BL; MPN AT42QT2120-XUR; LCSC Part C1522278
U5: CT_Trackpad_7x7_37D75
U6: W25Q32JVSSIQ; SOIC-8_5.3x5.3mm_P1.27mm; MPN W25Q32JVSSIQ; LCSC Part C179173
U7: AP2112K-3.3TRG1; SOT-23-5; MPN AP2112K-3.3TRG1; LCSC Part C51118
U8: USBLC6-2SC6; SOT-23-6; MPN USBLC6-2SC6; LCSC Part C7519
U9: TLP2361; MPN TLP2361(TPL,E); LCSC Part C107626
Y1: ABM8-272-T3; Crystal_SMD_3225-4Pin_3.2x2.5mm; MPN ABM8-272-T3; LCSC Part C20625731

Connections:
+3.3V: C1.2, C2.2, C3.1, C4.1, C5.1, C6.1, C9.2, C11.1, C14.2, DS1.2 (VCC), R6.2, R8.2, R9.2, R12.2, R30.1, U1.1 (IOVDD), U1.10 (IOVDD), U1.22 (IOVDD), U1.33 (IOVDD), U1.42 (IOVDD), U1.43 (ADC_AVDD), U1.44 (VREG_VIN), U1.48 (USB_VDD), U1.49 (IOVDD), U3.4 (VDDHI), U4.11 (VDD), U4.14 (~RESET), U6.8 (VCC), U7.5 (VOUT), U9.6 (VCC)
/GPIO0: R11.2, U1.2 (GPIO0)
/GPIO1: U1.3 (GPIO1), U9.5 (VO)
/GPIO2: SW5.1, U1.4 (GPIO2)
/GPIO3: SW11.3 (B), U1.5 (GPIO3)
/GPIO4: SW9.3 (B), U1.6 (GPIO4)
/GPIO5: SW10.3 (B), U1.7 (GPIO5)
/GPIO6: SW7.1, U1.8 (GPIO6)
/GPIO7: U1.9 (GPIO7)
/GPIO8: U1.11 (GPIO8), U3.8 (RDY)
/GPIO9: U1.12 (GPIO9), U3.7 (NRST)
/GPIO10: DS1.4 (SDA), R8.1, U1.13 (GPIO10), U3.2 (SDA), U4.13 (SDA)
/GPIO11: DS1.3 (SCL), R9.1, U1.14 (GPIO11), U3.3 (SCL), U4.16 (SCL)
/GPIO12: SW8.1, U1.15 (GPIO12)
/GPIO13: SW6.1, U1.16 (GPIO13)
/GPIO14: U1.17 (GPIO14)
/GPIO15: U1.18 (GPIO15)
/GPIO16: U1.27 (GPIO16)
/GPIO17: SW4.1, U1.28 (GPIO17)
/GPIO18: SW2.1, U1.29 (GPIO18)
/GPIO19: U1.30 (GPIO19)
/GPIO20: U1.31 (GPIO20)
/GPIO21: U1.32 (GPIO21)
/GPIO22: U1.34 (GPIO22)
/GPIO23: U1.35 (GPIO23)
/GPIO24: SW1.1, U1.36 (GPIO24)
/GPIO25: SW3.1, U1.37 (GPIO25)
/USB_DN: R3.2, U1.46 (USB_DM)
/USB_DP: R4.2, U1.47 (USB_DP)
GND: C1.1, C2.1, C3.2, C4.2, C5.2, C6.2, C7.1, C8.1, C9.1, C10.2, C11.2, C12.2, C13.2, C14.1, DS1.1 (GND), J1.1 (EH), J1.2 (EH), J1.3 (EH), J1.4 (EH), J1.A1B12 (GND), J1.B1A12 (GND), J2.1 (Sleeve), J3.1 (Sleeve), R1.1, R2.1, SW1.2, SW2.2, SW3.2, SW4.2, SW5.2, SW6.2, SW7.2, SW8.2, SW9.1 (A), SW10.1 (A), SW11.1 (A), SW13.1 (A), TP-GND1.1 (1_1), U1.19 (TESTEN), U1.57 (GND), U2.4 (GND), U2.5 (GND), U2.6 (GND), U3.5 (VSS), U3.29 (EP), U4.10 (VSS), U4.12 (MODE), U6.4 (GND), U7.2 (GND), U8.2 (GND), U9.4 (GND), Y1.2 (G), Y1.4 (G)
unnamed: C13.1, R7.2, Y1.3
unnamed: D1.2 (A), J3.3 (Ring), U9.3 (CAT)
unnamed: D1.1 (K), R10.2, U9.1 (AN)
unnamed: J1.A5 (CC1), R2.2
unnamed: J1.B5 (CC2), R1.2
unnamed: J1.A7 (DN1), J1.B7 (DN2), U8.1 (I/O1)
unnamed: J1.A6 (DP1), J1.B6 (DP2), U8.3 (I/O2)
unnamed: J2.3 (Ring), R11.1
unnamed: J2.2 (Tip), R12.1
unnamed: J3.2 (Tip), R10.1
unnamed: R3.1, U8.6 (I/O1)
unnamed: R4.1, U8.4 (I/O2)
unnamed: R5.2, SW13.3 (C)
unnamed: U1.52 (QSPI_SCLK), U6.6 (CLK)
unnamed: U1.53 (QSPI_SD0), U6.5 (DI/IO_{0})
unnamed: U1.55 (QSPI_SD1), U6.2 (DO/IO_{1})
unnamed: U1.54 (QSPI_SD2), U6.3 (~WP/IO_{2})
unnamed: U1.51 (QSPI_SD3), U6.7 (~HOLD/~RESET/IO_{3})
unnamed: R6.1, U1.26 (RUN)
unnamed: TP-SWCLK1.1 (1_1), U1.24 (SWCLK)
unnamed: TP-SWDIO1.1 (1_1), U1.25 (SWDIO)
unnamed: C8.2, U1.23 (DVDD), U1.45 (VREG_VOUT), U1.50 (DVDD)
unnamed: C12.1, U1.20 (XIN), Y1.1
unnamed: R7.1, U1.21 (XOUT)
unnamed: R5.1, R30.2, U1.56 (~QSPI_SS), U6.1 (~CS)
unnamed: R13.2, U2.1 (E1)
unnamed: R14.2, U2.2 (E2)
unnamed: R15.2, U2.3 (E3)
unnamed: R16.1, U3.10 (Rx0)
unnamed: R17.1, U3.11 (Rx1)
unnamed: R18.1, U3.12 (Rx2)
unnamed: R19.1, U3.13 (Rx3)
unnamed: R20.1, U3.14 (Rx4)
unnamed: R21.1, U3.15 (Rx5)
unnamed: R22.1, U3.16 (Rx6)
unnamed: R23.1, U3.18 (Tx0)
unnamed: R24.1, U3.19 (Tx1)
unnamed: R25.1, U3.20 (Tx2)
unnamed: R26.1, U3.21 (Tx3)
unnamed: R27.1, U3.22 (Tx4)
unnamed: R28.1, U3.23 (Tx5)
unnamed: R29.1, U3.24 (Tx6)
unnamed: C7.2, U3.6 (VREG)
unnamed: R13.1, U4.9 (KEY0)
unnamed: R14.1, U4.8 (KEY1)
unnamed: R15.1, U4.7 (KEY2/GPO0)
unnamed: R16.2, U5.1 (Rx1)
unnamed: R17.2, U5.2 (Rx2)
unnamed: R18.2, U5.3 (Rx3)
unnamed: R19.2, U5.4 (Rx4)
unnamed: R20.2, U5.5 (Rx5)
unnamed: R21.2, U5.6 (Rx6)
unnamed: R22.2, U5.7 (Rx7)
unnamed: R23.2, U5.8 (Tx1)
unnamed: R24.2, U5.9 (Tx2)
unnamed: R25.2, U5.10 (Tx3)
unnamed: R26.2, U5.11 (Tx4)
unnamed: R27.2, U5.12 (Tx5)
unnamed: R28.2, U5.13 (Tx6)
unnamed: R29.2, U5.14 (Tx7)
VBUS: C10.1, J1.A4B9 (VBUS), J1.B4A9 (VBUS), TP-VBUS1.1 (1_1), U7.1 (VIN), U7.3 (EN), U8.5 (VBUS)

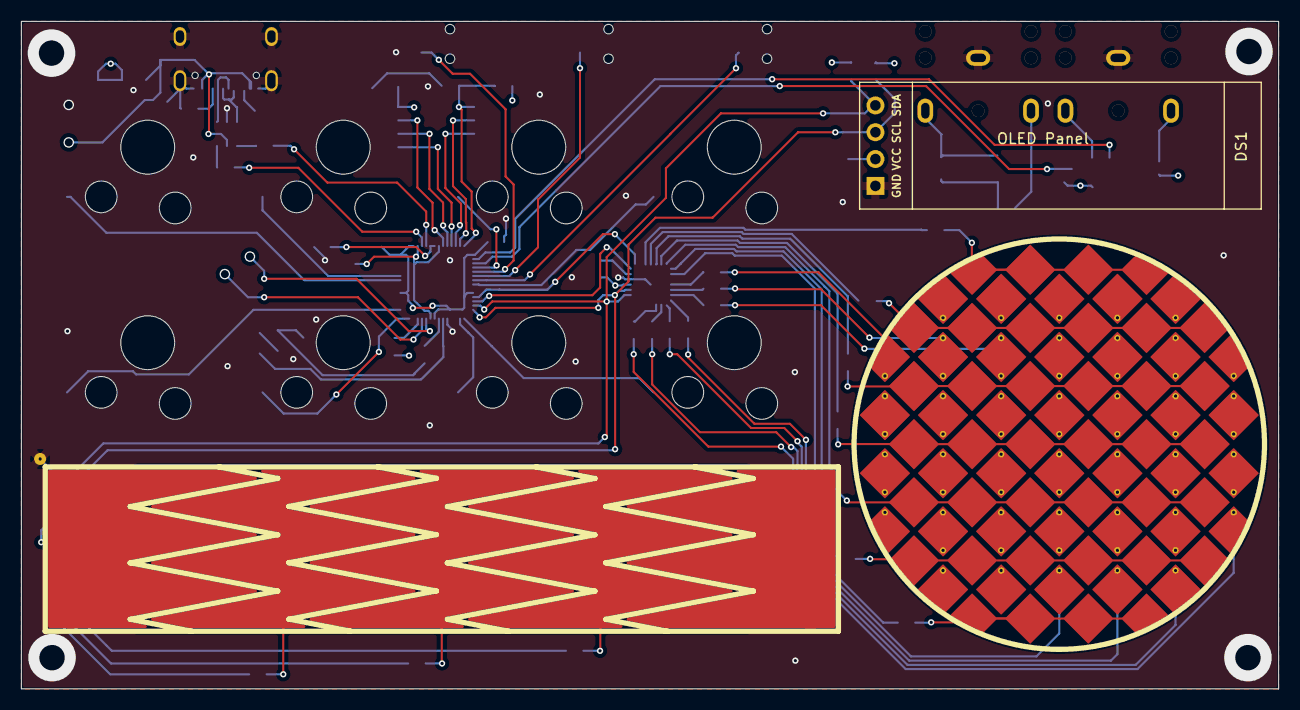
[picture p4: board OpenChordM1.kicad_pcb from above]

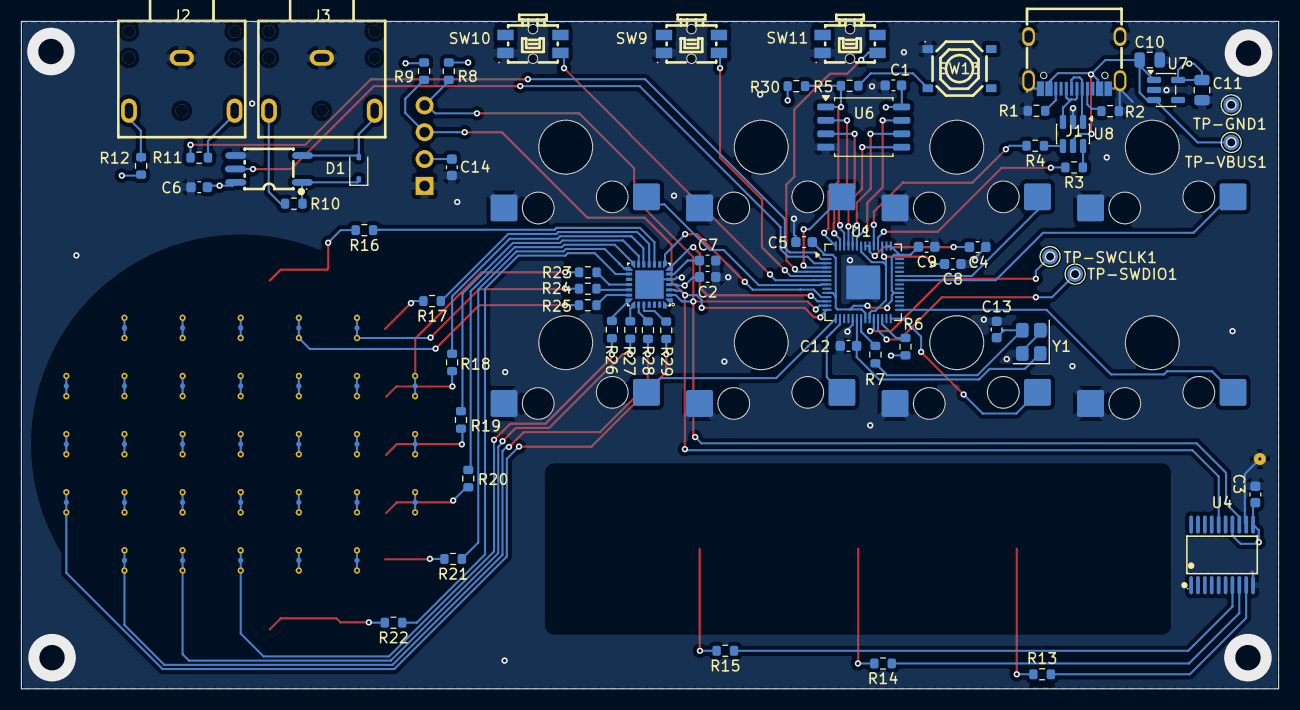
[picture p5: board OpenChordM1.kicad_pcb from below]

Board: 4 copper layers, 119.0 x 63.1 mm, 75 parts (72 on the bottom side), 82 nets.

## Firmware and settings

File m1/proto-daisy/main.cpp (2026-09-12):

#include "daisy_seed.h"
#include "dev/oled_ssd130x.h"
#include "hid/logger.h"
#include "pin_map.h"
#include "chord_engine.h"

using namespace daisy;
using namespace m1proto;

// Same port as OG: enclosure USB-C = D29/D30 = FS_EXTERNAL, not the Seed micro-USB.
using ExternalLog = Logger<LOGGER_EXTERNAL>;

static DaisySeed hw;

static GPIO row_gpio[3];
static GPIO col_gpio[4];
static GPIO joy_sw;
static AdcChannelConfig adc_cfg[2];

static OledDisplay<SSD130x4WireSpi128x64Driver> oled;
static MidiUsbHandler usb_midi;

static constexpr int kRows = 3;
static constexpr int kCols = 4;

static bool key_now[3][4];

static oc::Voicing sounding;
static oc::Voicing last_voicing;
static int16_t held_roots[16];
static int held_n = 0;
static uint8_t held_vel = 100;
static uint8_t out_ch = 0;
static uint8_t key_pc = 0;
static bool key_arm = false;
static bool chord_mode = false;
static bool panic_was = false;

static const Pin kRowsPins[3] = {PinMap::KEY_ROW_0, PinMap::KEY_ROW_1, PinMap::KEY_ROW_2};
static const Pin kColsPins[4] = {PinMap::KEY_COL_0, PinMap::KEY_COL_1, PinMap::KEY_COL_2,
                                 PinMap::KEY_COL_3};

static bool ValidKey(int r, int c) { return !(r == 1 && c == 3); }

// Same busy-wait as archive digital_manager.cpp (Seed ~480 MHz).
static void DelayUs(uint32_t us) {
    volatile uint32_t count = us * 120;
    while (count--) {
        __asm__("nop");
    }
}

static void ScanMatrix() {
    for (int r = 0; r < kRows; ++r) row_gpio[r].Write(true);
    DelayUs(10);
    for (int r = 0; r < kRows; ++r) {
        row_gpio[r].Write(false);
        DelayUs(5);
        for (int c = 0; c < kCols; ++c) {
            if (!ValidKey(r, c)) continue;
            key_now[r][c] = !col_gpio[c].Read();
        }
        row_gpio[r].Write(true);
        DelayUs(5);
    }
}

static bool Pressed(int r, int c) { return ValidKey(r, c) && key_now[r][c]; }

static oc::Type CurrentType() {
    oc::Type t = oc::Type::None;
    if (Pressed(0, 0)) t = oc::Type::Dim;
    if (Pressed(0, 1)) t = oc::Type::Min;
    if (Pressed(0, 2)) t = oc::Type::Maj;
    if (Pressed(0, 3)) t = oc::Type::Sus;
    return t;
}

static uint8_t CurrentExt() {
    uint8_t e = 0;
    if (Pressed(1, 0)) e |= oc::Ext6;
    if (Pressed(1, 1)) e |= oc::Extm7;
    if (Pressed(1, 2)) e |= oc::ExtM7;
    if (Pressed(2, 0)) e |= oc::Ext9;
    return e;
}

static bool KeyHeld() { return Pressed(2, 1); }
static bool ShiftHeld() { return Pressed(2, 2); }
static bool PanicHeld() { return Pressed(2, 3); }

static void MidiSend(uint8_t status, uint8_t d0, uint8_t d1) {
    uint8_t b[3] = {status, d0, d1};
    usb_midi.SendMessage(b, 3);
}

static void NotesOff(const oc::Voicing& v) {
    for (uint8_t i = 0; i < v.n; ++i) {
        MidiSend(static_cast<uint8_t>(0x80 | out_ch), v.notes[i], 0);
    }
}

static void NotesOn(const oc::Voicing& v, uint8_t vel) {
    if (vel == 0) vel = 1;
    for (uint8_t i = 0; i < v.n; ++i) {
        MidiSend(static_cast<uint8_t>(0x90 | out_ch), v.notes[i], vel);
    }
}

static void ThruOn(int16_t note, uint8_t vel) {
    MidiSend(static_cast<uint8_t>(0x90 | out_ch), static_cast<uint8_t>(note), vel);
}

static void ThruOff(int16_t note) {
    MidiSend(static_cast<uint8_t>(0x80 | out_ch), static_cast<uint8_t>(note), 0);
}

static void ThruOffHeld() {
    for (int i = 0; i < held_n; ++i) ThruOff(held_roots[i]);
}

static void ThruOnHeld() {
    for (int i = 0; i < held_n; ++i) ThruOn(held_roots[i], held_vel);
}

static void Panic() {
    NotesOff(sounding);
    sounding.n = 0;
    ThruOffHeld();
    chord_mode = false;
    MidiSend(static_cast<uint8_t>(0xB0 | out_ch), 123, 0);
}

static int16_t CurrentRoot() {
    if (held_n <= 0) return -1;
    return held_roots[held_n - 1];
}

static void PushRoot(int16_t n) {
    for (int i = 0; i < held_n; ++i) {
        if (held_roots[i] == n) return;
    }
    if (held_n < 16) held_roots[held_n++] = n;
}

static void PopRoot(int16_t n) {
    int w = 0;
    for (int i = 0; i < held_n; ++i) {
        if (held_roots[i] != n) held_roots[w++] = held_roots[i];
    }
    held_n = w;
}

static void EmitChord() {
    oc::EngineInput in{};
    in.root_midi = CurrentRoot();
    in.type = CurrentType();
    in.ext = CurrentExt();
    in.key_pc = key_pc;
    in.velocity = held_vel;
    if (in.root_midi < 0 || in.type == oc::Type::None) return;

    float x = (hw.adc.GetFloat(0) - 0.5f) * 2.0f;
    float y = (0.5f - hw.adc.GetFloat(1)) * 2.0f; // invert: stick-up = musical up
    in.seat = oc::SeatFromStick(x, y, 0.42f);

    oc::Voicing next{};
    oc::Render(in, sounding.n ? &sounding : &last_voicing, &next);

    bool same = (next.n == sounding.n);
    if (same) {
        for (uint8_t i = 0; i < next.n; ++i) {
            if (next.notes[i] != sounding.notes[i]) same = false;
        }
    }
    if (same) return;

    NotesOff(sounding);
    sounding = next;
    if (sounding.n) last_voicing = sounding;
    NotesOn(sounding, held_vel);
}

static const char* KeyName(uint8_t pc) {
    static const char* n[12] = {
        "C", "C#", "D", "D#", "E", "F", "F#", "G", "G#", "A", "A#", "B"};
    return n[pc % 12];
}

static void Draw() {
    oled.Fill(false);
    oled.SetCursor(0, 0);
    oled.WriteString("OpenChord M1", Font_6x8, true);
    oled.SetCursor(0, 16);
    if (sounding.n && sounding.name[0]) {
        oled.WriteString(sounding.name, Font_11x18, true);
    } else if (CurrentType() == oc::Type::None) {
        oled.WriteString("(hold type)", Font_6x8, true);
    } else {
        oled.WriteString("...", Font_11x18, true);
    }
    oled.SetCursor(0, 40);
    oled.WriteString(KeyName(key_pc), Font_6x8, true);
    oled.SetCursor(48, 40);
    oled.WriteString("major", Font_6x8, true);
    oled.SetCursor(0, 52);
    oled.WriteString(key_arm ? "KEY" : "usb midi", Font_6x8, true);
    oled.Update();
}

static void HandleIncoming(const MidiEvent& ev) {
    if (ev.type != MidiMessageType::NoteOn && ev.type != MidiMessageType::NoteOff) {
        return;
    }
    uint8_t note = ev.data[0];
    uint8_t vel = ev.data[1];
    out_ch = static_cast<uint8_t>(ev.channel & 0x0f);
    bool on = (ev.type == MidiMessageType::NoteOn) && vel > 0;

    if (on && KeyHeld()) {
        key_pc = static_cast<uint8_t>(note % 12);
        return;
    }

    if (on) {
        held_vel = vel;
        PushRoot(static_cast<int16_t>(note));
    } else {
        PopRoot(static_cast<int16_t>(note));
    }

    // Thru only when no type is held. Chord emit happens in the main loop
    // so we never note-off a thru root after the chord is already on.
    if (CurrentType() == oc::Type::None) {
        if (on) ThruOn(static_cast<int16_t>(note), vel);
        else ThruOff(static_cast<int16_t>(note));
    }
}

static void AudioCallback(AudioHandle::InputBuffer in,
                          AudioHandle::OutputBuffer out,
                          size_t size) {
    (void)in;
    for (size_t i = 0; i < size; ++i) {
        out[0][i] = 0.f;
        out[1][i] = 0.f;
    }
}

int main(void) {
    hw.Init();

    // OG order on this box (system_initializer.cpp + midi_handler.cpp):
    // 1) LOGGER_EXTERNAL StartLog — USB PHY on D29/D30 as CDC
    // 2) display / IO
    // 3) MidiUsbHandler EXTERNAL — usbd_mode = MIDI, same port
    // 4) StartAudio
    // Daisy's HS device descriptor is always CDC; MIDI is a descriptor switch
    // on that stack. OG never inits MIDI without the logger bring-up first.
    ExternalLog::StartLog(false);
    hw.DelayMs(50);

    for (int r = 0; r < kRows; ++r) {
        row_gpio[r].Init(kRowsPins[r], GPIO::Mode::OUTPUT, GPIO::Pull::NOPULL);
        row_gpio[r].Write(true);
    }
    for (int c = 0; c < kCols; ++c) {
        col_gpio[c].Init(kColsPins[c], GPIO::Mode::INPUT, GPIO::Pull::PULLUP);
    }
    joy_sw.Init(PinMap::JOY_SW, GPIO::Mode::INPUT, GPIO::Pull::PULLUP);

    adc_cfg[0].InitSingle(PinMap::JOY_X);
    adc_cfg[1].InitSingle(PinMap::JOY_Y);
    hw.adc.Init(adc_cfg, 2);
    hw.DelayMs(20);
    hw.adc.Start();

    OledDisplay<SSD130x4WireSpi128x64Driver>::Config dcfg;
    dcfg.driver_config.transport_config.spi_config.periph = SpiHandle::Config::Peripheral::SPI_1;
    dcfg.driver_config.transport_config.spi_config.baud_prescaler =
        SpiHandle::Config::BaudPrescaler::PS_8;
    dcfg.driver_config.transport_config.spi_config.pin_config.sclk = PinMap::OLED_SCK;
    dcfg.driver_config.transport_config.spi_config.pin_config.miso = Pin();
    dcfg.driver_config.transport_config.spi_config.pin_config.mosi = PinMap::OLED_MOSI;
    dcfg.driver_config.transport_config.spi_config.pin_config.nss = PinMap::OLED_CS;
    dcfg.driver_config.transport_config.pin_config.dc = PinMap::OLED_DC;
    dcfg.driver_config.transport_config.pin_config.reset = PinMap::OLED_RST;
    oled.Init(dcfg);
    oled.Fill(false);
    oled.Update();

    MidiUsbHandler::Config mcfg;
    mcfg.transport_config.periph = MidiUsbTransport::Config::EXTERNAL;
    mcfg.transport_config.tx_retry_count = 3;
    usb_midi.Init(mcfg);
    usb_midi.StartReceive();

    hw.StartAudio(AudioCallback);

    sounding.n = 0;
    last_voicing.n = 0;
    uint32_t last_draw = 0;
    (void)ShiftHeld;
    (void)joy_sw;

    while (1) {
        ScanMatrix();

        bool panic = PanicHeld();
        if (panic && !panic_was) Panic();
        panic_was = panic;

        key_arm = KeyHeld();

        usb_midi.Listen();
        int guard = 0;
        while (usb_midi.HasEvents() && guard++ < 64) {
            HandleIncoming(usb_midi.PopEvent());
        }

        bool want_chord = CurrentType() != oc::Type::None && held_n > 0;
        if (want_chord) {
            if (!chord_mode) {
                ThruOffHeld();
                chord_mode = true;
            }
            EmitChord();
        } else if (chord_mode) {
            NotesOff(sounding);
            sounding.n = 0;
            chord_mode = false;
            ThruOnHeld();
        }

        uint32_t now = System::GetNow();
        if (now - last_draw > 100) {
            Draw();
            last_draw = now;
        }

        hw.DelayMs(1);
    }
}

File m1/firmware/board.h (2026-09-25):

#pragma once

// Rev A netlist, taken from OpenChordM1.kicad_pcb footprint nets (not from memory).
// Pressed = low. Internal pull-up. Other switch pole is GND.
//
// Keyswitch grid, PCB +X to the right, the 3 buttons toward -Y:
//   SW11   SW9    SW10     Prev / Menu / Next
//   SW1    SW3    SW5    SW7
//   SW2    SW4    SW6    SW8
//
// Keys labels, near row then far row: Dim Min Maj Sus / 6 m7 M7 9
// Scale labels: I ii iii IV / V vi vii I+

namespace ocboard {

constexpr int kKeyswitchCount = 8;

// Index 0..7 is SW1..SW8 (schematic reference order).
constexpr int kKeyswitchGpio[kKeyswitchCount] = {
    24, // SW1
    18, // SW2
    25, // SW3
    17, // SW4
    2,  // SW5
    13, // SW6
    6,  // SW7
    12, // SW8
};

// Spatial index: row-major, near row (toward the 3 buttons) first, left to right.
// 0 SW1, 1 SW3, 2 SW5, 3 SW7, 4 SW2, 5 SW4, 6 SW6, 7 SW8
constexpr int kKeyswitchSpatialSw[kKeyswitchCount] = {1, 3, 5, 7, 2, 4, 6, 8};

constexpr int kPrevGpio = 3; // SW11, -X end of the edge row
constexpr int kMenuGpio = 4; // SW9, middle
constexpr int kNextGpio = 5; // SW10, +X end of the edge row

constexpr int kI2cSda = 10; // I2C1
constexpr int kI2cScl = 11;
constexpr int kIqsRdy = 8;
constexpr int kIqsNrst = 9;

// Hardware UART0, not a PIO or bit-banged port. support.md MIDI Type A.
// OUT J2: GPIO0 TX → 10 Ω → ring. Tip is 3V3 through 33 Ω. TX high is idle (no current).
// IN J3: TLP2361 VO → GPIO1 RX. LED on pulls VO low, which is a UART 0. Do not invert.
constexpr int kMidiTx = 0;
constexpr int kMidiRx = 1;

constexpr uint8_t kOledAddr = 0x3C;
constexpr uint8_t kQtAddr = 0x1C;
constexpr uint8_t kIqsAddr = 0x74;

} // namespace ocboard

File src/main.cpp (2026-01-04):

#include "daisy_seed.h"
#include "daisysp.h"
#include "core/config.h"
#include "core/io/io_manager.h"
#include "core/io/input_manager.h"
#include "core/io/storage_manager.h"
#include "core/io/power_manager.h"
#include "core/audio/volume_manager.h"
#include "core/audio/audio_engine.h"
#include "core/midi/midi_handler.h"
#include "core/midi/midi_interface.h"
// Note: track_interface.h includes plugin_interface.h which includes midi_types.h
// This defines a different MidiEvent than midi_interface.h
// We'll use the track system's MidiEvent (from midi_types.h) via the Track interface
#include "core/tracks/track_interface.h"
#include "core/system_interface.h"
#include "core/ui/main_ui.h"
#include "core/ui/ui_manager.h"
#include "core/ui/splash_screen.h"
#include "core/ui/menu_manager.h"
#include "core/ui/settings_manager.h"
#include "core/ui/global_settings.h"
#include "core/ui/track_settings.h"
#include "core/transport_control.h"
#include "core/midi/octave_shift.h"
#include "core/io/button_input_handler.h"
#include "core/io/joystick_input_handler.h"
#include "core/system_initializer.h"
#include "core/button_controller.h"
#include "core/midi_router.h"
#include "plugins/input/chord_mapping_input.h"
#include "plugins/input/piano_input.h"
#include "plugins/input/drum_pad_input.h"
#include "plugins/input/basic_midi_input.h"
#include "plugins/instruments/subtractive_synth.h"
#include "plugins/fx/delay_fx.h"
#if DEBUG_SCREEN_ENABLED
#include "core/ui/debug_screen.h"
#include "core/ui/debug_views.h"
#endif

using namespace daisy;
using namespace OpenChord;

// Use external USB logger for serial output (pins 36-37)
using ExternalLog = Logger<LOGGER_EXTERNAL>;


// Global hardware instance
DaisySeed hw;

// Global instances
VolumeManager volume_mgr;
AudioEngine audio_engine;
IOManager io_manager;
OpenChordMidiHandler midi_handler;
InputManager input_manager;
PowerManager power_mgr;

// Octave shift system
OctaveShift octave_shift;

// Global settings
GlobalSettings global_settings;
TrackSettings track_settings;

// Transport control
TransportControl transport_control;

// System (multi-track manager)
OpenChordSystem openchord_system;
ChordMappingInput* chord_plugin_ptr = nullptr;  // Keep reference for UI
PianoInput* piano_plugin_ptr = nullptr;  // Keep reference for UI

// UI system
SplashScreen splash_screen;
MainUI main_ui;
UIManager ui_manager;

#if DEBUG_SCREEN_ENABLED
DebugScreen debug_screen;

// Wrapper functions to pass global instances to render functions
void RenderSystemStatusWrapper(DisplayManager* display) {
    RenderSystemStatus(display, &io_manager);
}

void RenderInputStatusWrapper(DisplayManager* display) {
    RenderInputStatus(display, &input_manager, &io_manager);
}

void RenderAnalogStatusWrapper(DisplayManager* display) {
    RenderAnalogStatus(display, &io_manager);
}

void RenderAudioStatusWrapper(DisplayManager* display) {
    RenderAudioStatus(display, &audio_engine, &volume_mgr);
}

void RenderMIDIStatusWrapper(DisplayManager* display) {
    RenderMIDIStatus(display, &midi_handler);
}
#endif

void AudioCallback(AudioHandle::InputBuffer in, AudioHandle::OutputBuffer out, size_t size) {
    audio_engine.ProcessAudio(in, out, size);
}

int main(void) {
    // 1) Initialize hardware
    hw.Init();
    
    // 2) Initialize system using SystemInitializer
    SystemInitializer initializer;
    SystemInitializer::InitParams params;
    params.hw = &hw;
    params.io_manager = &io_manager;
    params.input_manager = &input_manager;
    params.volume_mgr = &volume_mgr;
    params.audio_engine = &audio_engine;
    params.midi_handler = &midi_handler;
    params.power_mgr = &power_mgr;
    params.ui_manager = &ui_manager;
    params.system = &openchord_system;
    params.global_settings = &global_settings;
    params.track_settings = &track_settings;
    params.transport_control = &transport_control;
    params.octave_shift = &octave_shift;
    params.splash_screen = &splash_screen;
    params.main_ui = &main_ui;
    params.chord_plugin_ptr = &chord_plugin_ptr;
    params.piano_plugin_ptr = &piano_plugin_ptr;
#if DEBUG_SCREEN_ENABLED
    params.debug_screen = &debug_screen;
#endif
    
    if (!initializer.Initialize(params)) {
        ExternalLog::PrintLine("System initialization failed!");
        while(1) {
            hw.DelayMs(1000);
        }
    }
    
    // Setup UI renderers (requires lambdas that capture global variables)
    DisplayManager* display = io_manager.GetDisplay();
    if (display && display->IsHealthy()) {
        // Register MainUI renderer with UI Manager
        ui_manager.SetMainUIRenderer([](DisplayManager* disp) {
            main_ui.Render(disp);
        });
        
        // Set octave UI check callback for chord plugin
        if (chord_plugin_ptr) {
            chord_plugin_ptr->SetOctaveUICheckCallback([]() -> bool {
                return ui_manager.IsOctaveUIActive();
            });
        }
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

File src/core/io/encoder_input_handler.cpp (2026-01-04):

#include "encoder_input_handler.h"
#include <cstring>
#include <cmath>

namespace OpenChord {

EncoderInputHandler::EncoderInputHandler()
    : digital_manager_(nullptr),
      mode_(EncoderMode::NAVIGATION),
      acceleration_enabled_(true),
      acceleration_threshold_(3),
      current_value_(0),
      prev_value_(0),
      current_delta_(0.0f),
      current_direction_(EncoderDirection::NONE),
      event_queue_head_(0),
      event_queue_tail_(0),
      event_queue_count_(0),
      rotation_steps_(0),
      last_rotation_time_(0) {
    
    memset(event_queue_, 0, sizeof(event_queue_));
}

EncoderInputHandler::~EncoderInputHandler() {
    digital_manager_ = nullptr;
}

void EncoderInputHandler::Init(::DigitalManager* digital_manager) {
    digital_manager_ = digital_manager;
    mode_ = EncoderMode::NAVIGATION;
    acceleration_enabled_ = true;
    acceleration_threshold_ = 3;
    
    current_value_ = 0;
    prev_value_ = 0;
    current_delta_ = 0.0f;
    current_direction_ = EncoderDirection::NONE;
    
    event_queue_head_ = 0;
    event_queue_tail_ = 0;
    event_queue_count_ = 0;
    
    rotation_steps_ = 0;
    last_rotation_time_ = 0;
    
    // Reset encoder in DigitalManager
    if (digital_manager_) {
        digital_manager_->ResetEncoder(0);
    }
}

void EncoderInputHandler::Update() {
    if (!digital_manager_) return;
    
    ProcessEncoder();
    ProcessButton();
}

void EncoderInputHandler::ProcessEncoder() {
    if (!digital_manager_) return;
    
    // Get encoder value and delta from DigitalManager
    int raw_value = digital_manager_->GetEncoderValue();
    float raw_delta = digital_manager_->GetEncoderDelta();
    
    // Determine direction
    if (raw_delta > 0.0f) {
        current_direction_ = EncoderDirection::CLOCKWISE;
    } else if (raw_delta < 0.0f) {
        current_direction_ = EncoderDirection::COUNTER_CLOCKWISE;
    } else {
        current_direction_ = EncoderDirection::NONE;
    }
    
    // Update value
    if (raw_value != prev_value_) {
        int delta = raw_value - prev_value_;
        uint32_t current_time = digital_manager_->GetCurrentTime();
        
        // Time-based velocity detection for acceleration
        if (acceleration_enabled_) {
            uint32_t time_delta = 0;
            if (last_rotation_time_ > 0) {
                time_delta = current_time - last_rotation_time_;
            }
            
            // If rotation direction matches, calculate velocity
            bool direction_match = (delta > 0 && rotation_steps_ >= 0) || 
                                  (delta < 0 && rotation_steps_ <= 0);
            
            if (direction_match && time_delta > 0 && time_delta < 150) {
                // Fast rotation detected (time_delta < 150ms)
                // Calculate velocity: faster rotation = smaller time_delta = larger multiplier
                // Normalize: 150ms = 1x, 75ms = 2x, 50ms = 3x, 30ms = 5x (capped)
                // Use a more gradual curve for better control
                float velocity_multiplier = 1.0f;
                if (time_delta < 30) {
                    velocity_multiplier = 5.0f;  // Very fast: 5x
                } else if (time_delta < 50) {
                    velocity_multiplier = 3.0f;  // Fast: 3x
                } else if (time_delta < 75) {
                    velocity_multiplier = 2.0f;  // Medium-fast: 2x
                } else if (time_delta < 100) {
                    velocity_multiplier = 1.5f;  // Slightly fast: 1.5x
                } else {
                    velocity_multiplier = 1.0f;  // Normal: 1x
                }
                
                // Apply velocity-based acceleration
                current_delta_ = static_cast<float>(delta) * velocity_multiplier;
                
                // Track rotation steps for direction consistency
                if (delta > 0) {
                    rotation_steps_ = (rotation_steps_ < 0) ? 1 : rotation_steps_ + 1;
                } else {
                    rotation_steps_ = (rotation_steps_ > 0) ? -1 : rotation_steps_ - 1;
                }
            } else {
                // Slow rotation or direction changed - no acceleration
                current_delta_ = static_cast<float>(delta);
                rotation_steps_ = (delta > 0) ? 1 : -1;
            }
            
            last_rotation_time_ = current_time;
        } else {
            // Acceleration disabled - use raw delta
            current_delta_ = static_cast<float>(delta);
            rotation_steps_ = 0;
            last_rotation_time_ = current_time;
        }
        
        current_value_ = raw_value;
        
        // Queue rotation event
        EncoderEvent event;
        event.type = EncoderEventType::ROTATED;
        event.delta = delta;
        event.value = current_value_;
        event.timestamp = current_time;
        QueueEvent(event);
        
        prev_value_ = current_value_;
    } else {
        current_delta_ = 0.0f;
        current_direction_ = EncoderDirection::NONE;
        
        // Reset rotation tracking if no movement for a while
        uint32_t current_time = digital_manager_->GetCurrentTime();
        if (last_rotation_time_ > 0 && (current_time - last_rotation_time_) > 500) {
            rotation_steps_ = 0;
            last_rotation_time_ = 0;
        }
    }
}

void EncoderInputHandler::ProcessButton() {
    if (!digital_manager_) return;
    
    // Check for button press (when implemented)
    // For now, encoder button is not connected, so this is a placeholder
    bool current_pressed = digital_manager_->IsEncoderButtonPressed();
    bool was_pressed = digital_manager_->WasEncoderButtonPressed();
    static bool prev_pressed = false;
    
    // Detect press event
    if (was_pressed || (!prev_pressed && current_pressed)) {
        EncoderEvent event;
        event.type = EncoderEventType::BUTTON_PRESSED;
        event.delta = 0;
        event.value = current_value_;
        event.timestamp = 0;
        QueueEvent(event);
    }
    
    // Detect release event
    if (prev_pressed && !current_pressed) {
        EncoderEvent event;
        event.type = EncoderEventType::BUTTON_RELEASED;
        event.delta = 0;
        event.value = current_value_;
        event.timestamp = 0;
        QueueEvent(event);
    }
    
    // Detect hold event
    if (current_pressed) {
        uint32_t hold_time = digital_manager_->GetEncoderButtonHoldTime();
        if (hold_time > 500 && !prev_pressed) { // 500ms threshold
            EncoderEvent event;
            event.type = EncoderEventType::BUTTON_HELD;
            event.delta = 0;
            event.value = current_value_;
            event.timestamp = 0;
            QueueEvent(event);
        }
    }
    
    prev_pressed = current_pressed;
}
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

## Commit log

2025-08-04 added back to main docs button on docs
2025-09-04 Fixed optocoupler requirements, using midi hub properly
    [analog_manager.cpp, audio_engine.cpp, main.cpp]
2025-12-20 Add TRS MIDI improvements, SD card support, and bugfixes
    [audio_engine.cpp, main.cpp]
2025-12-21 battery monitoring added
2025-12-21 Screen SPI init
2025-12-22 fixed button matrix, got screen working, input manager
    Also I FUCKING BROKE BOTH SHITTY ASS 20 DOLLAR SCREENS I HAD. NOW I HAVE TO REDO THE WHOLE TOP OF THE ENCLOSURE AND REWIRE EVERYTHING. AND of course I have to buy 2 more screens just hoping I won't break these too. FUCKING KILL ME.
    [analog_manager.cpp, encoder_input_handler.cpp, main.cpp]
2025-12-31 drum pad, bug fixes, bin file handling
    [main.cpp]
2025-12-31 pitch bend, mod wheel, UI cleanup
2025-12-31 Optimization, cleanup, battery monitor tweaks
2026-01-01 Midi transport, global settings, UX tweaks, bugfixes
    [analog_manager.cpp, audio_engine.cpp, main.cpp]
2026-01-02 Battery tweaks, major settings refactor
2026-01-02 battery charging, something else I forgot.
    sleepy
2026-01-03 UX improvements, first instrument and fx
    I broke usb midi :(
    [audio_engine.cpp, main.cpp, system_interface.cpp]
2026-01-04 encoder improvements
2026-09-12 Restructure the repo as an OpenChord family and start M1.
    Move the Daisy Seed prototype into archive/s1-daisy without deleting it, and add M1 goals plus an empty S1 placeholder so the MIDI product can start clean.
2026-09-12 Lock M1 around a portable engine and the Seed as a testbed.
    RP2040 on our PCB, archive frozen, proto pins taken from the working drivers.
2026-09-13 Fix low-key chords and keep voicings in the played octave.
    C1–G1 were swallowed as leftover pad notes, Place() pinned high roots near middle C, and knobs at 0 read as a hard stick lean. Extra notes now add without retriggering the triad.
    [main.cpp]
2026-09-13 Lock M1 as a free plugin plus a box, with Type and Degree modes.
    The engine has two hosts: hardware you buy and a plugin you don't. No pots on the enclosure; stick colors in both modes.
2026-09-13 Document M1 hand-build BOM, LP switches, and OLED footprint.
    Capture DigiKey/LCSC parts, Gateron matrix notes, locked OLED pinout, and KiCad libs so the board can be fabbed without paid assembly.
2026-09-14 Add tentative QT2120 touch strip to the M1 hardware plan.
    Document AT42QT2120-MMHR, electrode/soldermask wiring, and clean the BOM so the strum strip is a clear optional path without SoftPot.
2026-09-14 Plan M1 capacitive strip/wheel/system pads and direct GPIO keys.
    Drop the Alps stick and tactiles as defaults (keep as fallbacks), use two QT2120s on I2C0/I2C1, and wire the eight Gaterons one-GPIO-each with internal pull-ups so matrix diodes go away.
2026-09-15 Lock M1 connector/button parts and ship KiCad libs.
    Document IQS572 + QT2120, USB4105, SJ1-3523N, and EVQ-PUA02K as locked; add OpenChordM1 project + EasyEDA/Gateron/captouch libs; drop mode-button hunt leftover.
    [OpenChordM1.kicad_pcb, OpenChordM1.kicad_sch]
2026-09-15 Fix IQS572 pitch docs and align naming with locked parts.
    Correct 0.5 mm QFN pitch, drop the wrong 0.4 mm DIP adapter advice, and make Key/Shift + mode wording consistent.
2026-09-16 Lock M1 support BOM and add TLP2361 KiCad lib.
    Document flash/crystal/LDO/ESD/MIDI IN recipe, replace H11L1 with TLP2361, and save current schematic/PCB progress before support-part placement.
    [OpenChordM1.kicad_pcb, OpenChordM1.kicad_sch]
2026-09-18 Schematic and PCB update, hardware selections
    [OpenChordM1.kicad_pcb]
2026-09-19 Lock rev A to in-stock parts and sync the board docs.
    Use EVQPUC02K side buttons and W25Q32JVSSIQ flash, and add the Hroparts USB-C library so J1 can leave the out-of-stock GCT connector.
    [OpenChordM1.kicad_pcb, OpenChordM1.kicad_sch]
2026-09-19 Lock Hroparts USB-C as J1, qty-5 order carts, and JLCPCB gerbers.
    [OpenChordM1-DigiKey-qty5.csv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]
2026-09-19 Save USB-C pair routing and a board STEP for the enclosure.
    [OpenChordM1.kicad_pcb]
2026-09-19 Hang TRS bushings off the board edge and recenter the STEP.
    [OpenChordM1.kicad_pcb]
2026-09-19 Tidy silkscreen refs after sliding USB-C and TRS.
    [OpenChordM1.kicad_pcb]
2026-09-19 Lock rev A docs and gerbers to the HASL qty-5 order.
    [OpenChordM1-B_Cu.gbr, OpenChordM1-B_Mask.gbr, OpenChordM1-B_Paste.gbr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]
2026-09-25 Play Keys, Scale, and Drums from one surface so the board can share the plugin's engine.
    Lock the behavior and status docs to that surface, including the screen, Strum, and naming chords played in.
2026-09-25 Start the rev A firmware so it can compile before a board exists.
    USB MIDI, the keyswitches, and the OLED share the plugin engine. Upload stays refused, and the touch chips and TRS are not wired in yet.
2026-09-25 Send TRS MIDI through hardware UART0 and build for the 4 MB flash.
    GPIO0 and GPIO1 match the Type A jacks, and the image is no longer a generic 2 MB Pico.
    [board.h, main.cpp, trs.cpp]
2026-10-07 Bring up the M1 strip so a swipe plays, including optional scale, without treating idle noise as a finger.
    [main.cpp, oled.cpp]
2026-10-08 Play the strip from the QT2120 channel that actually rose.
    The chip's slider byte sticks at the left electrode and pegs before the right one, and waiting on the trackpad was stalling that same loop.
    [main.cpp, touch.cpp]
